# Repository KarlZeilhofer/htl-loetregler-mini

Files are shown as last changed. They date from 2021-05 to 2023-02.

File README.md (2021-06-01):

HTL Lötregler Mini
==================

Einfacher Regler für JBC Lötspitzen der Serie T210, T245 und T470, Weller RT-Spitzen und TS100-Spitzen sollten auch funktionieren.

Vorrangig SMD-Bauteile, Größe 3216. 
Bauteilauswahl für Handbestückung ohne SMD-Schablone optimiert

Design ist möglichst kostengünstig, speziell für Schüler-Budget. 

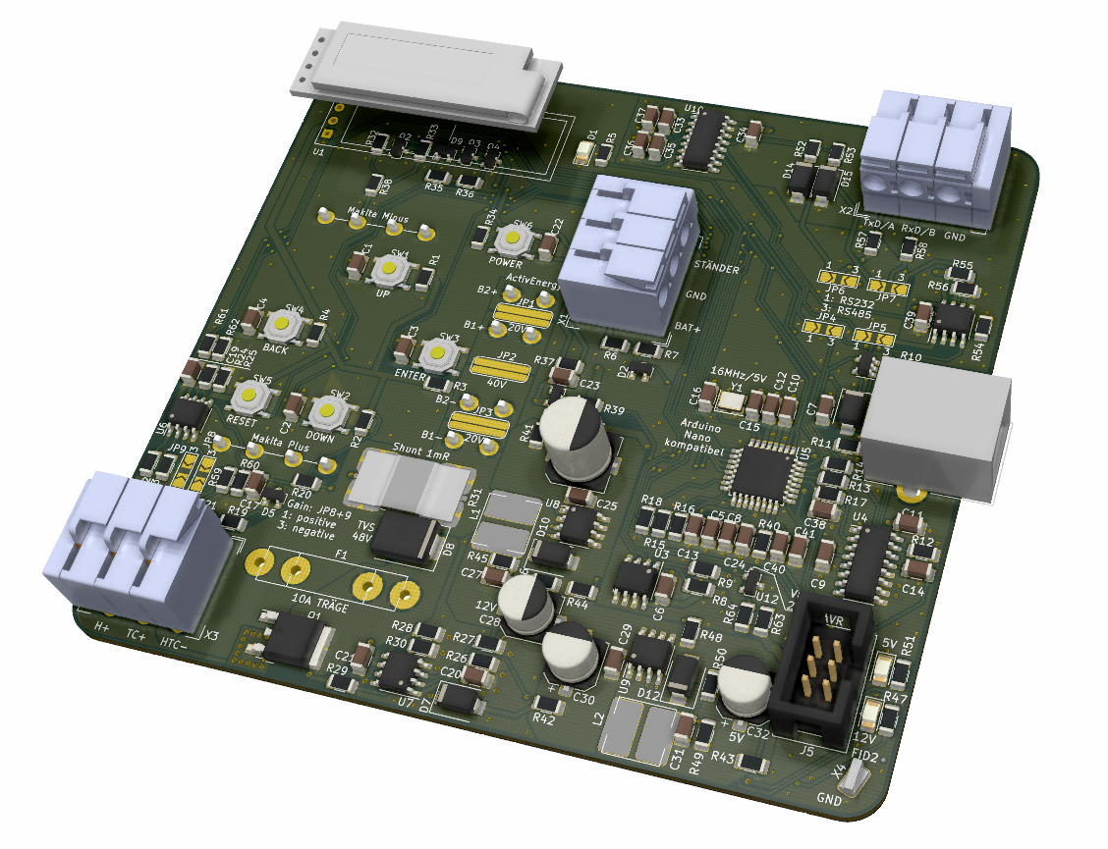
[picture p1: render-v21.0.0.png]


# Merkmale:
## Controller
* ATmega328, Kompatibel zu Arduino Nano
* 5V, 16MHz
* externe 2.5V Spannungsreferenz für ADC

## Stromversorgung
* Spannungsversorgung: 15 bis 48V, Akku oder Netzteil
* Tiefentladeschutz
* 10A Schmelzsicherung
* 48V TVS-Schutzdiode
* Ein-/Aus-Taster
* Schaltregler von Vin auf 12V und 5V
* 6.3 mm Flachsteckverbinder für die direkte Kontaktierung von 18V Makita Akkus, oder Hofer ActivEnergy Akkus mit 20 oder 40V. 

## Leistungsteil
* Highside N-Kanal MOS-FET: 80V, 10mR (geringe Verlustleistung, hohe Spannungsfestigkeit)
* zugehöriger Gatetreiber: notwendig für N-Kanal MOS-FET

## Sensorik
* Messverstärker zur Temperaturmessung der Lötspitze (24 µV/K)
* Spannungsmessung der Versorgung
* Messung der Leiterplattentemperatur
* Strommessung des Heizelements über 1mR-Shunt

## Benutzerschnittstelle
* OLED Display mit 128x32 Pixel, 23mm Diagonale
* 4 Bedientaster (Rauf, Runter, Enter, Zurück)

## Kommunikation
* Arduino USB
* AVR ISP
* Wahlweise
  * RS232
  * oder RS485 zur Kommunikation mit einem Steuerbaren Netzgerät (12, 24, 48V).

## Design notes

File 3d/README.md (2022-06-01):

3D-Druck Lötregler Mini
============

# Schichthöhe
Die Teile sind optimiert für 0.4mm Düsendurchmesser. 

# Werkstoff
Alle Teile sind in PETG gefertigt. 

Das Griffstück wäre in PC (Polycarbonat) interessant, da es nochmals um ca. 20°C temperaturbestänidger ist. 

# Gehäuse
Das Gehäuse besteht aus dem Deckel, der Wand und dem Boden. 
Beim Boden gibt es 2 Varianten: Für Activ Energy Akkus vom Hofer und für Makita Akkus. 
Entsprechend gibt es 2 Batterieaufnahmen, die mit dem Boden verklebt werden müssen. 
Für Makita empfiehlt es sich, nur die rechten Flachstecker in der Platine zu bestücken, da sich ansonsten die linken Flachstecker bei manchen Makita-Akkus beim Abziehen des Akkus in den Federkontakten im Akku verhaken. 

Die Gehäuseteile sind für 0.2mm Schichthöhe optimiert und müssen auch in dieser gedruckt werden. 

# Griffstück
Das Griffstück besteht insgesamt aus 13 Teilen, wovon 3 aus Metall sind. 
## 0.1mm Schichthöhe
  * 2 Stk griffstück_halbschale-hex_v2.stl
  * 2 Stk griffstück_halbschale-rund_v2.stl

## 0.25mm Schichthöhe
  * 2 Stk griffstück_isolator_htc-_h+_v2.2.stl
  * 1 Stk griffstück_isolator_tc+.stl
  * 1 Stk fingerkuppenring_v2.2.stl
  * 1 Stk endring_v2.1.stl
  * 1 Stk mittenring_v2.1.stl

## Edelstahl
  * 3 Stk Federkontakte

Es empfhielt sich, das Griffstück z.B. mit Polycarbonat zu drucken.

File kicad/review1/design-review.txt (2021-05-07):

Designreview:

Footprint größe
Pin-Raster
Bohrlöcherdurchmesser
Bohrlöcherposition/-abstand

Verlustleistung Widerstand
Kondensatoren: Spannungsfestigkeit
Bauform Kondensator

LED-Strom

ICs: 
Pinnamen
Pinnummern
Gehäuseform zur exakten Bestellnummer/Herstellerteilenummer

TVS-Spannungen mit Absolute Maximum Ratings vergleichen

Busverbindungen
Signalrichtungen kontrollieren
100nF Stützkondensatoren bei jedem Chip

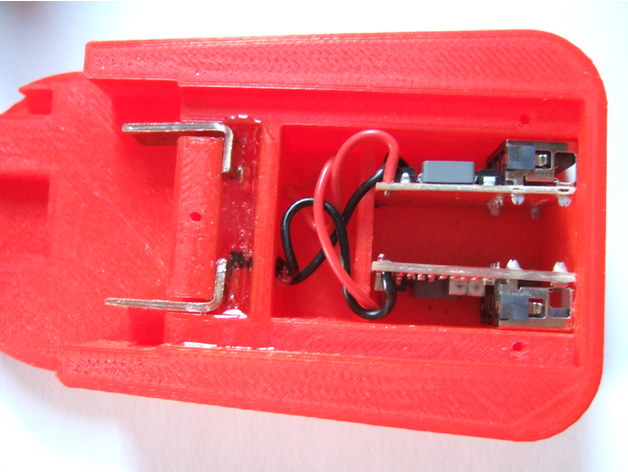
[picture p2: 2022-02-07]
3d/batterie-adapter/bosch-hobby-18v/images/8edf7b6a57a885e6059f40bedc9dee4b_preview_featured.JPG

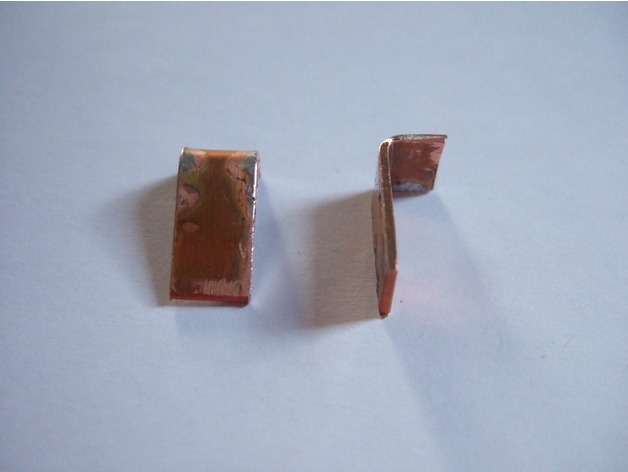
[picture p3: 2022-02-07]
3d/batterie-adapter/bosch-hobby-18v/images/e7cfda0443ac3e1c00166151be815f59_preview_featured.JPG

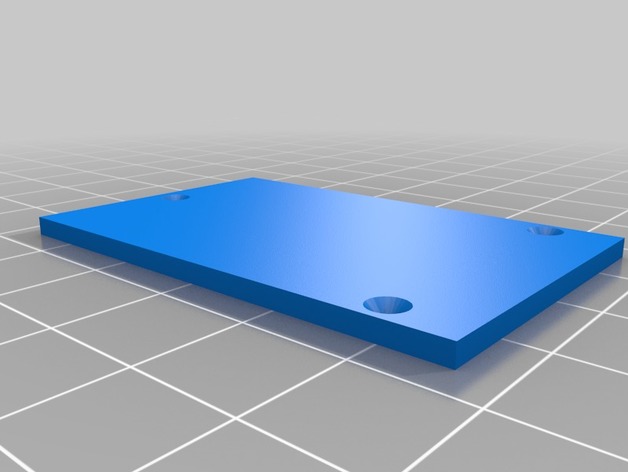
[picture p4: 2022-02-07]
3d/batterie-adapter/bosch-hobby-18v/images/c6485c41a04f16e561d70e03e1cd979a_preview_featured.jpg

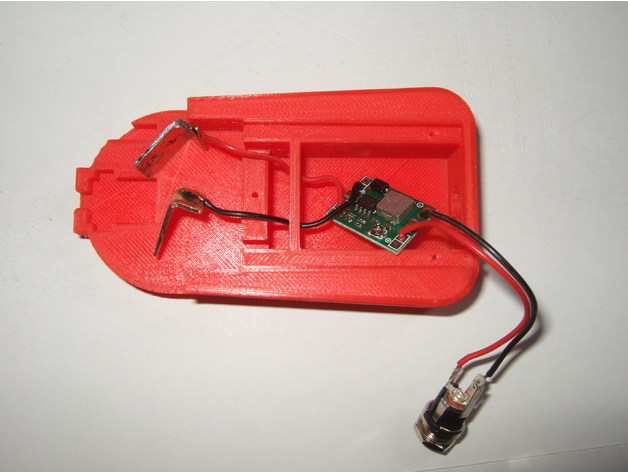
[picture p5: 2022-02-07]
3d/batterie-adapter/bosch-hobby-18v/images/e281460a45876c7f72f765fe44a80ca8_preview_featured.JPG

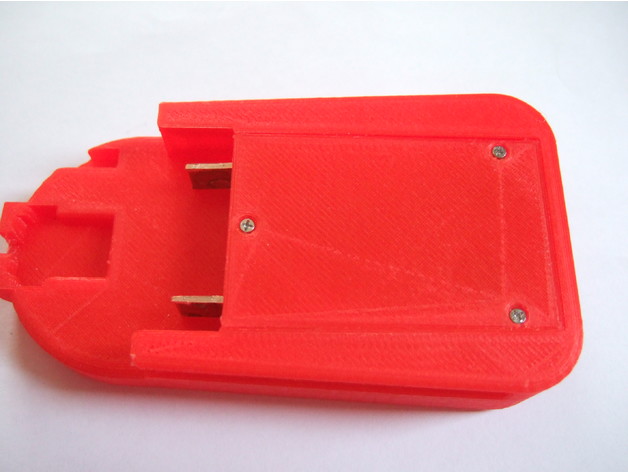
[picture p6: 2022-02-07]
3d/batterie-adapter/bosch-hobby-18v/images/b4b1a557884dc751f94c1e680981e6fe_preview_featured.JPG

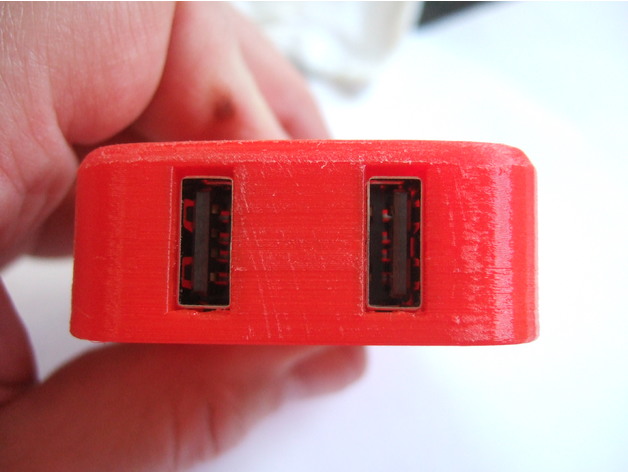
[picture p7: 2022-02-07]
3d/batterie-adapter/bosch-hobby-18v/images/e0b086893cdca43c442f52685e246c57_preview_featured.JPG

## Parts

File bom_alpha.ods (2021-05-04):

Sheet: Sheet1
Column1 | Column2 | Column3 | Column4 | Column5 | Column6 | Column7 | Column8 | Column9 | Column10 | Column11 | Column12 | Column13 | Column14 | Column15 | Quantity | Preis | Column18 | Column19 | Column20 | Column21 | Column22 | Column23 | Column24
Item2 | PCB, 1 Layer, 35um Cu, 1.6mm, ca. 100x110 | htl_virtual:Virtual-Item | ~ | Custom2 | Multi-CB | BAV99 | Multi-CB | 70V 200mA 1.25V @ 150mA 6ns SOT-23 Switching Diode |  |  | 3.71 | 100 | https://lcsc.com/product-detail/Switching-Diode_BAV99-chip0-23_C181111.html |  | 1 | 3.71 | 5.12
U1 | OLED-128x32-Module | htl_modules:OLED-128x32 | ~ | OLED_128x64_white | AliExpress, SAMIORE Store |  |  | OLED, 128x32, 23mm, I2C, 3.3/5V, weiß, SSD1306 |  |  | 1.38 | 100 | https://www.aliexpress.com/item/32672229793.html?spm=a2g0s.9042311.0.0.202b4c4d7Uzd2y |  | 1 | 1.38 | 1.90
U5 | ATmega328P-AU | Package_QFP:TQFP-32_7x7mm_P0.8mm | http://ww1.microchip.com/downloads/en/DeviceDoc/ATmega328_P%20AVR%20MCU%20with%20picoPower%20Technology%20Data%20Sheet%2040001984A.pdf | ATmega328 | MKZ | ATmega328P-AU | Microchip (ATMEL) | AVR Mikrocontroller, 16MHz, 32kByte Flash, 2kByte RAM, 1kByte EEPROM |  |  | 1 | 1 |  |  | 1 | 1 | 1.38
> C28, C30, C32 | 100u/25V | Capacitor_SMD:CP_Elec_6.3x5.9 | ~ | C320569 | LCSC | SVZ1EM101E06E00RAXXX | AISHI | 100uF ±20% 25V 6.3mm 6mm 2000hrs @ 105℃ -55℃~+105℃ SMD,6.3x6mm Solid Polymer Electrolytic Capacitor |  |  | 0.1485 | 30 | https://lcsc.com/product-detail/DC-DC-Converters_XLSEMI-XL7005A_C50848.html |  | 3 | 0.4455 | 0.61
> U8, U9 | XL7005A | htl_smd:SOIC-8-1EP_3.9x4.9mm_P1.27mm_EP2.514x3.2mm_ThermalVias | ~ | C50848 | LCSC | XL7005A | XLSEMI | 80V 400mA SOP-8_EP_150mil DC-DC Converters |  |  | 0.204 | 100 | https://lcsc.com/product-detail/DC-DC-Converters_XLSEMI-XL7005A_C50848.html |  | 2 | 0.408 | 0.56
> J1-J3 | ... | Connector_Phoenix_MSTB:PhoenixContact_MSTBA_2,5_3-G-5,08_1x03_P5.08mm_Horizontal | ~ | C475145 | LCSC | SLH0704S470MTT | Sunltech Tech | 3 poles, 5.08mm, 15A 250V AWG14~22 1.5mm² P=5.08mm Spring Clamp System Terminal Block |  |  | 0.1347 | 100 | https://lcsc.com/product-detail/Power-Inductors_Sunltech-Tech-SLH0704S470MTT_C216198.html |  | 3 | 0.4041 | 0.56
> J6-J13 | ... | htl_connectors:Faston_Tab_6.3mm_vertical | ~ | VT FS-P 6,35 | Reichelt | 03866.A68 | Vogt | Faston Flachstecker vertikal 6.3mm für Leiterplattenmontage |  |  | 0.042 | 1 |  |  | 8 | 0.336 | 0.46
U6 | GS8332-SR | Package_SO:SO-8_3.9x4.9mm_P1.27mm | http://www.ti.com/lit/ds/symlink/lm2904-n.pdf | C157713 | LCSC | GS8332-SR | Gainsil | Zero-Drift 2 2.1V ~ 5.5V 20uA 350kHz 0.2 V/us SOP-8_150mil Precision OpAmps |  |  | 0.3016 | 100 | https://lcsc.com/product-detail/Precision-OpAmps_Gainsil-GS8332-SR_C157713.html |  | 1 | 0.3016 | 0.42
R31 | 1mR/7W/1% | htl_smd:Shunt-15.2x7.6mm | ~ | C481499 | LCSC | FN31X103K500PXG | PSA(Prosperity Dielectrics) | 10nF ±10% 50V X7R Multilayer Ceramic Capacitors MLCC |  |  | 0.2596 | 100 |  |  | 1 | 0.2596 | 0.36
U4 | CH340C | Package_SO:SOIC-16_3.9x9.9mm_P1.27mm | http://www.datasheet5.com/pdf-local-2195953 | C84681 | LCSC | CH340C | WCH(Jiangsu Qin Heng) | USB-UART with internal clock |  |  | 0.239 | 100 | https://lcsc.com/product-detail/USB-ICs_WCH-Jiangsu-Qin-Heng-CH340C_C84681.html | dnf | 1 | 0.239 | 0.33
Q1 | KND3508A | Package_TO_SOT_SMD:TO-252-2 | ~ | C116513 | LCSC | KND3508A | KIA Semicon Tech | 100uF ±20% 25V 6.3mm 6mm 2000hrs @ 105℃ -55℃~+105℃ SMD,6.3x6mm Solid Polymer Electrolytic Capacitor |  |  | 0.226 | 100 | https://lcsc.com/product-detail/MOSFET_KIA-Semicon-Tech-KND3508A_C116513.html |  | 1 | 0.226 | 0.31
Q5 | ZXMP10A13FTA | Package_TO_SOT_SMD:SOT-23 | http://assets.nexperia.com/documents/data-sheet/BSS84.pdf | C50185 | LCSC | ZXMP10A13FTA | Diodes | P-Channel -100V 600mA 4V @ 250uA 1Ω @ 600mA,10V 625mW SOT-23(SOT-23-3) MOSFET |  |  | 0.2191 | 100 | https://lcsc.com/product-detail/Cartridge-Fuses_Littelfuse-0618010-MXP_C142673.html |  | 1 | 0.2191 | 0.30
U7 | PN7006A | Package_SO:SOIC-8_3.9x4.9mm_P1.27mm |  | C414194 | LCSC |  |  | SOP-8 half bridge Driver, 300V, 450mA |  |  | 0.2188 | 100 | https://lcsc.com/product-detail/Full-bridge-half-bridge-Driver_Wuxi-Chipown-Micro-electronics-PN7006ASEC-R1_C414194.html |  | 1 | 0.2188 | 0.30
U10 | MAX3232 | Package_SO:SOIC-16_3.9x9.9mm_P1.27mm | https://datasheets.maximintegrated.com/en/ds/MAX3222-MAX3241.pdf | C434486 | LCSC | MAX3232EIM/TR | HGSEMI | RS232 - UART Umsetzer, 3V3 oder 5V |  |  | 0.188404 | 100 | https://lcsc.com/product-detail/Uncategorized_HGSEMI-MAX3232EIM-TR_C434486.html |  | 1 | 0.188404 | 0.26
> L1, L2 | 47u/1A | Inductor_SMD:L_7.3x7.3_H4.5 | ~ | C216198 | LCSC | SLH0704S470MTT | Sunltech Tech | 47uH ±20% 1A 266mΩ SMD,7.3x7.3x4.5mm |  |  | 0.085 | 100 | https://lcsc.com/product-detail/Power-Inductors_Sunltech-Tech-SLH0704S470MTT_C216198.html |  | 2 | 0.17 | 0.23
Item1 | Stencil, 120um, 25mm Rand, Edelstahl | htl_virtual:Virtual-Item | ~ | Custom1 | Multi-CB | 2N7002 | Multi-CB | N-Channel 60V 115mA 2.5V @ 250uA 5Ω @ 500mA,10V 225mW SOT-23(SOT-23-3) MOSFET |  |  | 0.1656 | 100 | https://lcsc.com/product-detail/MOSFET_Guangdong-Hottech-2N7002_C181082.html |  | 1 | 0.1656 | 0.23
> C1-C6, C8, C9, C11, C14, C17, C19, C33-C37 | 100n | Capacitor_SMD:C_1206_3216Metric | ... | C464972 | LCSC | FN31X104K500PXG | PSA(Prosperity Dielectrics) | 100nF ±10% 50V X7R Multilayer Ceramic Capacitors MLCC |  |  | 0.0093 | 500 | ... |  | 17 | 0.1581 | 0.22
> R1-R4, R6, R7, R21, R30, R32-R34, R39, R49 | 10k | Resistor_SMD:R_1206_3216Metric | ~ | C118075 | LCSC | GS8332-SR | Gainsil | SOP-8 half bridge Driver, 300V, 450mA |  |  | 0.01 | 100 | https://lcsc.com/product-detail/Full-bridge-half-bridge-Driver_Wuxi-Chipown-Micro-electronics-PN7006ASEC-R1_C414194.html |  | 13 | 0.13 | 0.18
D8 | SMCJ48A | Diode_SMD:D_SMC | ~ | C310056 | LCSC | KND3508A | KIA Semicon Tech | TVS-Diode, 1500W, 77.4V, 19.4A |  |  | 0.12 | 100 | https://lcsc.com/product-detail/TVS_Brightking-Elec-TAIWAN-SMCJ48A_C310056.html |  | 1 | 0.12 | 0.17
> C7, C10, C12, C13, C21 | 1u | Capacitor_SMD:C_1206_3216Metric | ~ | C1848 | LCSC | CL31B105KBHNNNE | Samsung | 1uF ±10% 50V X7R Multilayer Ceramic Capacitors MLCC |  |  | 0.0225 | 100 | ... |  | 5 | 0.1125 | 0.16
U3 | NST175 | Package_SO:SO-8_3.9x4.9mm_P1.27mm | ~ | C967852 | LCSC | SS210A-W | ZHIDE | digital temperature sensor, +/-0.5°C, I2C |  |  | 0.096 | 10 | https://lcsc.com/product-detail/Temperature-Sensors_NOVOSENSE-NST175-QSPR_C967852.html |  | 1 | 0.096 | 0.13
Y1 | 16MHz | Crystal:Crystal_SMD_3225-4Pin_3.2x2.5mm | ~ | C357882 | LCSC | JYXT32S4-016.00000-93C4C0 | Guangzhou Jingyou Electronic Tech | 16MHz ±10ppm 12pF 40Ω SMD-3225 SMD Crystal Resonators |  |  | 0.0884 | 50 |  |  | 1 | 0.0884 | 0.12
> R8-R10, R35, R46, R47, R50, R51 | 3k3 | Resistor_SMD:R_1206_3216Metric | ~ | C229599 | LCSC | FN31X104K500PXG | PSA(Prosperity Dielectrics) | 100nF ±10% 50V X7R Multilayer Ceramic Capacitors MLCC |  |  | 0.01 | 500 | ... |  | 8 | 0.08 | 0.11
J4 | USB_B | Connector_USB:USB_B_Lumberg_2411_02_Horizontal | ~ | C46392 | LCSC | 921-111A1010D10200 | Jing Extension of the Electronic Co. | USB - Type B Female USB 2.0 4 Through Hole USB Connectors |  |  | 0.0777 | 5 |  |  | 1 | 0.0777 | 0.11
J5 | AVR ISP | Connector_IDC:IDC-Header_2x03_P2.54mm_Vertical | ~ | C132438 | LCSC |  |  | Wannenstecker 2x3 Pins, 2.54mm Raster, vertikal |  |  | 0.0698 | 50 |  |  | 1 | 0.0698 | 0.10
C26 | 100u/63V | Capacitor_SMD:CP_Elec_8x10 | ~ | C487384 | LCSC | VKMD1001J101MV | Ymin | 100uF ±20% 63V 8mm 10mm 902mA @ 100kHz 10000hrs @ 105℃ -55℃~+105℃ SMD,8x10mm Aluminum Electrolytic Capacitors |  |  | 0.0698 | 150 | ... |  | 1 | 0.0698 | 0.10
> D4, D7, D10, D12 | SS210 | Diode_SMD:D_SMA | ~ | C2683692 | LCSC | SS210A-W | ZHIDE | 100V 2A 850mV @ 2A SMA(DO-214AC) Schottky Barrier Diodes |  |  | 0.0155 | 200 | ... |  | 4 | 0.062 | 0.09
> SW1-SW6 | ... | htl_smd:SW_Push_5.1mm_H1.5mm | ~ | C318884 | LCSC | TS-1187A-B-A-B | XKB Connectivity | SPST 50mA @ 12VDC Vertical Round Button 160gf SMD Tactile Switches |  |  | 0.01 | 500 | https://lcsc.com/product-detail/Tactile-Switches_XKB-Connectivity-TS-1187A-B-A-B_C318884.html |  | 6 | 0.06 | 0.08
Item4 | Sicherung, 5x20, 10A, träge | htl_virtual:Virtual-Item | ~ | C142673 | LCSC | 0618010.MXP | Littelfuse | Glass Tube Fuse Delayed blow/Slow Blow 10A 250V Tube,5.2x20mm Cartridge Fuses |  |  | 0.0544 | 100 | https://lcsc.com/product-detail/Cartridge-Fuses_Littelfuse-0618010-MXP_C142673.html | ... | 1 | 0.0544 | 0.08
> D14, D15 | SMAJ8.0CA | Diode_SMD:D_SMA | ~ | C908814 | LCSC | SMAJ8.0CA | GOODWORK | Bidirectional 8V 8.89V 13.6V 29.4A SMA(DO-214AC) TVS |  |  | 0.0243 | 100 | https://lcsc.com/product-detail/Pre-ordered-transistors_GOODWORK-SMAJ8-0CA_C908814.html |  | 2 | 0.0486 | 0.07
> C15, C16 | 12p | Capacitor_SMD:C_1206_3216Metric | ~ | C113882 | LCSC | CC1206JRNPO9BN120 | YAGEO | 12pF NP0 Keramikkonensator |  |  | 0.024 | 20 |  |  | 2 | 0.048 | 0.07
> C20, C24 | 10u/16V | Capacitor_SMD:C_1206_3216Metric | ~ | C47971 | LCSC | CL31B106KOHNNNE | Samsung | 10uF ±10% 16V X7R Multilayer Ceramic Capacitors MLCC |  |  | 0.0233 | 100 |  |  | 2 | 0.0466 | 0.06
> R5, R11, R13, R17, R20, R26-R28, R36, R38, R40 | 1k | Resistor_SMD:R_1206_3216Metric | ... | C104601 | LCSC | RTT03101JTP | RALEC | 1kΩ ±5% 0.25W ±100ppm/℃ 1206 Chip Resistor |  |  | 0.0042 | 50 | ... |  | 11 | 0.0462 | 0.06
> R12, R14-R16, R18, R23, R25, R29, R44, R48, R52, R53 | 100R | Resistor_SMD:R_1206_3216Metric | ... | C113307 | LCSC | RC1206JR-07100RL | YAGEO | 100Ω ±5% 0.25W ±100ppm/℃ 1206 Chip Resistor |  |  | 0.0037 | 500 | ... |  | 12 | 0.0444 | 0.06
U2 | 74LVC1G125 | Package_TO_SOT_SMD:SOT-23-5 | http://www.ti.com/lit/sg/scyt129e/scyt129e.pdf | C23654 | LCSC |  |  | digital temperature sensor, +/-0.5°C, I2C |  |  | 0.044 | 100 | https://lcsc.com/product-detail/Temperature-Sensors_NOVOSENSE-NST175-QSPR_C967852.html |  | 1 | 0.044 | 0.06
> R22, R24, R45 | 30k | Resistor_SMD:R_1206_3216Metric | ~ | C137314 | LCSC | VKMD1001J101MV | Ymin | 100uF ±20% 63V 8mm 10mm 902mA @ 100kHz 10000hrs @ 105℃ -55℃~+105℃ SMD,8x10mm Aluminum Electrolytic Capacitors |  |  | 0.01 | 150 |  |  | 3 | 0.03 | 0.04
> R41-R43 | 1R | Resistor_SMD:R_1206_3216Metric | ~ | C17928 | LCSC | SMAJ8.0CA | GOODWORK | Bidirectional 8V 8.89V 13.6V 29.4A SMA(DO-214AC) TVS |  |  | 0.01 | 100 | https://lcsc.com/product-detail/Pre-ordered-transistors_GOODWORK-SMAJ8-0CA_C908814.html |  | 3 | 0.03 | 0.04
> C27, C31 | 33n | Capacitor_SMD:C_1206_3216Metric | ~ | C309052 | LCSC | TCC1206X7R333K500DT | CCTC | P-Channel -100V 600mA 4V @ 250uA 1Ω @ 600mA,10V 625mW SOT-23(SOT-23-3) MOSFET |  |  | 0.0144 | 50 |  |  | 2 | 0.0288 | 0.04
> C25, C29 | 100n/100V | Capacitor_SMD:C_1206_3216Metric | ~ | C1945 | LCSC | CL31B104KCFNNNE | Samsung Electro-Mechanics | 100nF ±10% 100V X7R Multilayer Ceramic Capacitors MLCC |  |  | 0.014 | 200 |  |  | 2 | 0.028 | 0.04
> F1, Item3 | Clip 20x5 | ... | ~ | C182320 | LCSC | LS-502 | Shenzhen lanson Elec | Sicherungshalter, 2 Stück pro Sicherung |  |  | 0.0132 | 200 | https://lcsc.com/product-detail/Fuse-Holders_Shenzhen-lanson-Elec-LS-502_C182320.html |  | 2 | 0.0264 | 0.04
> D2, D5, D6 | BAV99 | Package_TO_SOT_SMD:SOT-23 | https://assets.nexperia.com/documents/data-sheet/BAV99_SER.pdf | C181111 | LCSC | BAV99 | Guangdong Hottech | 70V 200mA 1.25V @ 150mA 6ns SOT-23 Switching Diode |  |  | 0.0073 | 500 | https://lcsc.com/product-detail/Switching-Diode_BAV99-chip0-23_C181111.html |  | 3 | 0.0219 | 0.03
> C18, C23 | 10n | Capacitor_SMD:C_1206_3216Metric | ~ | C525316 | LCSC | FN31X103K500PXG | PSA(Prosperity Dielectrics) | 10nF ±10% 50V X7R Multilayer Ceramic Capacitors MLCC |  |  | 0.0106 | 500 | ... |  | 2 | 0.0212 | 0.03
> D3, D11, D13 | grün | LED_SMD:LED_1206_3216Metric | ~ | C965825 | LCSC | RC1206JR-07100RL | YAGEO | 100Ω ±5% 0.25W ±100ppm/℃ 1206 Chip Resistor |  |  | 0.0067 | 50 | https://lcsc.com/product-detail/Pre-ordered-Products_XINGLIGHT-XL-3216UGC_C965825.html |  | 3 | 0.0201 | 0.03
> R19, R37 | 100k | Resistor_SMD:R_1206_3216Metric | ~ | C269765 | LCSC |  |  | TVS-Diode, 1500W, 77.4V, 19.4A |  |  | 0.01 | 100 | https://lcsc.com/product-detail/TVS_Brightking-Elec-TAIWAN-SMCJ48A_C310056.html |  | 2 | 0.02 | 0.03
> Q3, Q4 | MMBT3904 | Package_TO_SOT_SMD:SOT-23 | https://www.fairchildsemi.com/datasheets/2N/2N3904.pdf | C382281 | LCSC |  |  | Wannenstecker 2x3 Pins, 2.54mm Raster, vertikal |  |  | 0.0097 | 50 | https://lcsc.com/product-detail/Transistors-NPN-PNP_KEXIN-MMBT3904_C382281.html |  | 2 | 0.0194 | 0.03
D9 | 4V7 | Diode_SMD:D_SOT-23_ANK | https://diotec.com/tl_files/diotec/files/pdf/datasheets/bzx84c2v4.pdf | C12727 | LCSC | CC1206JRNPO9BN120 | YAGEO | 4.7V 225mW 3uA @ 2V SOT-23(SOT-23-3) Zener Diodes |  |  | 0.014 | 50 |  |  | 1 | 0.014 | 0.02
C22 | 1n/100V | Capacitor_SMD:C_1206_3216Metric | ~ | C398254 | LCSC | C1206X102K101T | IHHEC(HOLY STONE ENTERPRISE CO., LTD) | 1nF ±10% 100V X7R Multilayer Ceramic Capacitors MLCC |  |  | 0.0123 | 50 | https://lcsc.com/product-detail/Tactile-Switches_XKB-Connectivity-TS-1187A-B-A-B_C318884.html |  | 1 | 0.0123 | 0.02
Q2 | 2N7002 | Package_TO_SOT_SMD:SOT-23 | https://www.fairchildsemi.com/datasheets/2N/2N7002.pdf | C181082 | LCSC | 2N7002 | Guangdong Hottech | N-Channel 60V 115mA 2.5V @ 250uA 5Ω @ 500mA,10V 225mW SOT-23(SOT-23-3) MOSFET |  |  | 0.0122 | 50 | https://lcsc.com/product-detail/MOSFET_Guangdong-Hottech-2N7002_C181082.html |  | 1 | 0.0122 | 0.02
D1 | rot | LED_SMD:LED_1206_3216Metric | ~ | C965823 | LCSC | CH340C | WCH(Jiangsu Qin Heng) | LED, green, SMD3216 |  |  | 0.0079 | 50 | https://lcsc.com/product-detail/USB-ICs_WCH-Jiangsu-Qin-Heng-CH340C_C84681.html |  | 1 | 0.0079 | 0.01
> FID1, FID2 | Fiducial | htl_mechanical:paste-fiducial | ~ | NAP1 | NAP | 0618010.MXP | Not a Part | Glass Tube Fuse Delayed blow/Slow Blow 10A 250V Tube,5.2x20mm Cartridge Fuses |  |  | 0 | 100 | https://lcsc.com/product-detail/Cartridge-Fuses_Littelfuse-0618010-MXP_C142673.html |  | 2 | 0 | 0.00
> H1-H4 | MountingHole | htl_mechanical:mountinghole_d4mm_R5mm | ~ | NAP2 | NAP | NAP | NAP | Not a Part |  |  | 0 | 100 | https://lcsc.com/product-detail/Precision-OpAmps_Gainsil-GS8332-SR_C157713.html |  | 4 | 0 | 0.00
> JP1-JP3 | ... | Jumper:SolderJumper-2_P1.3mm_Open_RoundedPad1.0x1.5mm | ~ | NAP3 | NAP | 921-111A1010D10200 | Jing Extension of the Electronic Co. | TVS-Diode, 1500W, 77.4V, 19.4A |  |  | 0 | 100 | https://lcsc.com/product-detail/TVS_Brightking-Elec-TAIWAN-SMCJ48A_C310056.html |  | 3 | 0 | 0.00

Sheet: Sheet2
LCSC | Stück | Stück für 10 PCBs
C104601 | 11 | 110
C113307 | 12 | 120
C113882 | 2 | 20
C116513 | 1 | 10
C118075 | 13 | 130
C12727 | 1 | 10
C132438 | 1 | 10
C137314 | 3 | 30
C142673 | 1 | 10
C157713 | 1 | 10
C17928 | 3 | 30
C181082 | 1 | 10
C181111 | 3 | 30
C182320 | 2 | 20
C1848 | 5 | 50
C1945 | 2 | 20
C216198 | 2 | 20
C229599 | 8 | 80
C23654 | 1 | 10
C2683692 | 4 | 40
C269765 | 2 | 20
C309052 | 2 | 20
C310056 | 1 | 10
C318884 | 6 | 60
C320569 | 3 | 30
C357882 | 1 | 10
C382281 | 2 | 20
C398254 | 1 | 10
C414194 | 1 | 10
C434486 | 1 | 10
C46392 | 1 | 10
C464972 | 17 | 170
C475145 | 3 | 30
C47971 | 2 | 20
C481499 | 1 | 10
C487384 | 1 | 10
C50185 | 1 | 10
C50848 | 2 | 20
C525316 | 2 | 20
C84681 | 1 | 10
C908814 | 2 | 20
C965823 | 1 | 10
C965825 | 3 | 30
C967852 | 1 | 10

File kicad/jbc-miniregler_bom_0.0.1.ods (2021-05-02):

Component | Description | Part | References | Value | Footprint | Quantity Per PCB | Datasheet | DistOrderNr | Distributor | Notes | PriceEUR | PriceForQty | ManPartNr | Manufacturer | fit_field | Weblink | PreisGesBrutto
21 | Virtual Item for accessories which should be listed in the BOM | Item | Item2 | PCB, 1 Layer, 35um Cu, 1.6mm, ca. 100x110 | Virtual-Item | 1 | ~ | Custom | Multi-CB |  | 3.71 | 100 |  | Multi-CB |  |  | 512
1 | Arduino Nano v3.x | Arduino_Nano_v3.x | A1 | Arduino_Nano_v3.x | Arduino_Nano | 1 | http://www.mouser.com/pdfdocs/Gravitech_Arduino_Nano3_0.pdf | 232861246013 | eBay | Arduino Nano v3.x | 2.6 | 50 |  |  |  |  | 359
48 |  | OLED-128x32-Module | U1 | OLED-128x32-Module | OLED-128x32 | 1 |  | OLED_128x64_white | AliExpress, SAMIORE Store | OLED, 128x32, 23mm, I2C, 3.3/5V, weiß, SSD1306 | 1.38 | 100 |  |  |  | https://www.aliexpress.com/item/32672229793.html?spm=a2g0s.9042311.0.0.202b4c4d7Uzd2y | 190
7 | Polarized capacitor | CP | C17 C21 | 100u/25V | TODO | 2 | ~ | C454667 | LCSC | 100uF ±20% 25V 7.7mm 8mm 2A @ 100kHz 30mΩ @ 100kHz 10000hrs @ 105℃ -55℃~+105℃ SMD,7.7x8mm Solid Polymer Electrolytic Capacitor | 0.4258 | 100 | EEHZA1E101XV | Panasonic |  |  | 118
50 | Tiefsetzsteller, 80V, 400mA, 85% Wirkungsgrad | XL7005A | U6 U7 | XL7005A | SOIC-8-1EP_3.9x4.9mm_P1.27mm_EP2.514x3.2mm_ThermalVias | 2 |  | C50848 | LCSC | 80V 400mA SOP-8_EP_150mil DC-DC Converters | 0.204 | 100 | XL7005A | XLSEMI |  | https://lcsc.com/product-detail/DC-DC-Converters_XLSEMI-XL7005A_C50848.html | 56
45 | Low-Power, Dual Operational Amplifiers, DIP-8/SOIC-8/TO-99-8 | LM358 | U4 | GS8332-SR | SO-8_3.9x4.9mm_P1.27mm | 1 | http://www.ti.com/lit/ds/symlink/lm2904-n.pdf | C157713 | LCSC | Zero-Drift 2 2.1V ~ 5.5V 20uA 350kHz 0.2 V/us SOP-8_150mil Precision OpAmps | 0.3016 | 100 | GS8332-SR | Gainsil |  | https://lcsc.com/product-detail/Precision-OpAmps_Gainsil-GS8332-SR_C157713.html | 42
24 | Generic screw terminal, single row, 01x03, script generated (kicad-library-utils/schlib/autogen/connector/) | Screw_Terminal_01x03 | J2 J3 | COM | PhoenixContact_MSTBA_2,5_3-G-5,08_1x03_P5.08mm_Horizontal | 2 | ~ | C475145 | LCSC | 3 poles, 5.08mm, 15A 250V AWG14~22 1.5mm² P=5.08mm Spring Clamp System Terminal Block | 0.1347 | 100 |  |  |  |  | 37
38 | Shunt resistor | R_Shunt | R19 | 1mR/7W/1% | Shunt-15.2x7.6mm | 1 | ~ | C481499 | LCSC |  | 0.2596 | 100 |  |  |  |  | 36
28 | N-MOSFET transistor, gate/drain/source | Q_NMOS_GDS | Q1 | KND3508A | TO-252-2 | 1 | ~ | C116513 | LCSC |  | 0.226 | 100 | KND3508A | KIA Semicon Tech |  | https://lcsc.com/product-detail/MOSFET_KIA-Semicon-Tech-KND3508A_C116513.html | 31
30 | -0.13A Id, -50V Vds, P-Channel MOSFET, SOT-23 | BSS84 | Q5 | ZXMP10A13FTA | SOT-23 | 1 | http://assets.nexperia.com/documents/data-sheet/BSS84.pdf | C50185 | LCSC | P-Channel -100V 600mA 4V @ 250uA 1Ω @ 600mA,10V 625mW SOT-23(SOT-23-3) MOSFET | 0.2191 | 100 | ZXMP10A13FTA | Diodes |  |  | 30
49 | Half Bridge Driver, 2 Inputs, 300V, 3.3V Inputs | PN7006A | U5 | PN7006A | SOIC-8_3.9x4.9mm_P1.27mm | 1 |  | C414194 | LCSC | SOP-8 half bridge Driver, 300V, 450mA | 0.2188 | 100 |  |  |  | https://lcsc.com/product-detail/Full-bridge-half-bridge-Driver_Wuxi-Chipown-Micro-electronics-PN7006ASEC-R1_C414194.html | 30
46 | 3.0V to 5.5V, Low-Power, up to 1Mbps, True RS-232 Transceivers Using Four 0.1μF External Capacitors | MAX3232 | U8 | MAX3232 | SOIC-16_3.9x9.9mm_P1.27mm | 1 | https://datasheets.maximintegrated.com/en/ds/MAX3222-MAX3241.pdf | C434486 | LCSC | RS232 - UART Umsetzer, 3V3 oder 5V | 0.188404 | 100 | MAX3232EIM/TR | HGSEMI |  | https://lcsc.com/product-detail/Uncategorized_HGSEMI-MAX3232EIM-TR_C434486.html | 26
26 | Inductor symbol for simulation only | INDUCTOR | L1 L2 | 47u/1A | L_7.3x7.3_H4.5_TODO | 2 | ~ | C216198 | LCSC | 47uH ±20% 1A 266mΩ SMD,7.3x7.3x4.5mm | 0.085 | 100 | SLH0704S470MTT | Sunltech Tech |  | https://lcsc.com/product-detail/Power-Inductors_Sunltech-Tech-SLH0704S470MTT_C216198.html | 23
23 | Virtual Item for accessories which should be listed in the BOM | Item | Item1 | Stencil, 120um, 25mm Rand, Edelstahl | Virtual-Item | 1 | ~ | Custom | Multi-CB |  | 0.1656 | 100 |  | Multi-CB |  |  | 23
14 | Diode zener | DiodeTVS | D4 | SMCJ48A | D_SMC | 1 |  | C310056 | LCSC | TVS-Diode, 1500W, 77.4V, 19.4A | 0.12 | 100 |  |  |  | https://lcsc.com/product-detail/TVS_Brightking-Elec-TAIWAN-SMCJ48A_C310056.html | 17
35 | Resistor | R | R1 R2 R3 R4 R6 R9 R18 R20 R21 R22 R27 R37 | 10k | R_1206_3216Metric | 12 | ~ |  |  |  | 0.01 |  |  |  |  |  | 17
25 | Generic screw terminal, single row, 01x02, script generated (kicad-library-utils/schlib/autogen/connector/) | Screw_Terminal_01x02 | J1 | Power IN | PhoenixContact_MSTBA_2,5_2-G-5,08_1x02_P5.08mm_Horizontal | 1 | ~ | C475144 | LCSC | 2 poles, 5.08mm, 15A 250V AWG14~22 1.5mm² P=5.08mm Spring Clamp System Terminal Block | 0.1172 | 100 |  |  |  |  | 16
4 | Unpolarized capacitor | C | C1 C2 C3 C4 C5 C8 C22 C23 C24 C25 C26 | 100n | C_1206_3216Metric | 11 | ~ | C464972 | LCSC | 100nF ±10% 50V X7R Multilayer Ceramic Capacitors MLCC | 0.0093 | 500 | FN31X104K500PXG | PSA(Prosperity Dielectrics) |  |  | 14
47 |  | NST175 | U3 | NST175 | SO-8_3.9x4.9mm_P1.27mm | 1 |  | C967852 | LCSC | digital temperature sensor, +/-0.5°C, I2C | 0.096 | 10 |  |  |  | https://lcsc.com/product-detail/Temperature-Sensors_NOVOSENSE-NST175-QSPR_C967852.html | 13
34 | Resistor | R | R7 R8 R10 R23 R34 R35 R38 R39 | 3k3 | R_1206_3216Metric | 8 | ~ |  |  |  | 0.01 |  |  |  |  |  | 11
32 | Resistor | R | R12 R17 R32 R36 R40 R41 R?R1 | 100R | R_1206_3216Metric | 7 | ~ |  |  |  | 0.01 |  |  |  |  |  | 10
33 | Resistor | R | R5 R14 R15 R16 R24 R26 R28 | 1k | R_1206_3216Metric | 7 | ~ |  |  |  | 0.01 |  |  |  |  |  | 10
8 | Polarized capacitor | CP | C15 | 100u/63V | CP_Elec_8x10 | 1 | ~ | C487384 | LCSC | 100uF ±20% 63V 8mm 10mm 902mA @ 100kHz 10000hrs @ 105℃ -55℃~+105℃ SMD,8x10mm Aluminum Electrolytic Capacitors | 0.0698 | 150 | VKMD1001J101MV | Ymin |  |  | 10
22 | Fuse | Fuse | Item4 | Sicherung, 5x20, 10A, träge | Virtual-Item | 1 | ~ | C142673 | LCSC | Glass Tube Fuse Delayed blow/Slow Blow 10A 250V Tube,5.2x20mm Cartridge Fuses | 0.0544 | 100 | 0618010.MXP | Littelfuse |  | https://lcsc.com/product-detail/Cartridge-Fuses_Littelfuse-0618010-MXP_C142673.html | 8
13 | Diode zener | DiodeTVS_Bidirek | D10 D11 | SMAJ8.0CA | D_SMA | 2 |  | C908814 | LCSC | Bidirectional 8V 8.89V 13.6V 29.4A SMA(DO-214AC) TVS | 0.0243 | 100 | SMAJ8.0CA | GOODWORK |  | https://lcsc.com/product-detail/Pre-ordered-transistors_GOODWORK-SMAJ8-0CA_C908814.html | 7
9 | Unpolarized capacitor | C | C9 C13 | 10u/16V | C_1206_3216Metric | 2 | ~ | C47971 | LCSC | 10uF ±10% 16V X7R Multilayer Ceramic Capacitors MLCC | 0.0233 | 100 | CL31B106KOHNNNE | Samsung |  |  | 6
44 | Single Buffer Gate Tri-State, Low-Voltage CMOS | 74LVC1G125 | U2 | 74LVC1G125 | SOT-23-5 | 1 | http://www.ti.com/lit/sg/scyt129e/scyt129e.pdf | C23654 | LCSC |  | 0.044 | 100 |  |  |  |  | 6
2 | Unpolarized capacitor | C | C6 C7 C12 | 10n | C_1206_3216Metric | 3 | ~ | C525316 | LCSC | 10nF ±10% 50V X7R Multilayer Ceramic Capacitors MLCC | 0.0106 | 500 | FN31X103K500PXG | PSA(Prosperity Dielectrics) |  |  | 4
16 | Schottky diode | D_Schottky | D6 D8 | SS210 | D_SMA | 2 | ~ | C2683692 | LCSC | 100V 2A 850mV @ 2A SMA(DO-214AC) Schottky Barrier Diodes | 0.0155 | 200 | SS210A-W | ZHIDE |  | https://lcsc.com/product-detail/Schottky-Barrier-Diodes-SBD_ZHIDE-SS210A-W_C2683692.html | 4
31 | Resistor | R | R29 R30 R31 | 1R | R_1206_3216Metric | 3 | ~ |  |  |  | 0.01 |  |  |  |  |  | 4
36 | Resistor | R | R11 R13 R33 | 30k | R_1206_3216Metric | 3 | ~ |  |  |  | 0.01 |  |  |  |  |  | 4
3 | Unpolarized capacitor | C | C16 C20 | 33n | C_1206_3216Metric | 2 | ~ | C309052 | LCSC |  | 0.0144 | 50 | TCC1206X7R333K500DT | CCTC |  |  | 4
6 | Unpolarized capacitor | C | C14 C18 | 100n/100V | C_1206_3216Metric | 2 | ~ | C1945 | LCSC | 100nF ±10% 100V X7R Multilayer Ceramic Capacitors MLCC | 0.014 | 200 | CL31B104KCFNNNE | Samsung Electro-Mechanics |  |  | 4
5 | Unpolarized capacitor | C | C10 | 1u | C_1206_3216Metric | 1 | ~ | C1848 | LCSC | 1uF ±10% 50V X7R Multilayer Ceramic Capacitors MLCC | 0.0225 | 100 | CL31B105KBHNNNE | Samsung |  |  | 3
29 | 0.2A Ic, 40V Vce, Small Signal NPN Transistor, SOT-23 | MMBT3904 | Q3 Q4 | MMBT3904 | SOT-23 | 2 | https://www.fairchildsemi.com/datasheets/2N/2N3904.pdf | C382281 | LCSC |  | 0.0097 | 50 |  |  |  | https://lcsc.com/product-detail/Transistors-NPN-PNP_KEXIN-MMBT3904_C382281.html | 3
15 | Schottky diode | D_Schottky | D3 | SS210 | D_SMA | 1 | ~ | C2683692 | LCSC | 100V 2A 850mV @ 2A SMA(DO-214AC) Schottky Barrier Diodes | 0.0155 | 200 | SS210A-W | ZHIDE |  | https://lcsc.com/product-detail/Schottky-Barrier-Diodes-SBD_ZHIDE-SS210A-W_C2683692.html | 2
11 | 300mW Zener Diode, SOT-23 | BZX84Cxx | D5 | 4V7 | D_SOT-23_ANK | 1 | https://diotec.com/tl_files/diotec/files/pdf/datasheets/bzx84c2v4.pdf | C12727 | LCSC | 4.7V 225mW 3uA @ 2V SOT-23(SOT-23-3) Zener Diodes | 0.014 | 50 |  |  |  |  | 2
17 | Light emitting diode | LED | D7 D9 | grün | LED_1206_3216Metric | 2 | ~ | C965825 | LCSC |  | 0.0067 | 50 |  |  |  | https://lcsc.com/product-detail/Pre-ordered-Products_XINGLIGHT-XL-3216UGC_C965825.html | 2
19 | Fuse | Fuse | F1 | Clip 20x5 | fuse-clip_20x5mm | 1 | ~ | C182320 | LCSC | Sicherungshalter, 2 Stück pro Sicherung | 0.0132 | 200 | LS-502 | Shenzhen lanson Elec |  | https://lcsc.com/product-detail/Fuse-Holders_Shenzhen-lanson-Elec-LS-502_C182320.html | 2
20 | Fuse | Fuse | Item3 | Clip 20x5 | Virtual-Item | 1 | ~ | C182320 | LCSC | Sicherungshalter, 2 Stück pro Sicherung | 0.0132 | 200 | LS-502 | Shenzhen lanson Elec |  | https://lcsc.com/product-detail/Fuse-Holders_Shenzhen-lanson-Elec-LS-502_C182320.html | 2
10 | Unpolarized capacitor | C | C11 | 1n/100V | C_1206_3216Metric | 1 | ~ | C398254 | LCSC | 1nF ±10% 100V X7R Multilayer Ceramic Capacitors MLCC | 0.0123 | 50 | C1206X102K101T | IHHEC(HOLY STONE ENTERPRISE CO., LTD) |  |  | 2
27 | 0.115A Id, 60V Vds, N-Channel MOSFET, SOT-23 | 2N7002 | Q2 | 2N7002 | SOT-23 | 1 | https://www.fairchildsemi.com/datasheets/2N/2N7002.pdf | C181082 | LCSC | N-Channel 60V 115mA 2.5V @ 250uA 5Ω @ 500mA,10V 225mW SOT-23(SOT-23-3) MOSFET | 0.0122 | 50 | 2N7002 | Guangdong Hottech |  | https://lcsc.com/product-detail/MOSFET_Guangdong-Hottech-2N7002_C181082.html | 2
37 | Resistor | R | R25 | 100k | R_1206_3216Metric | 1 | ~ |  |  |  | 0.01 |  |  |  |  |  | 1
39 | Push button switch, generic, two pins | SW_Push | SW4 | BACK | SW_Push_5.1mm_H1.5mm | 1 | ~ | C318884 | LCSC | SPST 50mA @ 12VDC Vertical Round Button 160gf SMD Tactile Switches | 0.01 | 500 | TS-1187A-B-A-B | XKB Connectivity |  | https://lcsc.com/product-detail/Tactile-Switches_XKB-Connectivity-TS-1187A-B-A-B_C318884.html | 1
40 | Push button switch, generic, two pins | SW_Push | SW2 | DOWN | SW_Push_5.1mm_H1.5mm | 1 | ~ | C318884 | LCSC | SPST 50mA @ 12VDC Vertical Round Button 160gf SMD Tactile Switches | 0.01 | 500 | TS-1187A-B-A-B | XKB Connectivity |  | https://lcsc.com/product-detail/Tactile-Switches_XKB-Connectivity-TS-1187A-B-A-B_C318884.html | 1
41 | Push button switch, generic, two pins | SW_Push | SW3 | ENTER | SW_Push_5.1mm_H1.5mm | 1 | ~ | C318884 | LCSC | SPST 50mA @ 12VDC Vertical Round Button 160gf SMD Tactile Switches | 0.01 | 500 | TS-1187A-B-A-B | XKB Connectivity |  | https://lcsc.com/product-detail/Tactile-Switches_XKB-Connectivity-TS-1187A-B-A-B_C318884.html | 1
42 | Push button switch, generic, two pins | SW_Push | SW5 | Ein/Aus | SW_Push_5.1mm_H1.5mm | 1 | ~ | C318884 | LCSC | SPST 50mA @ 12VDC Vertical Round Button 160gf SMD Tactile Switches | 0.01 | 500 | TS-1187A-B-A-B | XKB Connectivity |  | https://lcsc.com/product-detail/Tactile-Switches_XKB-Connectivity-TS-1187A-B-A-B_C318884.html | 1
43 | Push button switch, generic, two pins | SW_Push | SW1 | UP | SW_Push_5.1mm_H1.5mm | 1 | ~ | C318884 | LCSC | SPST 50mA @ 12VDC Vertical Round Button 160gf SMD Tactile Switches | 0.01 | 500 | TS-1187A-B-A-B | XKB Connectivity |  | https://lcsc.com/product-detail/Tactile-Switches_XKB-Connectivity-TS-1187A-B-A-B_C318884.html | 1
18 | Light emitting diode | LED | D1 | rot | LED_1206_3216Metric | 1 | ~ | C965823 | LCSC | LED, green, SMD3216 | 0.0079 | 50 |  |  |  |  | 1
12 | BAV99 High-speed switching diodes | BAV99 | D2 | BAV99 | SOT-23 | 1 | https://assets.nexperia.com/documents/data-sheet/BAV99_SER.pdf | C181111 | LCSC | 70V 200mA 1.25V @ 150mA 6ns SOT-23 Switching Diode | 0.0073 | 500 | BAV99 | Guangdong Hottech |  | https://lcsc.com/product-detail/Switching-Diode_BAV99-chip0-23_C181111.html | 1
Component Groups: | 51
Component Count: | 108
Fitted Components: | 107
Number of PCBs: | 1
Total components: | 107
Schematic Version: | 0.0.1
Schematic Date: | 2021-05-02
PCB Variant: | default
BoM Date: | Sun 02 May 2021 08:45:23 PM CEST
Schematic Source: | jbc-miniregler.sch
KiCad Version: | Eeschema 5.1.10-88a1d61d58~88~ubuntu20.04.1

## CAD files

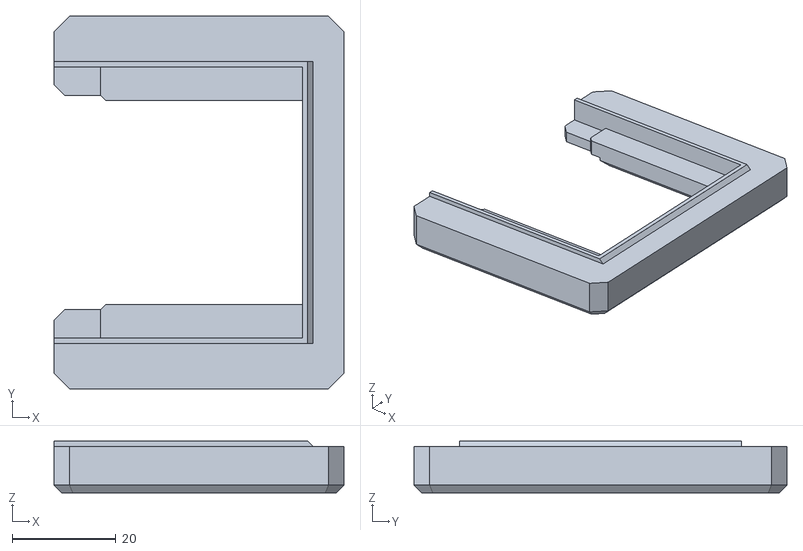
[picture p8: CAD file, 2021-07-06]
3d/batterie-adapter/ActiveEnergy_Schuh_v2.stl
56.0 x 72.0 x 10.0

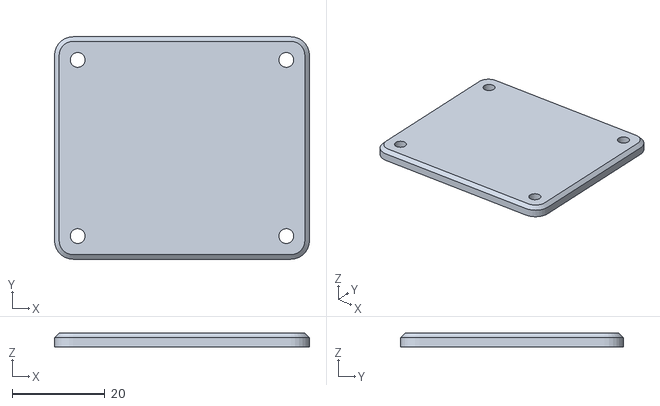
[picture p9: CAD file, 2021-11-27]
3d/batterie-adapter/berner-18v/berner-18v_deckel.stl
55.0 x 48.0 x 3.00

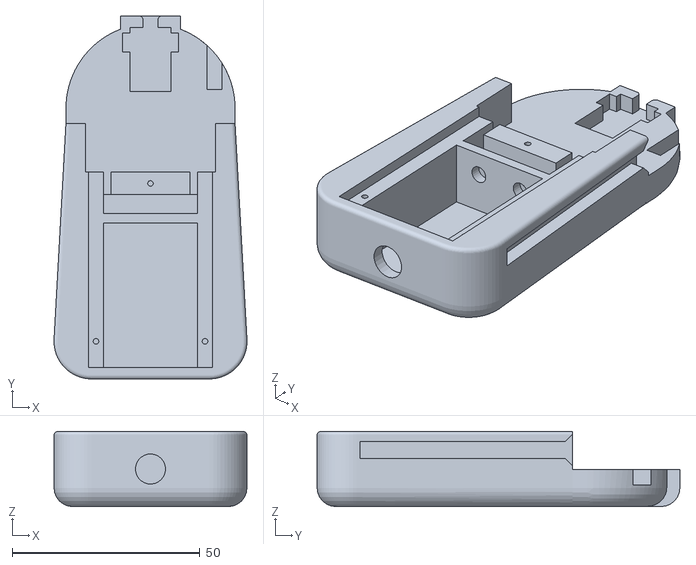
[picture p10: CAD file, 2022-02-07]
3d/batterie-adapter/bosch-hobby-18v/files/body-8mm.stl
51.3 x 96.5 x 20.0

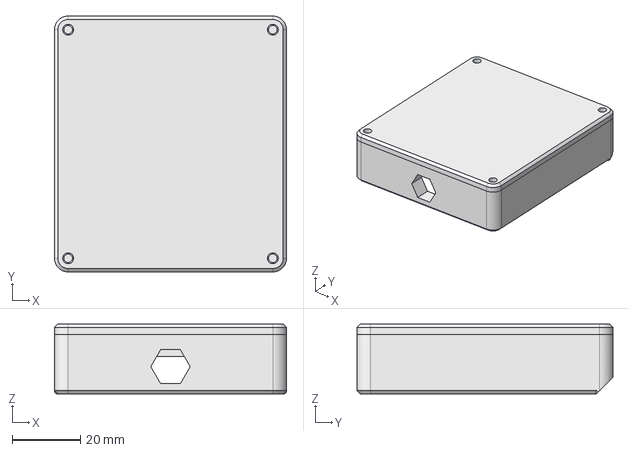
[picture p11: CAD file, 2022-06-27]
3d/batterie-adapter/bosch-professional-18v/bosch-professional-batterieschuh_v2.FCStd
68.0 x 75.0 x 20.5 mm
Bosch
Deckel

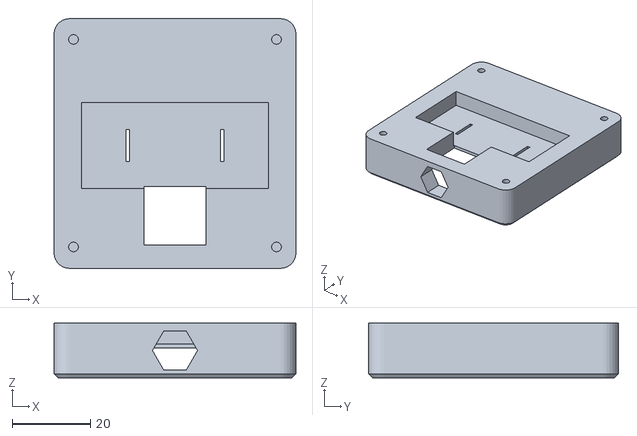
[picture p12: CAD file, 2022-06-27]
3d/batterie-adapter/einhell/einhell-batterieschuh_v2.stl
62.0 x 64.0 x 14.0

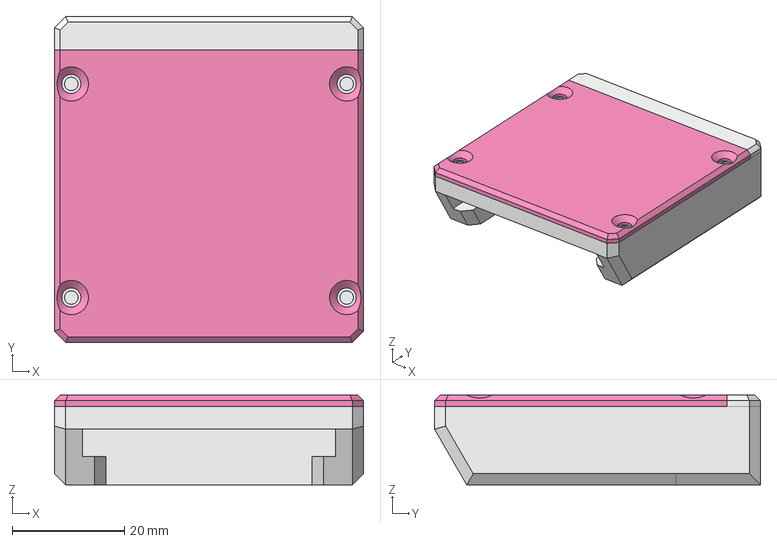
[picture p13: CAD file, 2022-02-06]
3d/batterie-adapter/lux-tools-1.5ah/LUX Tools 20V-1.5Ah.FCStd
55.0 x 58.0 x 16.0 mm
Schuh
Deckel

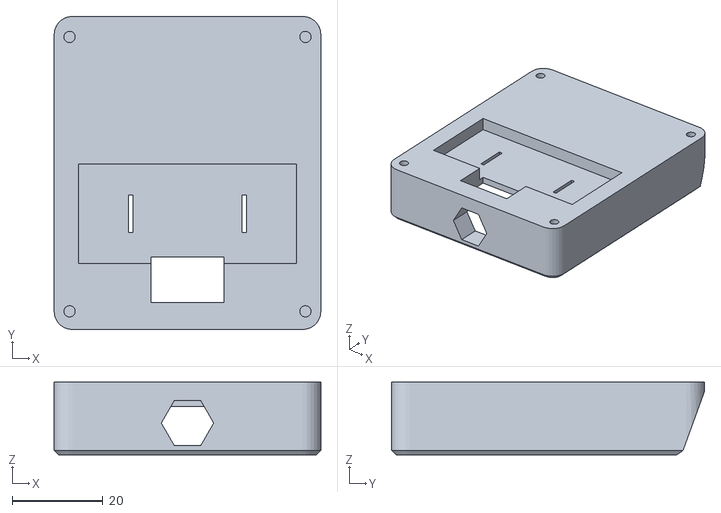
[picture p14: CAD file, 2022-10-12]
3d/batterie-adapter/lux-tools-2ah/lux-tools-2Ah_batterieschuh_v3.stl
58.8 x 69.0 x 16.0

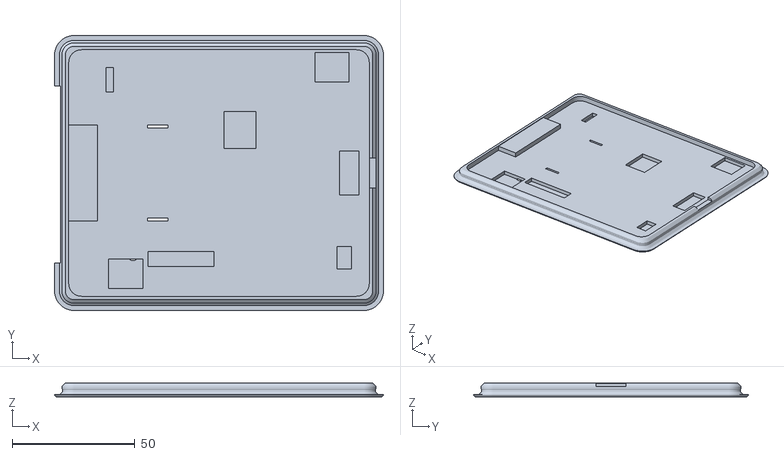
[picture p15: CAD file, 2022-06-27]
3d/batterie-adapter/makita/lötregler-gehäuse-boden_v4_makita.stl
134.0 x 112.0 x 5.80

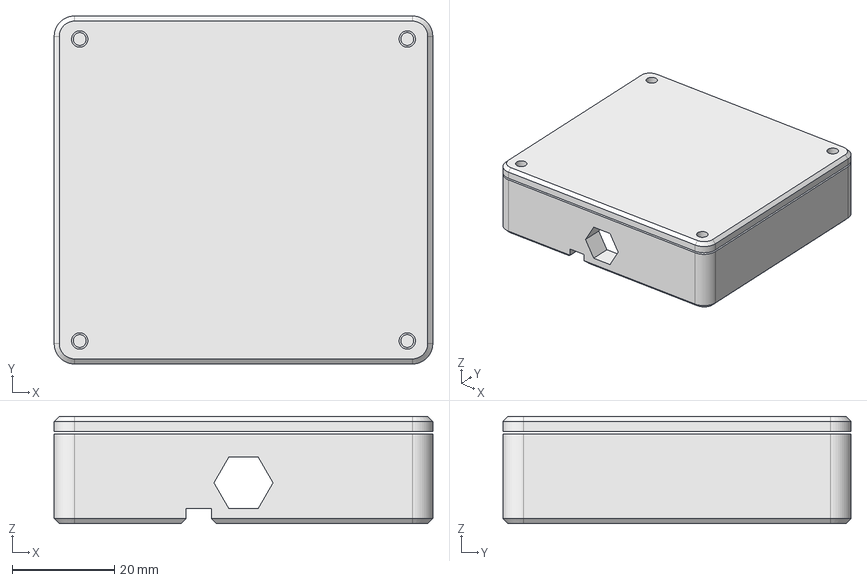
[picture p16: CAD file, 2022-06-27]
3d/batterie-adapter/milwaukee/milwaukee-batterieschuh.FCStd
74.0 x 68.0 x 21.0 mm
Milwaukee M18
Deckel

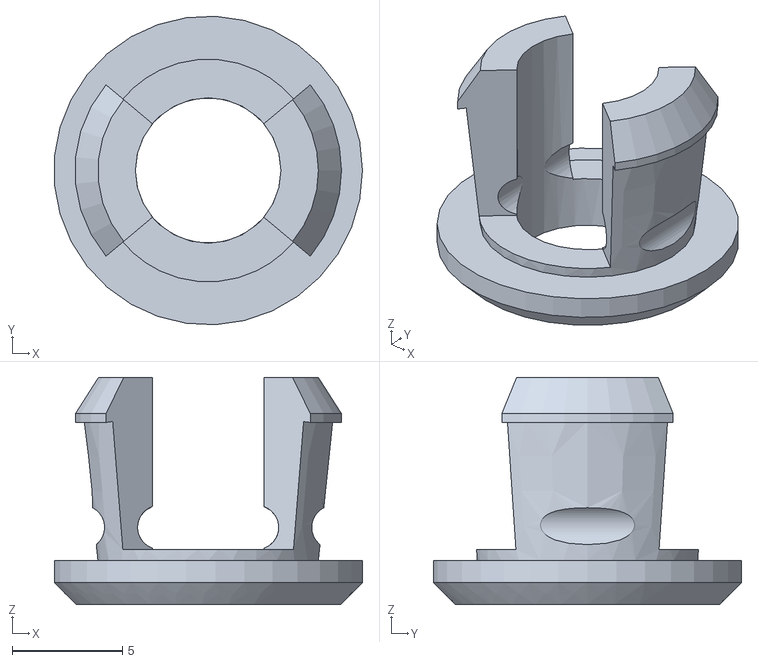
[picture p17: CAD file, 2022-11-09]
3d/gehäuse/zugentlastung_v1.4.stl
14.0 x 14.0 x 10.3

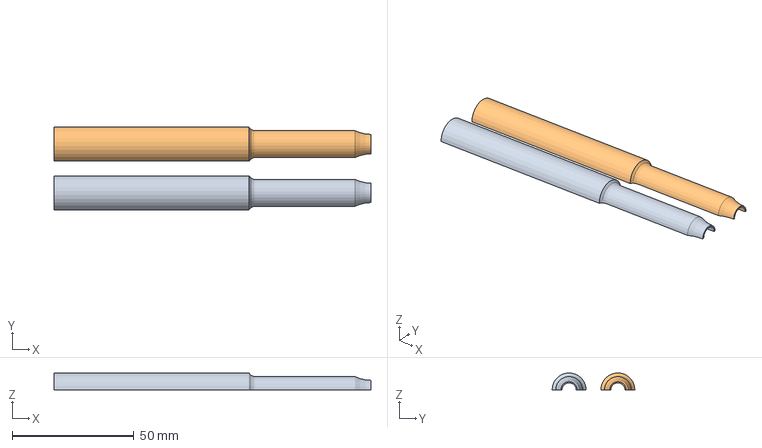
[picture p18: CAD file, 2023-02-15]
3d/griffstük/griffstück_halbschale-rund_v2_Polycarbonat.3mf
130.0 x 34.0 x 6.95 mm

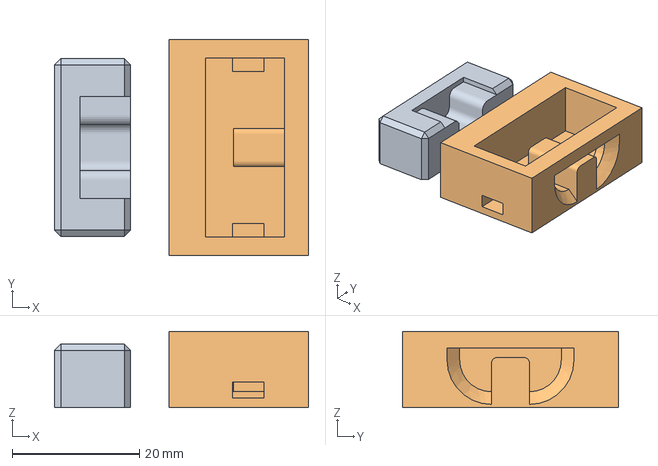
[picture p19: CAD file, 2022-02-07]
3d/tiefziehform/tiefziehform_A_stempel_v3.3mf
40.0 x 34.0 x 12.0 mm
tiefziehform_A_matrizze_v3.stl
tiefziehform_A_stempel_v3.stl

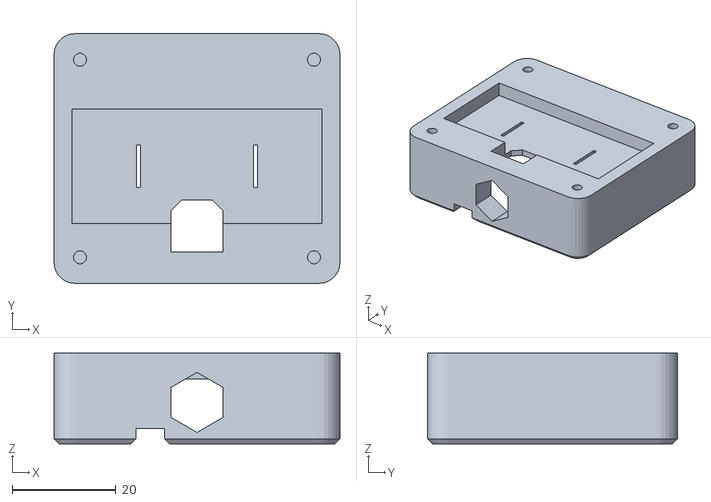
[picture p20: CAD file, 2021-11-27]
3d/batterie-adapter/berner-18v/berner-18v_hauptteil.stl
55.0 x 48.0 x 17.5

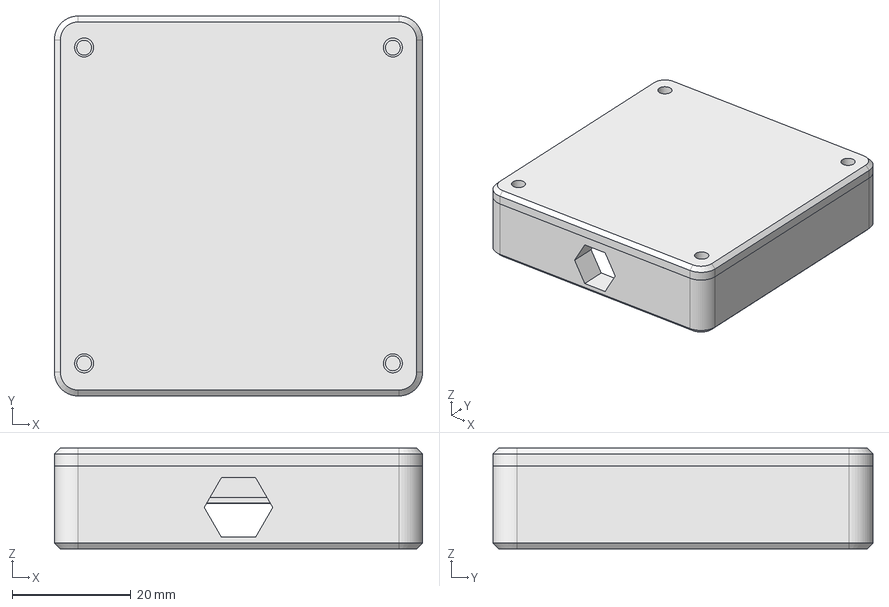
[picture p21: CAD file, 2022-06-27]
3d/batterie-adapter/einhell/einhell-batterieschuh.FCStd
62.0 x 64.0 x 17.0 mm
Einhell
Deckel

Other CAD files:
3d/batterie-adapter/bosch-hobby-18v/files/body-2usb.stl
3d/batterie-adapter/lux-tools-1.5ah/LUX Tools 20V-1.5Ah, Deckel v1.stl
3d/batterie-adapter/lux-tools-2ah/lux-tools-2Ah_batterieschuh.FCStd
3d/batterie-adapter/milwaukee/milwaukee-batterieschuh_v2.stl
3d/batterie-adapter/berner-18v/berner-18v.3mf
3d/batterie-adapter/berner-18v/berner-batterieschuh.FCStd
3d/batterie-adapter/bosch-hobby-18v/files/deckel.stl
3d/batterie-adapter/bosch-professional-18v/bosch-professional-batterieschuh.FCStd
3d/batterie-adapter/bosch-professional-18v/bosch-professional-batterieschuh_deckel_v1.stl
3d/batterie-adapter/bosch-professional-18v/bosch-professional-batterieschuh_v1.stl
3d/batterie-adapter/bosch-professional-18v/bosch-professional-batterieschuh_v2.stl
3d/batterie-adapter/einhell/einhell-batterieschuh.3mf
3d/batterie-adapter/einhell/einhell-batterieschuh_deckel_v1.stl
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

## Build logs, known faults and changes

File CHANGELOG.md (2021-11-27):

HTL Lötregler Mini - Changelog
==============================

# Hardware
## V21.0.1
* Überdeckende Footprints noch auseinander gerückt
* Messwiderstand der 12V-Versorgung richtig geschaltet, zuvor war Gatetreiber fix versorgt
* Freilaufdiode parallel zum Heizelement
* VUSB-Feedback auf Pin D10, um zu erkennen, ob man per USB versorgt ist. 
* Pulldown für Leistungs-FET am Gate
* BOM: 1% Widerstände bei Signalverstärker

## V21.0.0, Kleinserie
* 15 PCBs bestellt, 10 Bauteile-Sets

### Inbetriebnahme
* 56k Gate-Pulldown eingefügt
* Widerstände angepasst: 
  * R22 und R24 von 30k auf 22k verkleinert 
    (Signalverstärkung für Temperatur und Strom reduziert) --> deltaT_max = 470K, I_max = 11.3A. 
  * R39 von 10k auf 22k vergrößert (Spannungsteiler Batteriemessung, U_max = 57.5V)

## Entwicklung, V0.0.1
* Gatewiderstand von 100k auf 10k korrigiert. 
* Reset-Kondensator eingefügt (10nF, notwendig?)
* Footprint + 3D-Modell für Federklemmen fertig
* 3D-Modell für USB-B Steckverbinder
* Optional anstatt von RS232 RS485 möglich
* Footprint der Induktivität korrigiert
* Footprint der breiten SMA Schottky Diode
* Spannungsreferenz 2.5V, TL431 (ACHTUNG: diese gibts mit verschiedenen Pinbelegungen zu bestellen)
* Optional ein Invertierender Verstärker
* SMD-Öse für GND hinzugefügt
* Projekt umbenannt von "JBC Miniregler" auf "HTL Lötregler Mini"

# Firmware
## Entwicklung v0.0.1
* Main Screen mit Batteriezustand, Batteriespannung, Ist-Temperatur und Soll-Temperatur
* Zeitabschaltung nach 10 Minuten
* Abkühlphase wird am Display angezeigt bis 60°C unterschritten wurden. 
* Grafik Design in Inkscape

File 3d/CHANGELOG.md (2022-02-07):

CHANGELOG 3D-Gehäuse, Lötregler-Mini
==========

# Gehäuseboden:
V1: erste Version
V2: korrigierte THT-Aussparungen
V3: um 1.5mm Versetzte Activ-Energy-Kontakte, ab PCB V21.0.1

## Makita V3: 
* Ausrichtungsbohrungen für Makita-Schuh V3: d4.4, h1.4
* Abdeckung für Batteriearretierung um 0.5mm verküzt, damit die Leiterplatte leichter rein passt. 

# Batterie-Adapter
## Makita Schuh
* angepasst auf vorliegenden Makita Akku
* zusätzlich: Ausrichtungsstutzen, können für alten Gehäuseboden weggefeilt werden: d4, h1

# Griffstück
## Redesign V2
* Modularer Aufbau, optimiert für den 3D-Druck (keine Brücken notwendig). 
* 2 Halbschalen für 6-eckige Einlage --> druckt sauber, perfekte aussparungen für die Federkontakte
* saubere Leitungsführung
* Umschließende zusätzliche zylindrische Hülle --> Doppelte Isolierung, kein längsschlitz mehr vorhanden, wo Kontakte mit Drahtresten berührt werden könnten
* Saubere zenrische Führung der Kartusche durch isolierstücke bei jedem Federkontakt
* Sauberer Endanschlag der Kartusche
* Federkontakte identisch zu V1
* Mittlerer Kontatk axial um 180° gedreht zur besseren Leitungsführung
* saubere Zugentlastung durch Riffelung unter dem Endring
* gesamt etwas dicker geworden: 14mm Griffdurchmesser. 

Nach dem ersten Testdruck:
* Isolierkörper: Bohrung vergrößert um 0.2mm von 4.8 auf 5.0. --> v
* Fingerkuppenring innen um 0.2mm vergrößert von 14 auf 14.2 --> v2.2
* Endring innen von 11 auf 11.2mm vergrößert --> v2.1
* Mittenring ebenfalls gleichermaßen um je 0.2mm vergrößert --> v2.1

* Loch um 0.1mm versetzt, damit der Isolator sauber gedruckt werden kann: griffstück_isolator_htc-_h+_v2.1.stl

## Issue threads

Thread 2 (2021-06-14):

BOM: 1uF/100V statt 50V

KarlZeilhofer, 2021-06-14:
Bestellt wurde C710469 (100V).
In der BOM steht aber noch C1848 (50V).

KarlZeilhofer, 2021-09-22:
C710469 ist mittlerweile nicht mehr verfügbar!

KarlZeilhofer, 2021-09-22:
Yageo CC1206KKX7R0BB105 wäre eine lieferbare Alternative

Closed 2021-09-22.

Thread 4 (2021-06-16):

Pulldown für Gate am Leistungs-FET notwendig

KarlZeilhofer, 2021-06-16:
Bei der ersten Inbetriebnahme ging der Gatetreiber und/oder der 12V-Schaltregler drauf.

Mit einem Gatewiderstand am Q1 von 56k zwischen Gate und Source zum definierten Ausschalten des Transistors bei inaktivem Gatetreiber läuft die Schaltung nun.

Betrifft Version V21.0.0

KarlZeilhofer, 2021-09-22:
erledigt in v21.0.1

Closed 2021-09-22.

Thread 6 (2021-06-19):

Faston Tabs: für ActivEnergy leicht versetzen

KarlZeilhofer, 2021-06-19:
Betrifft V21.0.0

Die Kraft, die notwendig ist, um die Platine auf den Akku zu schieben ist relativ groß, da alle 4 Kontakte (beim 40V-Akku) gleichzeitig greifen.

Die B2 Kontakte sollten um 1.5mm nach rechts verschoben werden.

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

KarlZeilhofer, 2021-09-22:
in PCB v21.0.1 erledigt.
TODO: im Gehäuse nachziehen

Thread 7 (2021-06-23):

Keine USB-Verbindung fürs Debugging

KarlZeilhofer, 2021-06-23:
Betrifft HW V21.0.0

* Board auf Akku stecken
* USB-Kabel anstecken
* Verbindung mit CuteCom aufbauen
* --> keine Serielle Kommunikation über USB vorhanden
* Drücken auf den Power-Taster: 12V-Versorgung kommt hinzu, jedoch keine Selbsthaltung
  Controller scheint im Reset zu bleiben.

KarlZeilhofer, 2021-09-29:
Das Problem kommt aus der Software, nämlich der Unterspannugnsabschaltung.
Wird die USB-Verbindung aktiviert, wird ein Reset ausgelöst, dieser setzt alle Pins auf hochohmig, und deaktiviert somit die Selbsthaltung. Dann startet der Arduino, und sieht keine Batteriespannung und dreht sich somit sofort wieder ab.
Workaround:
* Power Taste halten
* Kurz Reset drücken
* Power Taste wieder auslassen

In V21.0.1 wird folgender HW-Fix gemacht: VUSB wird auf Pin D10 zurückgeführt, damit man per Software sehen kann, ob USB angesteckt ist, oder nicht. Entsprechend kann man dann richig reagieren.

Closed 2021-09-29.

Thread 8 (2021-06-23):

Freilaufdiode parallel zum Heizelement

KarlZeilhofer, 2021-06-23:
Der Gatetreiber wird nur für einen Highside MOSFET verwendet.

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

Der Gatetreiber ist vorgestern beim mehrmaligen Ein-/Austecken der Lötspitze defekt geworden. Ohne Spitze konnte das Board starten, mit Spitze jedoch erreichte die 12V-Versorgung nur ca. 2V.

Es wurde nun zwischen H+ und HTC- eine 2A-Schottky-Diode gelötet. Bisher gab es keinen Ausfall mehr.

KarlZeilhofer, 2021-09-22:
erledigt in v21.0.1

Closed 2021-09-22.

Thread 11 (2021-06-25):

Footprints etwas auseinanderrücken

KarlZeilhofer, 2021-06-25:
Besonders große Kondensatoren schwimmern gerne zusammen, und bilden einen Kurzschluss. Sollte bestmöglich

KarlZeilhofer, 2021-09-22:
südlich vom uC gemacht.

KarlZeilhofer, 2021-09-22:
nödlich von der MCU erledigt

Closed 2021-09-22.

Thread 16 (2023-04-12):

Resettaster wieder auf alte Position bringen!

KarlZeilhofer, 2023-04-12:
Durch Johannes H. wurde versehentlich der Resettaster versetzt.
Um mechanisch zur AVR-Version kompatibel zu sein, sollte der wieder links unten sitzen.

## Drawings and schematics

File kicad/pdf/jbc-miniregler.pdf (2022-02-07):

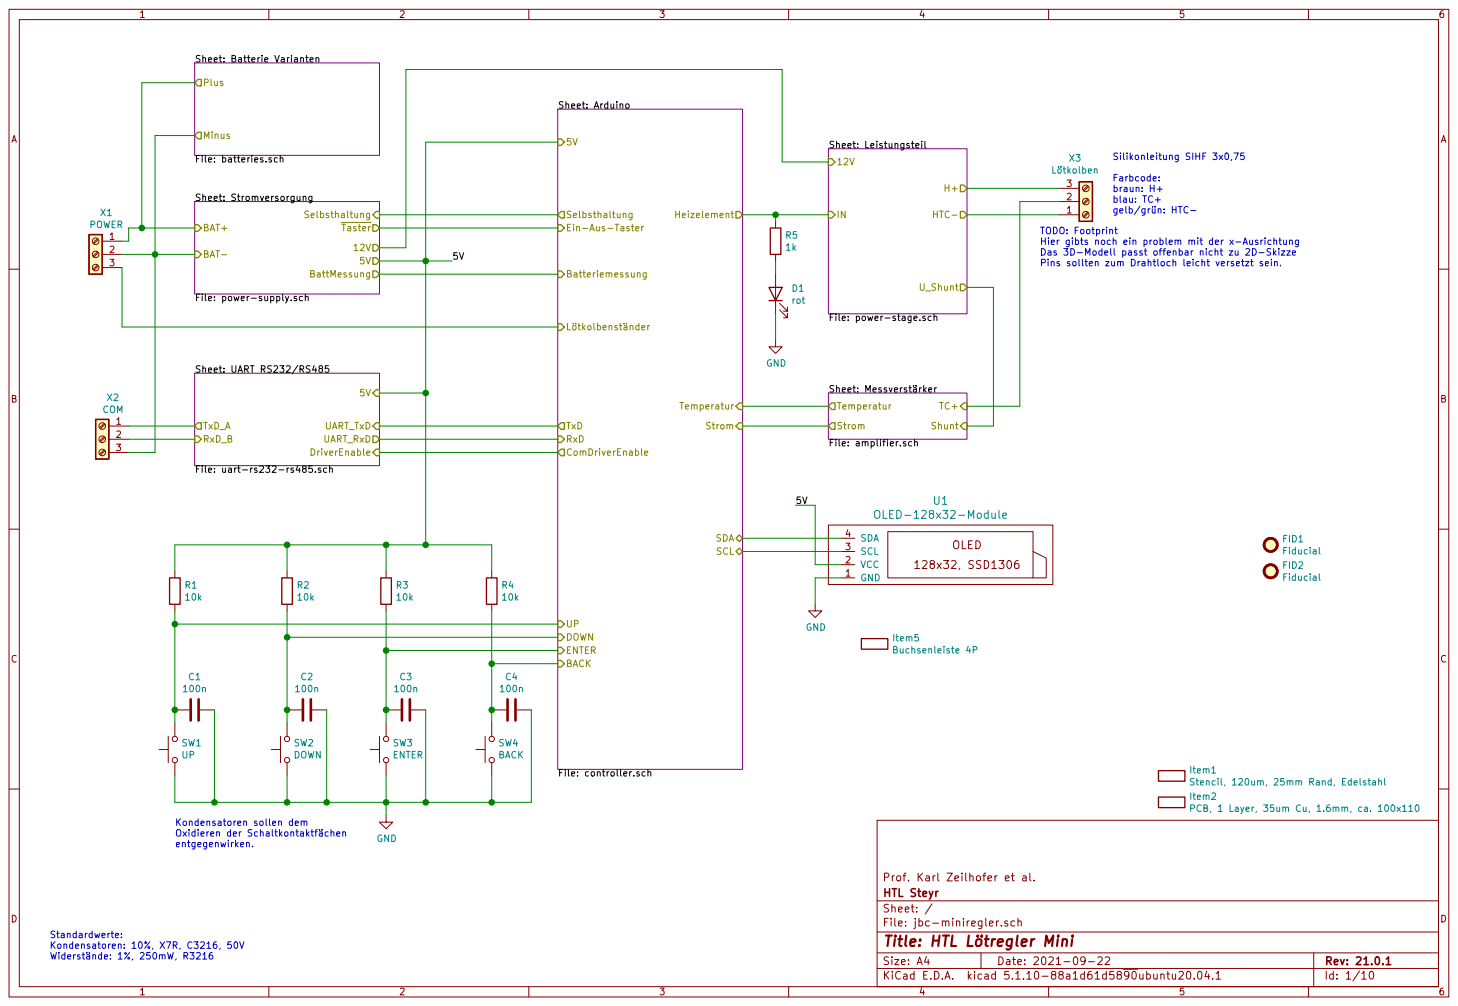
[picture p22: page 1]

Das 3D-Modell passt offenbar nicht zu 2D-Skizze Pins sollten zum Drahtloch leicht versetzt sein. Silikonleitung SIHF 3x0,75 Farbcode: braun: H+
Lötkolben

TODO: Footprint
Hier gibts noch ein problem mit der x-Ausrichtung

gelb/grün: HTC- Kondensatoren sollen dem

BattMessung Sheet: UART RS232/RS485 File: uart-rs232-rs485.sch

File: power-supply.sch

File: power-stage.sch

Sheet: Messverstärker File: amplifier.sch

FID1 Fiducial FID2 Fiducial Item1Stencil, 120um, 25mm Rand, Edelstahl Item2PCB, 1 Layer, 35um Cu, 1.6mm, ca. 100x110 SW3 ENTER

entgegenwirken. Standardwerte: Kondensatoren: 10%, X7R, C3216, 50V Widerstände: 1%, 250mW, R3216

File: jbc-miniregler.sch Sheet: / HTL Steyr Prof. Karl Zeilhofer et al.

Id: 1/10 Title: HTL Lötregler Mini

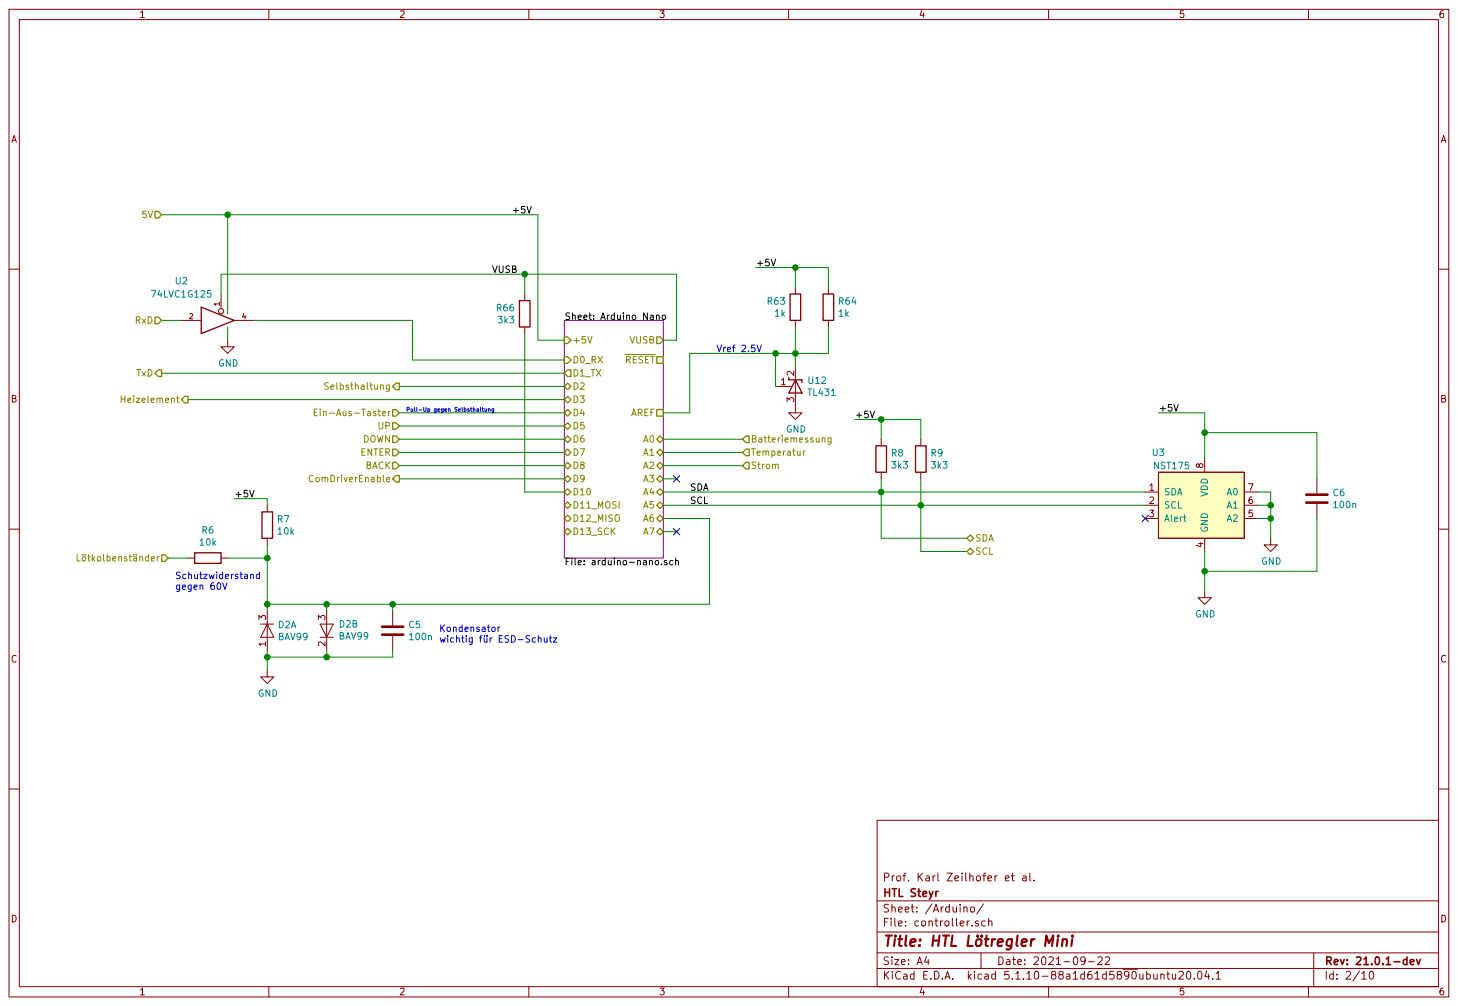
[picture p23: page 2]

Sheet: Arduino Nano File: arduino-nano.sch D0_RX D1_TX D2 D3 D4 D5 D6 D7 D8 D9 D10 D11_MOSI D12_MISO

2 3 U12 TL431 SDA 1 SCL 2 Alert 3 GND

ComDriverEnable Ein-Aus-Taster DOWN

Kondensator wichtig für ESD-Schutz

Id: 2/10 Title: HTL Lötregler Mini File: controller.sch Sheet: /Arduino/ HTL Steyr Prof. Karl Zeilhofer et al.

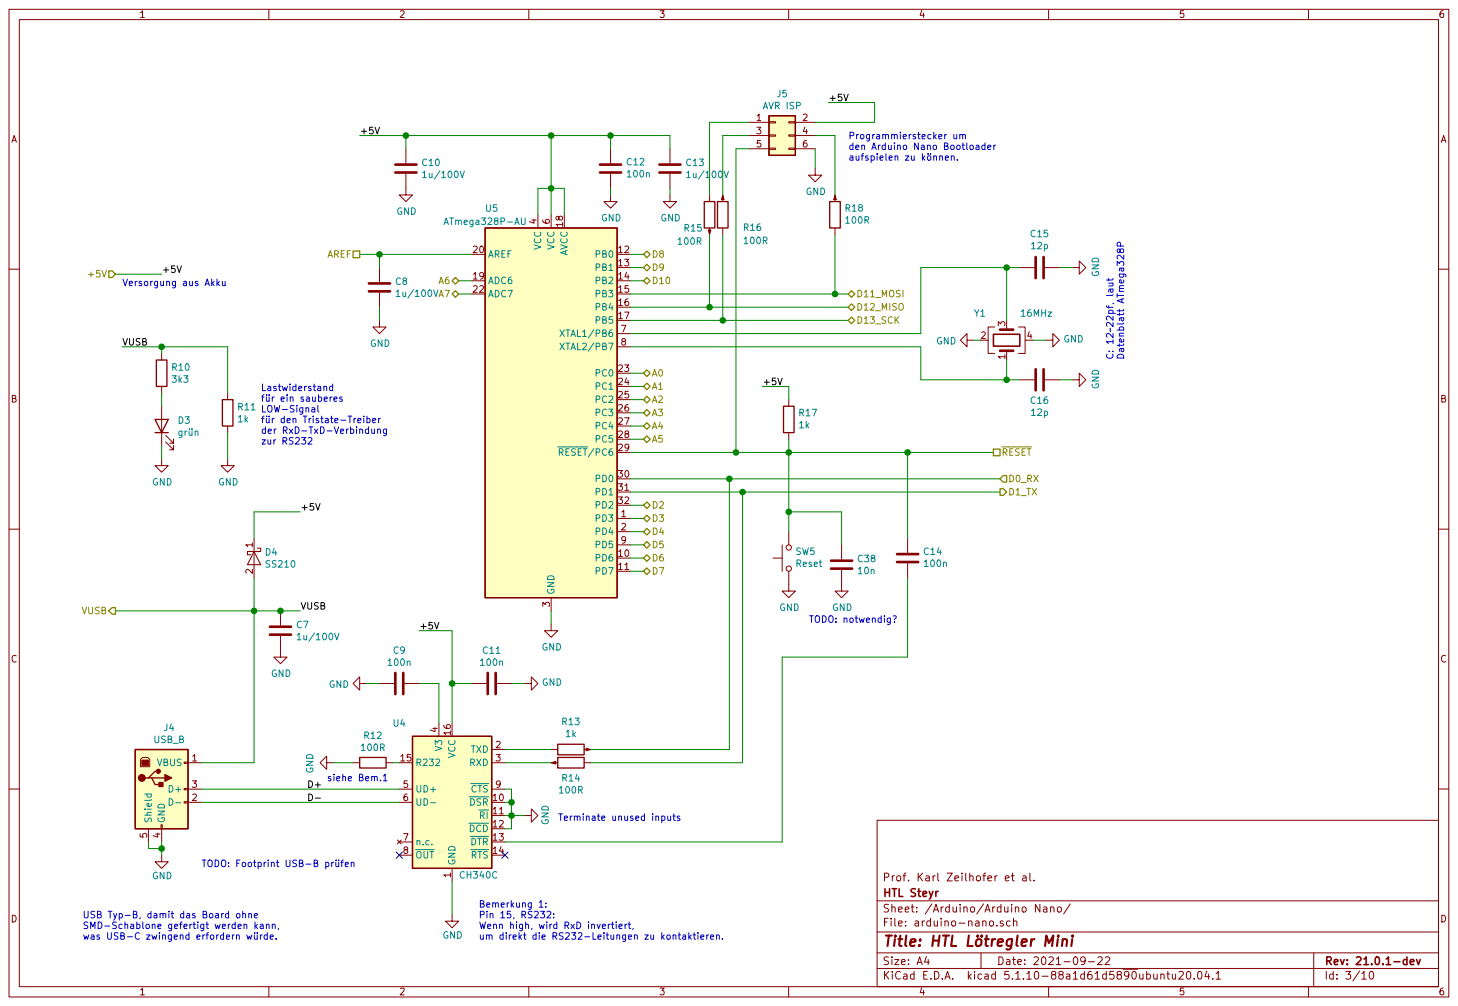
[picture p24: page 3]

den Arduino Nano Bootloader aufspielen zu können.

Lastwiderstand
für ein sauberes LOW-Signal für den Tristate-Treiber der RxD-TxD-Verbindung

1 DSR 10 RI 11 DCD 12 DTR 13 RTS 14 R232 15 VCC 16 TXD 2 RXD 3 V3

um direkt die RS232-Leitungen zu kontaktieren. siehe Bem.1

TODO: Footprint USB-B prüfen

Bemerkung 1: Pin 15, RS232: Wenn high, wird RxD invertiert,

USB Typ-B, damit das Board ohne
SMD-Schablone gefertigt werden kann,
was USB-C zwingend erfordern würde.

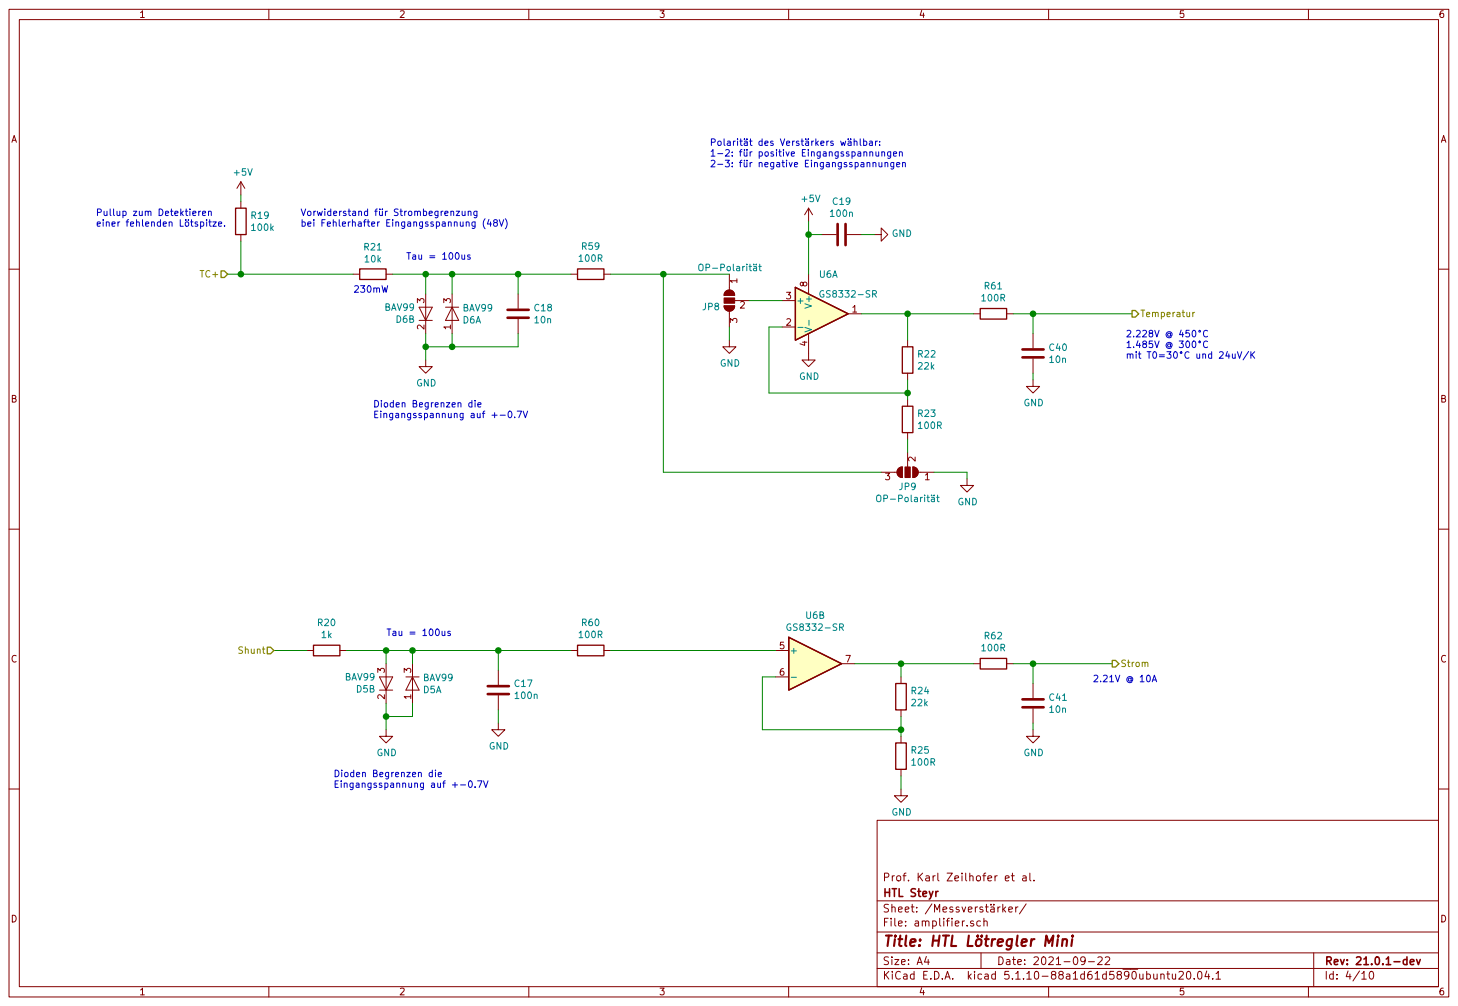
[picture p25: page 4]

Polarität des Verstärkers wählbar: 1-2: für positive Eingangsspannungen

2-3: für negative Eingangsspannungen Tau = 100us Vorwiderstand für Strombegrenzung
Tau = 100us 230mW
10n GND

File: amplifier.sch Sheet: /Messverstärker/ HTL Steyr Prof. Karl Zeilhofer et al.

Id: 4/10 Title: HTL Lötregler Mini

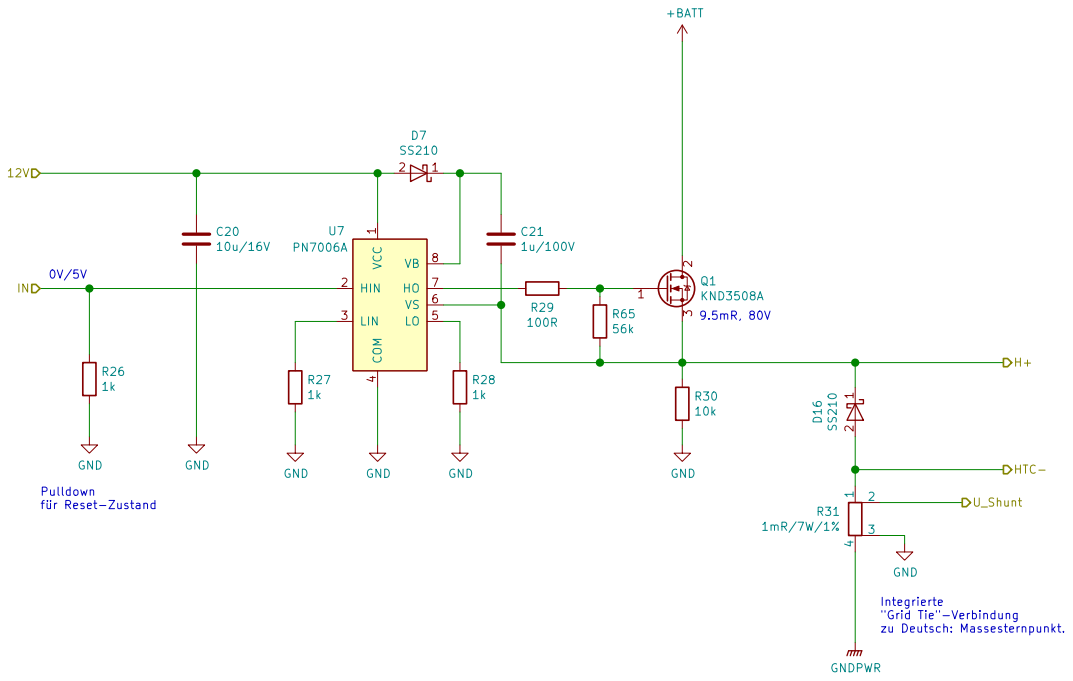
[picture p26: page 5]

1 HIN 2
HTL Steyr Prof. Karl Zeilhofer et al. VCC

Sheet: /Leistungsteil/
File: power-stage.sch
Id: 5/10 Title: HTL Lötregler Mini

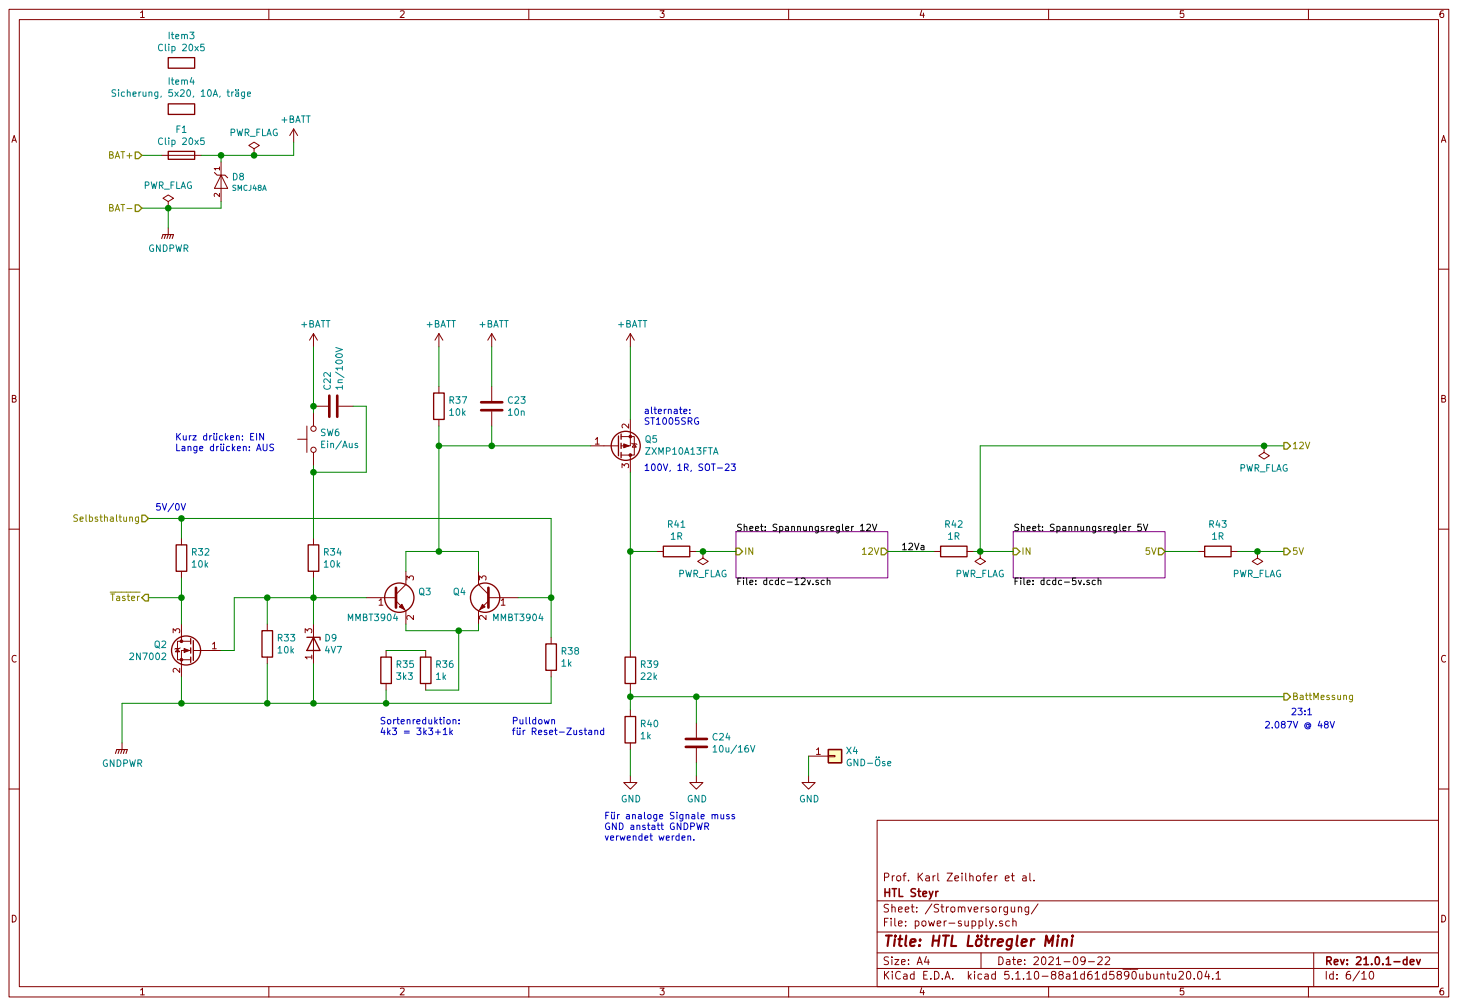
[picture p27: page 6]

23:1 Für analoge Signale muss GND anstatt GNDPWR verwendet werden. 5V/0V

HTL Steyr Prof. Karl Zeilhofer et al. Sheet: Spannungsregler 5V

Sheet: /Stromversorgung/
File: power-supply.sch
Id: 6/10 Title: HTL Lötregler Mini

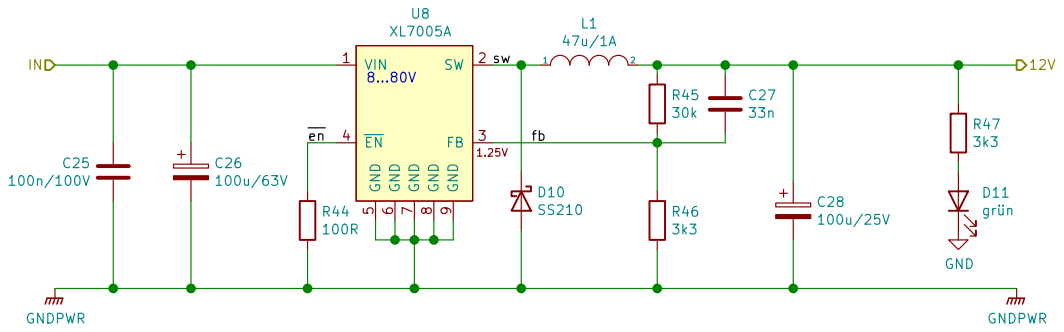
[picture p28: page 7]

HTL Steyr Prof. Karl Zeilhofer et al.

Id: 7/10 Title: HTL Lötregler Mini File: dcdc-12v.sch Sheet: /Stromversorgung/Spannungsregler 12V/

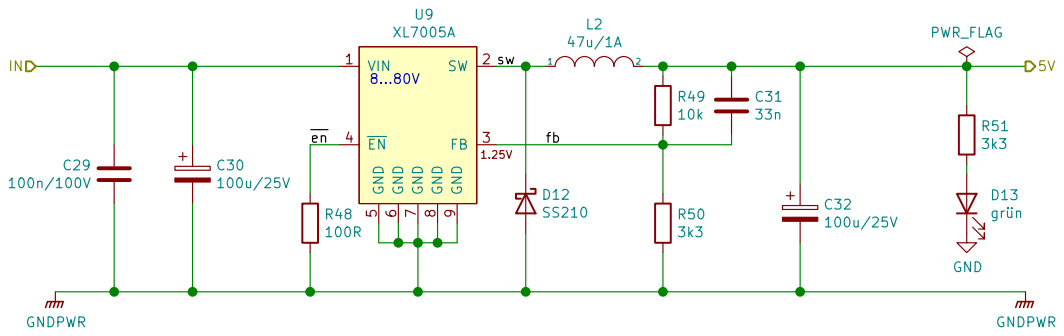
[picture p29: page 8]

HTL Steyr Prof. Karl Zeilhofer et al.

Id: 8/10 Title: HTL Lötregler Mini File: dcdc-5v.sch Sheet: /Stromversorgung/Spannungsregler 5V/

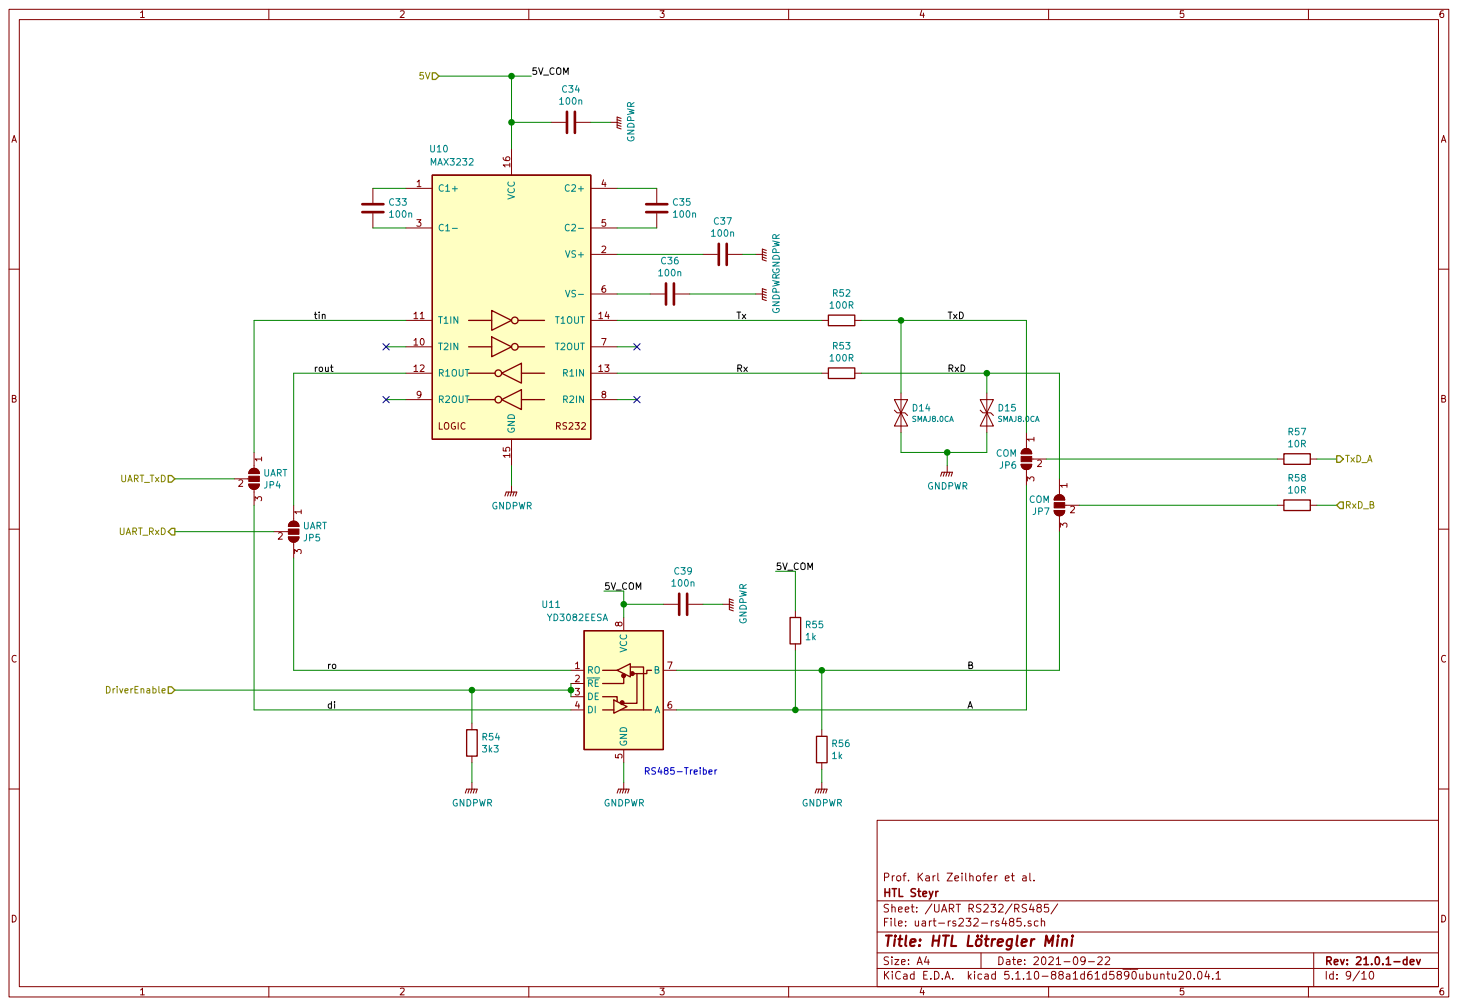
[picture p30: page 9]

3 JP5 UART GNDPWR GNDPWR GNDPWR

Id: 9/10 Title: HTL Lötregler Mini File: uart-rs232-rs485.sch Sheet: /UART RS232/RS485/ HTL Steyr Prof. Karl Zeilhofer et al.

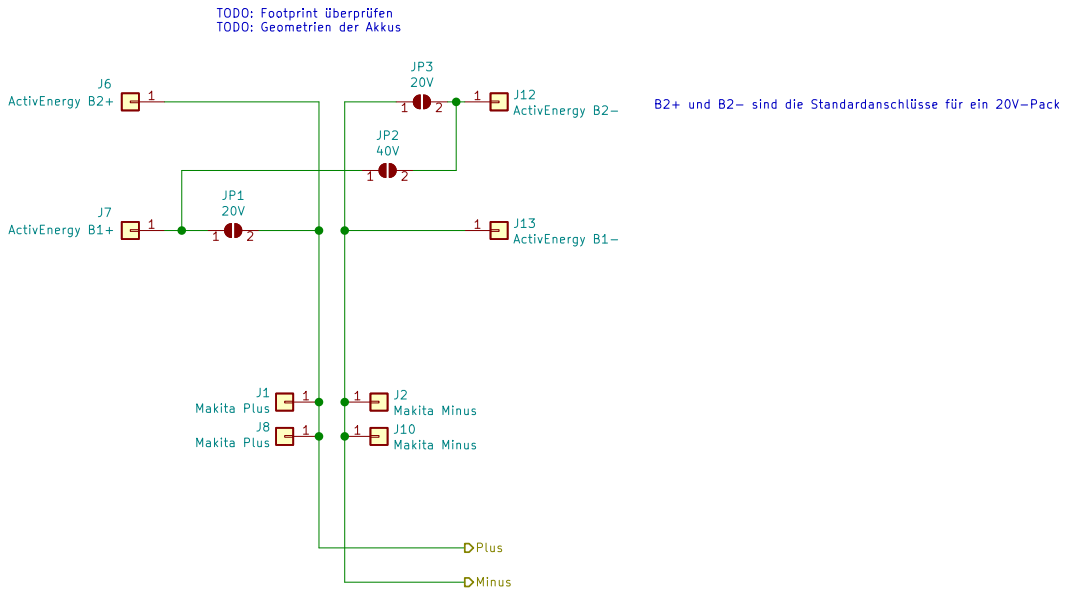
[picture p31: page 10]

Id: 10/10 Title: HTL Lötregler Mini File: batteries.sch Sheet: /Batterie Varianten/ HTL Steyr Prof. Karl Zeilhofer et al.

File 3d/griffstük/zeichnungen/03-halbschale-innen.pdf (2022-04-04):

A

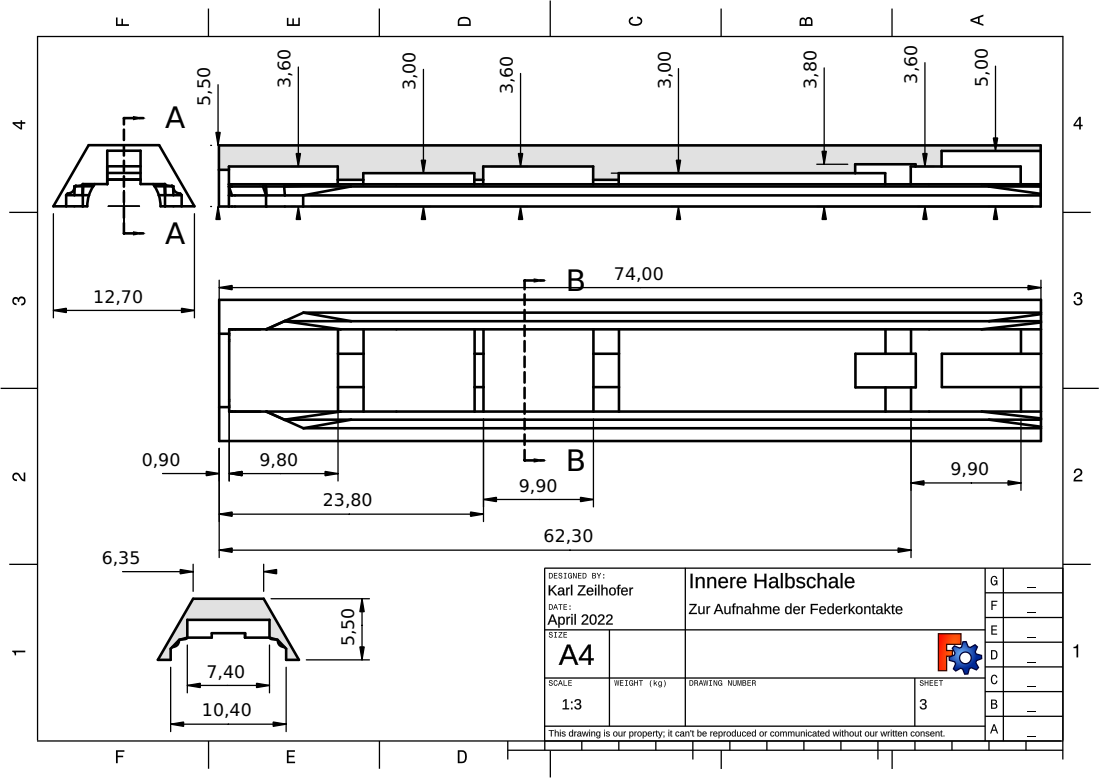
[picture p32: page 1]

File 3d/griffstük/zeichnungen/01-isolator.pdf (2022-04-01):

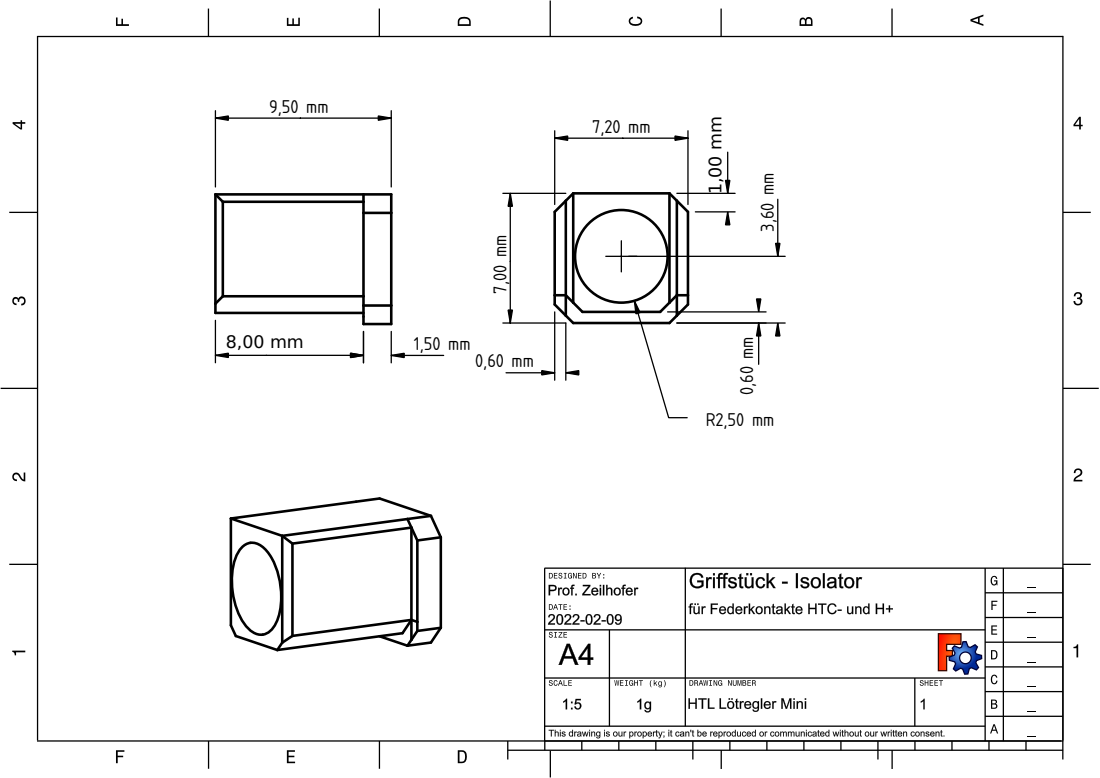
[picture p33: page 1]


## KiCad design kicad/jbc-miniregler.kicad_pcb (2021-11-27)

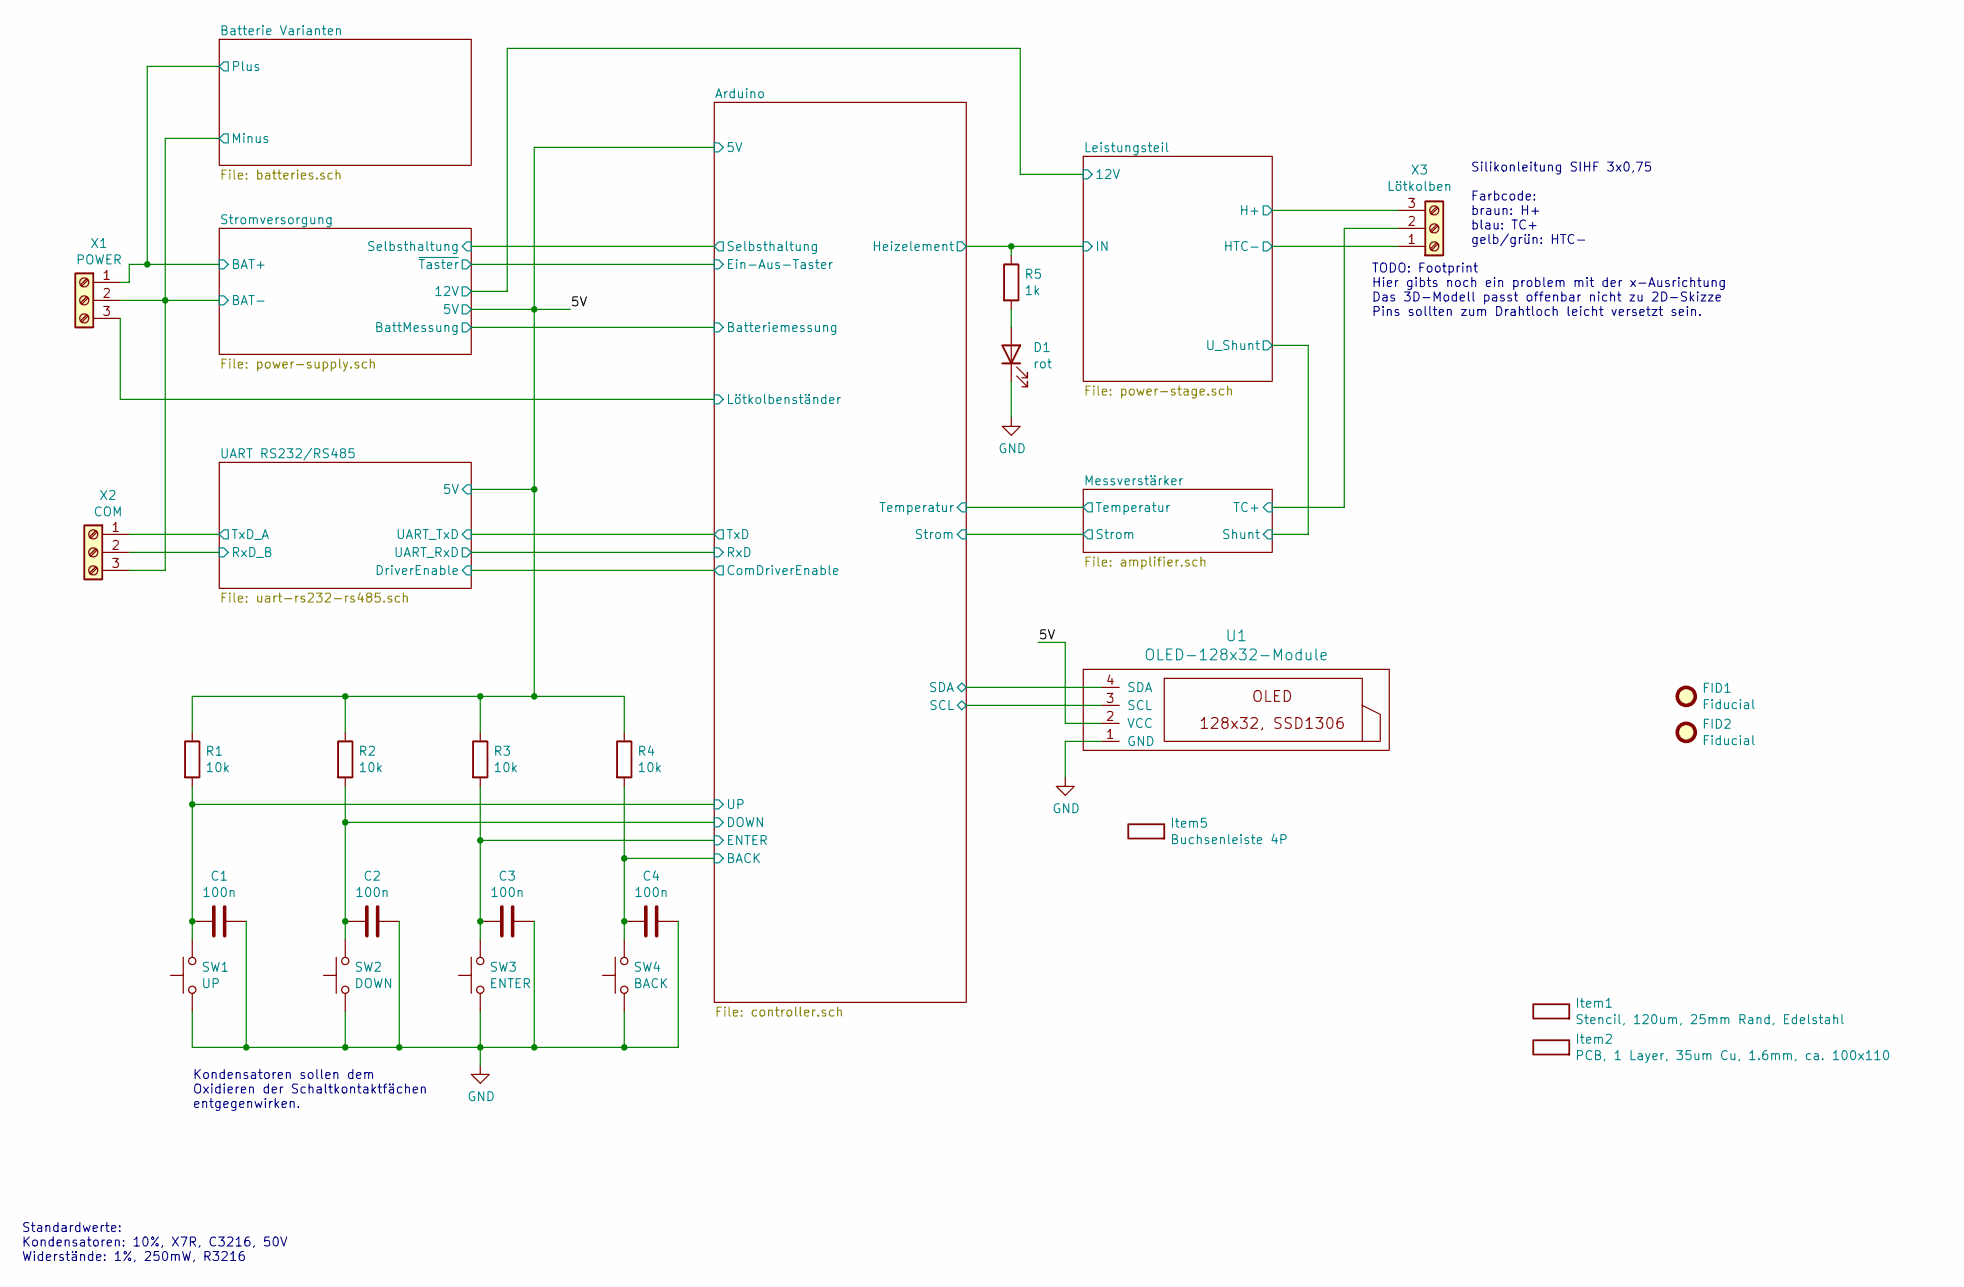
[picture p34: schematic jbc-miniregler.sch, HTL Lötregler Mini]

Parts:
C1, C2, C3, C4: 100n; C_1206_3216Metric; ManPartNr FN31X104K500PXG
D1: rot; LED_1206_3216Metric
FID1, FID2: Fiducial; paste-fiducial
Item1: Stencil, 120um, 25mm Rand, Edelstahl; Virtual-Item
Item2: PCB, 1 Layer, 35um Cu, 1.6mm, ca. 100x110; Virtual-Item
Item5: Buchsenleiste 4P; Virtual-Item; ManPartNr A2541HWV-4P
R1, R2, R3, R4: 10k; R_1206_3216Metric
R5: 1k; R_1206_3216Metric; ManPartNr RTT03101JTP
SW1: UP; SW_Push_5.1mm_H1.5mm; ManPartNr TS-1187A-B-A-B
SW2: DOWN; SW_Push_5.1mm_H1.5mm; ManPartNr TS-1187A-B-A-B
SW3: ENTER; SW_Push_5.1mm_H1.5mm; ManPartNr TS-1187A-B-A-B
SW4: BACK; SW_Push_5.1mm_H1.5mm; ManPartNr TS-1187A-B-A-B
U1: OLED-128x32-Module; OLED-128x32
X1: POWER; Federklemme_KF142_3P_P5.08mm_C475145
X2: COM; Federklemme_KF142_3P_P5.08mm_C475145
X3: Lötkolben; Federklemme_KF142_3P_P5.08mm_C475145

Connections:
+5V: R1.1, R2.1, R3.1, R4.1, U1.2 (VCC); also elsewhere on the board
/Arduino/BACK: C4.2, R4.2, SW4.2; also elsewhere on the board
/Arduino/DOWN: C2.2, R2.2, SW2.2; also elsewhere on the board
/Arduino/ENTER: C3.2, R3.2, SW3.2; also elsewhere on the board
/Arduino/Heizelement: R5.1; also elsewhere on the board
/Arduino/Lötkolbenständer: X1.3; also elsewhere on the board
/Arduino/SCL: U1.3 (SCL); also elsewhere on the board
/Arduino/SDA: U1.4 (SDA); also elsewhere on the board
/Arduino/UP: C1.2, R1.2, SW1.2; also elsewhere on the board
/Leistungsteil/H+: X3.3; also elsewhere on the board
/Leistungsteil/HTC-: X3.1; also elsewhere on the board
/Messverstärker/TC+: X3.2; also elsewhere on the board
/Stromversorgung/BAT+: X1.1; also elsewhere on the board
/UART RS232/RS485/RxD_B: X2.2; also elsewhere on the board
/UART RS232/RS485/TxD_A: X2.1; also elsewhere on the board
GND: C1.1, C2.1, C3.1, C4.1, D1.1 (K), SW1.1, SW2.1, SW3.1, SW4.1, U1.1 (GND); also elsewhere on the board
GNDPWR: X1.2, X2.3; also elsewhere on the board
unnamed: D1.2 (A), R5.2

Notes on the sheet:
Kondensatoren sollen dem Oxidieren der Schaltkontaktfächen entgegenwirken.
Standardwerte: Kondensatoren: 10%, X7R, C3216, 50V Widerstände: 1%, 250mW, R3216
TODO: Footprint Hier gibts noch ein problem mit der x-Ausrichtung Das 3D-Modell passt offenbar nicht zu 2D-Skizze Pins sollten zum Drahtloch leicht versetzt sein.
Silikonleitung SIHF 3x0,75 Farbcode: braun: H+ blau: TC+ gelb/grün: HTC-

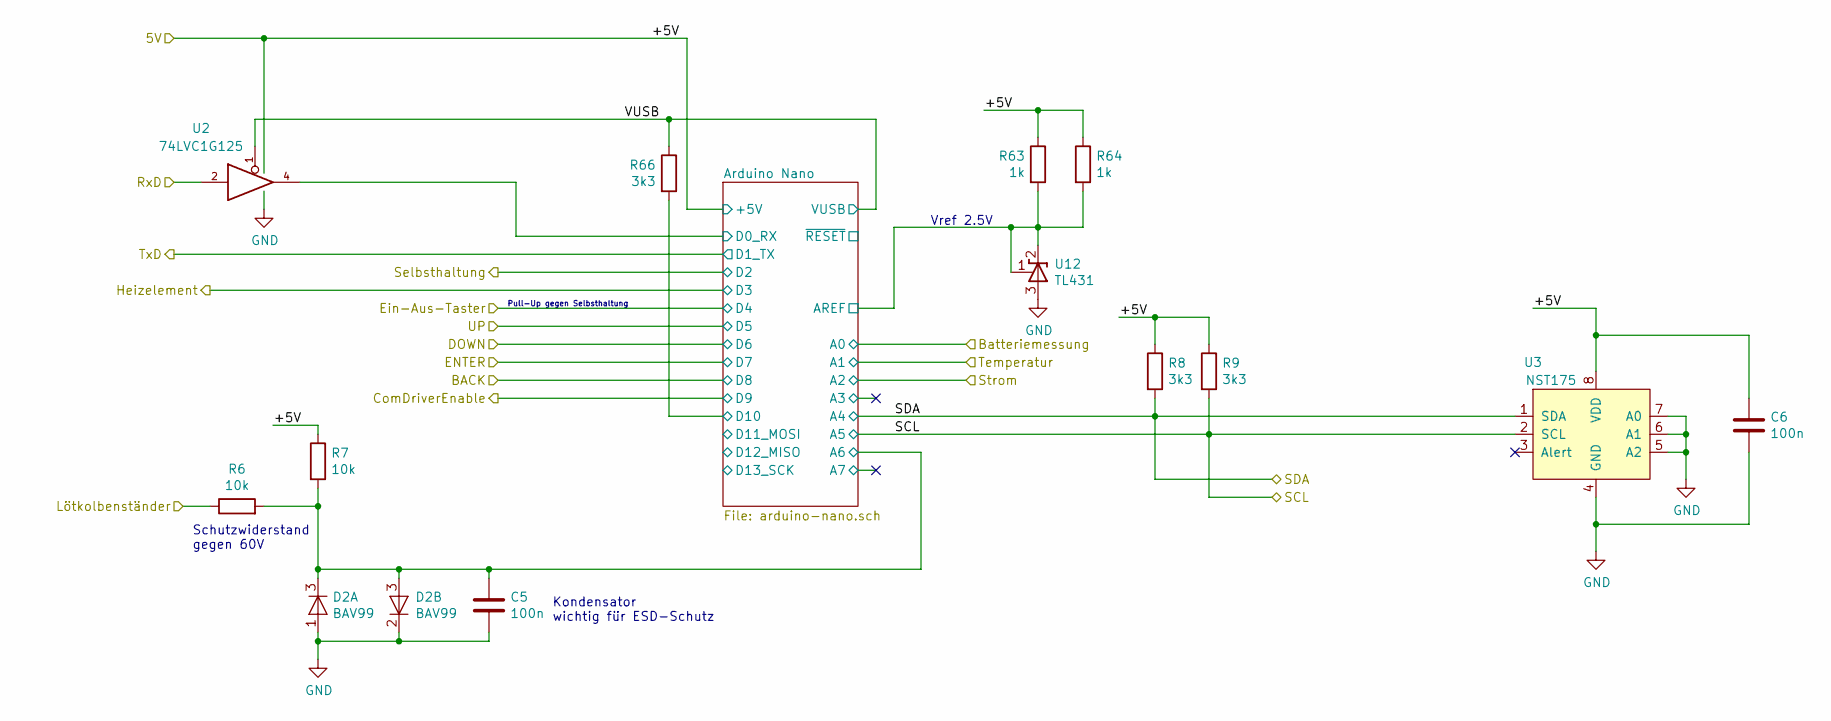
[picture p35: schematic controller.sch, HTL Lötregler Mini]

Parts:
C5, C6: 100n; C_1206_3216Metric; ManPartNr FN31X104K500PXG
D2: BAV99; SOT-23; ManPartNr BAV99
R6, R7: 10k; R_1206_3216Metric
R8, R9, R66: 3k3; R_1206_3216Metric
R63, R64: 1k; R_1206_3216Metric; ManPartNr RTT03101JTP
U2: 74LVC1G125; SOT-23-5
U3: NST175; SOIC-8_3.9x4.9mm_P1.27mm
U12: TL431; SOT-23

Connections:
+5V: C6.1, R7.1, R8.1, R9.1, R63.1, R64.1, U2.5 (VCC), U3.8 (VDD); also elsewhere on the board
/Arduino/Arduino Nano/A6: C5.1, D2.3 (K), R6.2, R7.2; also elsewhere on the board
/Arduino/Arduino Nano/AREF: R63.2, R64.2, U12.1 (REF), U12.2 (K); also elsewhere on the board
/Arduino/Arduino Nano/D0_RX: U2.4; also elsewhere on the board
/Arduino/Arduino Nano/D10: R66.2; also elsewhere on the board
/Arduino/Lötkolbenständer: R6.1; also elsewhere on the board
/Arduino/RxD: U2.2; also elsewhere on the board
/Arduino/SCL: R9.2, U3.2 (SCL); also elsewhere on the board
/Arduino/SDA: R8.2, U3.1 (SDA); also elsewhere on the board
/Arduino/VUSB: R66.1, U2.1; also elsewhere on the board
GND: C5.2, C6.2, D2.1 (A), D2.2 (K), U2.3 (GND), U3.4 (GND), U3.5 (A2), U3.6 (A1), U3.7 (A0), U12.3 (A); also elsewhere on the board

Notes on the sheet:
Pull-Up gegen Selbsthaltung
Schutzwiderstand gegen 60V
Kondensator wichtig für ESD-Schutz
Vref 2.5V

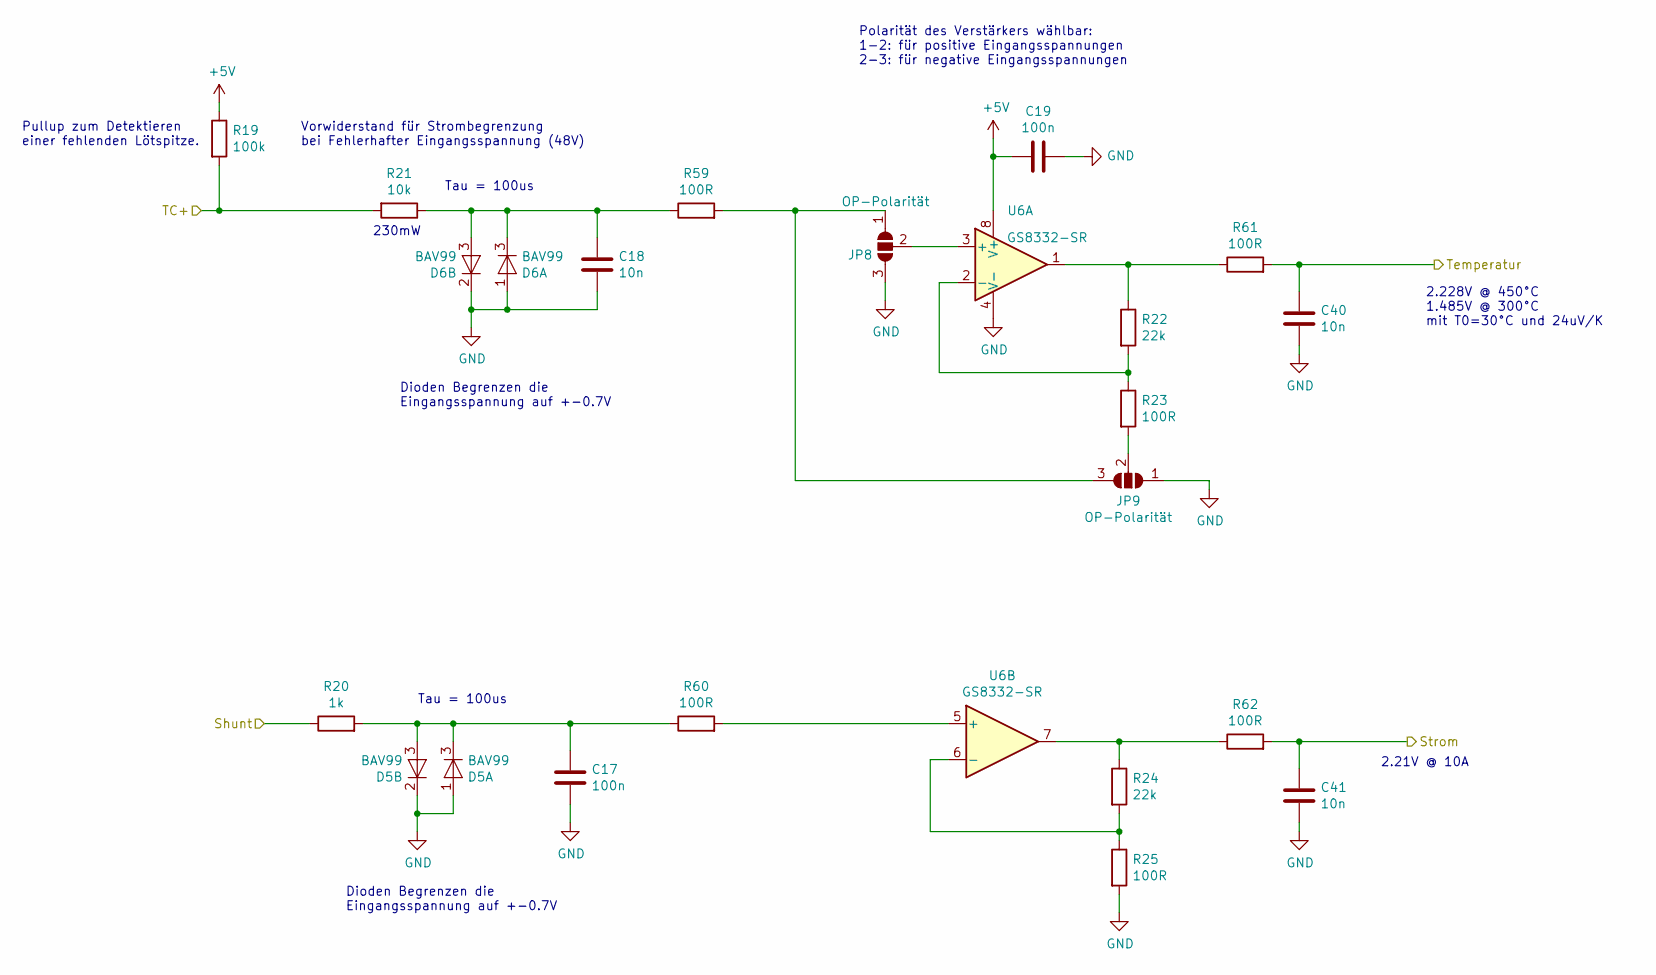
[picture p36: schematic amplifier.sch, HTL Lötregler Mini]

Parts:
C17, C19: 100n; C_1206_3216Metric; ManPartNr FN31X104K500PXG
C18, C40, C41: 10n; C_1206_3216Metric; ManPartNr FN31X103K500PXG
D5, D6: BAV99; SOT-23; ManPartNr BAV99
JP8, JP9: OP-Polarität; SolderJumper-3_P2.0mm_Open_TrianglePad1.0x1.5mm_NumberLabels
R19: 100k; R_1206_3216Metric
R20: 1k; R_1206_3216Metric; ManPartNr RTT03101JTP
R21: 10k; R_1206_3216Metric
R22, R24: 22k; R_1206_3216Metric
R23, R25, R59, R60, R61, R62: 100R; R_1206_3216Metric; ManPartNr CR1206F100RP05Z
U6: GS8332-SR; SOIC-8_3.9x4.9mm_P1.27mm; ManPartNr GS8332-SR

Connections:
+5V: C19.2, R19.1, U6.8 (V+); also elsewhere on the board
/Arduino/Strom: C41.1, R62.2; also elsewhere on the board
/Arduino/Temperatur: C40.1, R61.2; also elsewhere on the board
/Messverstärker/Shunt: R20.1; also elsewhere on the board
/Messverstärker/TC+: R19.2, R21.2; also elsewhere on the board
GND: C17.1, C18.2, C19.1, C40.2, C41.2, D5.1 (A), D5.2 (K), D6.1 (A), D6.2 (K), JP8.3 (B), JP9.1 (A), R25.2, U6.4 (V-); also elsewhere on the board
unnamed: C17.2, D5.3 (K), R20.2, R60.1
unnamed: C18.1, D6.3 (K), R21.1, R59.1
unnamed: JP8.1 (A), JP9.3 (B), R59.2
unnamed: JP8.2 (C), U6.3 (+)
unnamed: JP9.2 (C), R23.2
unnamed: R22.1, R61.1, U6.1
unnamed: R22.2, R23.1, U6.2 (-)
unnamed: R24.1, R62.1, U6.7
unnamed: R24.2, R25.1, U6.6 (-)
unnamed: R60.2, U6.5 (+)

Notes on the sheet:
Tau = 100us
Vorwiderstand für Strombegrenzung bei Fehlerhafter Eingangsspannung (48V)
Dioden Begrenzen die Eingangsspannung auf +-0.7V
Pullup zum Detektieren einer fehlenden Lötspitze.
230mW
Polarität des Verstärkers wählbar: 1-2: für positive Eingangsspannungen 2-3: für negative Eingangsspannungen
2.228V @ 450°C 1.485V @ 300°C mit T0=30°C und 24uV/K
2.21V @ 10A

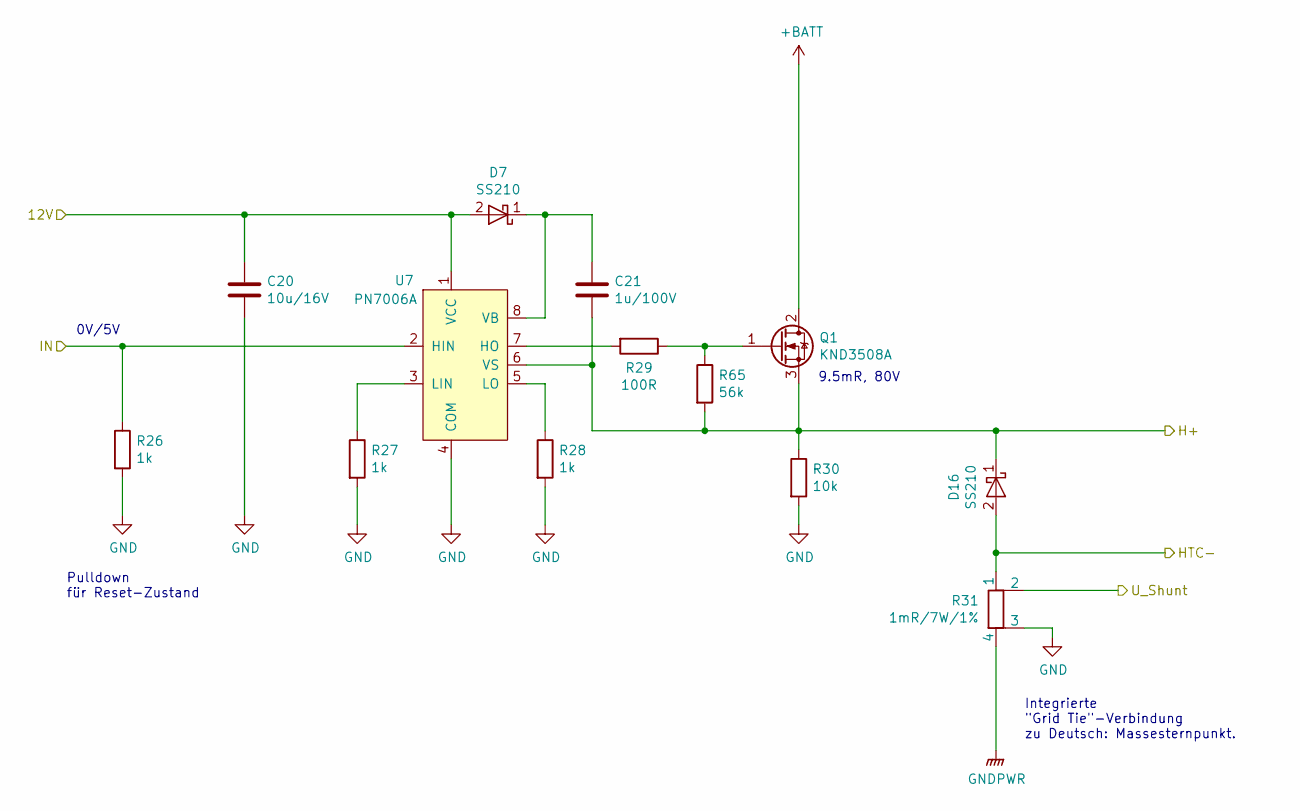
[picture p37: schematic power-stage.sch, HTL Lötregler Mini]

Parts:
C20: 10u/16V; C_1206_3216Metric; ManPartNr CL31B106KOHNNNE
C21: 1u/100V; C_1206_3216Metric; ManPartNr CC1206KKX7R0BB105
D7, D16: SS210; D_SMA_wide; ManPartNr SS210A-W
Q1: KND3508A; TO-252-2; ManPartNr KND3508A
R26, R27, R28: 1k; R_1206_3216Metric; ManPartNr RTT03101JTP
R29: 100R; R_1206_3216Metric; ManPartNr CR1206F100RP05Z
R30: 10k; R_1206_3216Metric
R31: 1mR/7W/1%; Shunt-15.2x7.6mm
R65: 56k; R_1206_3216Metric
U7: PN7006A; SOIC-8_3.9x4.9mm_P1.27mm

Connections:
+BATT: Q1.2 (D); also elsewhere on the board
/Arduino/Heizelement: R26.1, U7.2 (HIN); also elsewhere on the board
/Leistungsteil/12V: C20.1, D7.2 (A), U7.1 (VCC); also elsewhere on the board
/Leistungsteil/H+: C21.2, D16.1 (K), Q1.3 (S), R30.1, R65.2, U7.6 (VS); also elsewhere on the board
/Leistungsteil/HTC-: D16.2 (A), R31.1; also elsewhere on the board
/Messverstärker/Shunt: R31.2; also elsewhere on the board
GND: C20.2, R26.2, R27.2, R28.2, R30.2, R31.3, U7.4 (COM); also elsewhere on the board
GNDPWR: R31.4; also elsewhere on the board
unnamed: C21.1, D7.1 (K), U7.8 (VB)
unnamed: Q1.1 (G), R29.1, R65.1
unnamed: R27.1, U7.3 (LIN)
unnamed: R28.1, U7.5 (LO)
unnamed: R29.2, U7.7 (HO)

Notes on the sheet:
9.5mR, 80V
0V/5V
Integrierte "Grid Tie"-Verbindung zu Deutsch: Massesternpunkt.
Pulldown für Reset-Zustand

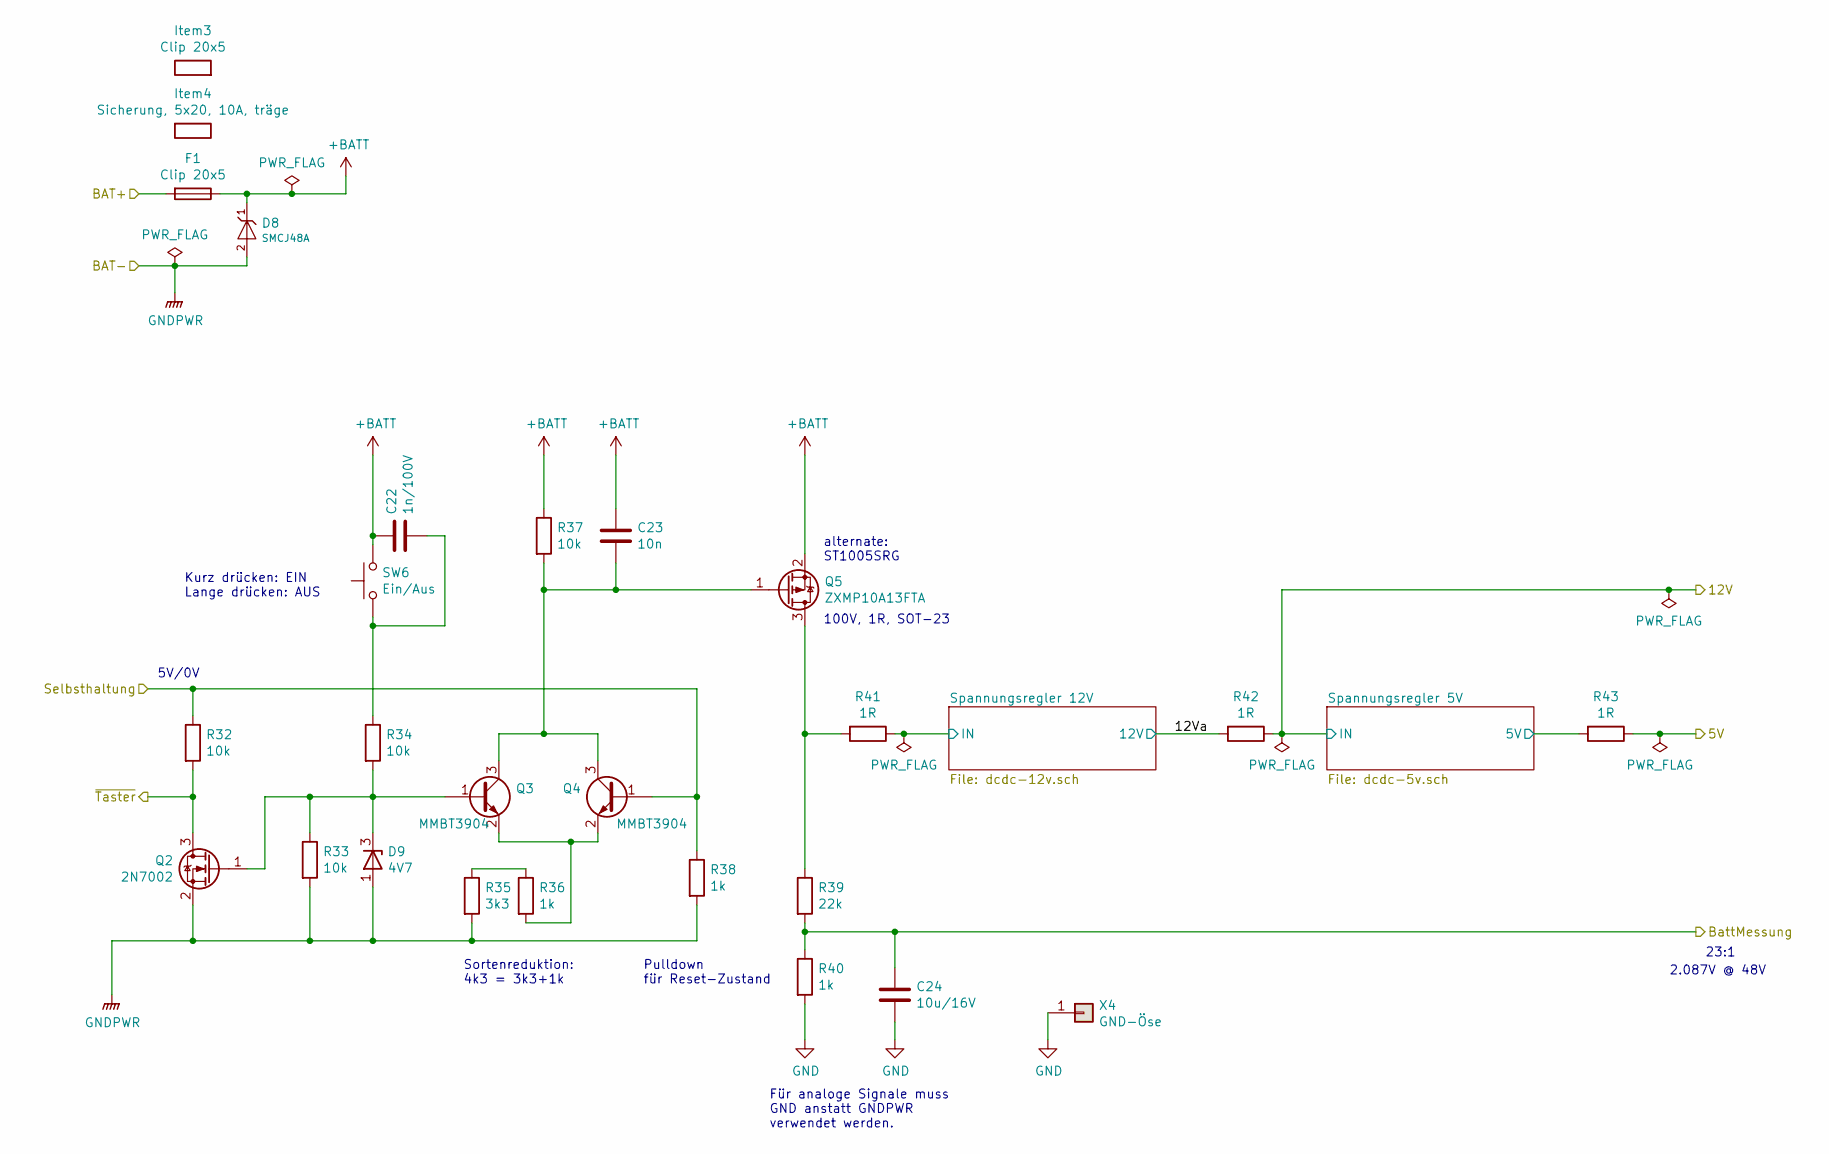
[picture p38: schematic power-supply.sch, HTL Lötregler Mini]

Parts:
C22: 1n/100V; C_1206_3216Metric; ManPartNr C1206X102K101T
C23: 10n; C_1206_3216Metric; ManPartNr FN31X103K500PXG
C24: 10u/16V; C_1206_3216Metric; ManPartNr CL31B106KOHNNNE
D8: SMCJ48A; D_SMC
D9: 4V7; SOT-23
F1: Clip 20x5; fuse-clip_20x5mm; ManPartNr LS-502
Item3: Clip 20x5; Virtual-Item; ManPartNr LS-502
Item4: Sicherung, 5x20, 10A, träge; Virtual-Item; ManPartNr 0618010.MXP
Q2: 2N7002; SOT-23; ManPartNr 2N7002
Q3, Q4: MMBT3904; SOT-23
Q5: ZXMP10A13FTA; SOT-23; ManPartNr ZXMP10A13FTA
R32, R33, R34, R37: 10k; R_1206_3216Metric
R35: 3k3; R_1206_3216Metric
R36, R38, R40: 1k; R_1206_3216Metric; ManPartNr RTT03101JTP
R39: 22k; R_1206_3216Metric
R41, R42, R43: 1R; R_1206_3216Metric
SW6: Ein/Aus; SW_Push_5.1mm_H1.5mm; ManPartNr TS-1187A-B-A-B
X4: GND-Öse; Keystone_5016

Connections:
+5V: R43.1; also elsewhere on the board
+BATT: C22.1, C23.1, D8.1 (K), F1.1, Q5.2 (S), R37.1, SW6.2; also elsewhere on the board
/Arduino/Ein-Aus-Taster: Q2.3 (D), R32.2; also elsewhere on the board
/Arduino/Selbsthaltung: Q4.1 (B), R32.1, R38.1; also elsewhere on the board
/Leistungsteil/12V: R42.1; also elsewhere on the board
/Stromversorgung/12Va: R42.2; also elsewhere on the board
/Stromversorgung/BAT+: F1.2; also elsewhere on the board
/Stromversorgung/BattMessung: C24.1, R39.2, R40.1; also elsewhere on the board
/Stromversorgung/Spannungsregler 5V/5V: R43.2; also elsewhere on the board
/Stromversorgung/Spannungsregler 12V/IN: R41.1; also elsewhere on the board
GND: C24.2, R40.2, X4.1; also elsewhere on the board
GNDPWR: D8.2 (A), D9.1 (A), Q2.2 (S), R33.2, R35.2, R38.2; also elsewhere on the board
unnamed: C22.2, R34.1, SW6.1
unnamed: C23.2, Q3.3 (C), Q4.3 (C), Q5.1 (G), R37.2
unnamed: D9.3 (K), Q2.1 (G), Q3.1 (B), R33.1, R34.2
unnamed: Q3.2 (E), Q4.2 (E), R36.2
unnamed: Q5.3 (D), R39.1, R41.2
unnamed: R35.1, R36.1

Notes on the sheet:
5V/0V
100V, 1R, SOT-23
23:1
Für analoge Signale muss GND anstatt GNDPWR verwendet werden.
Kurz drücken: EIN Lange drücken: AUS
Sortenreduktion: 4k3 = 3k3+1k
2.087V @ 48V
Pulldown für Reset-Zustand
alternate: ST1005SRG

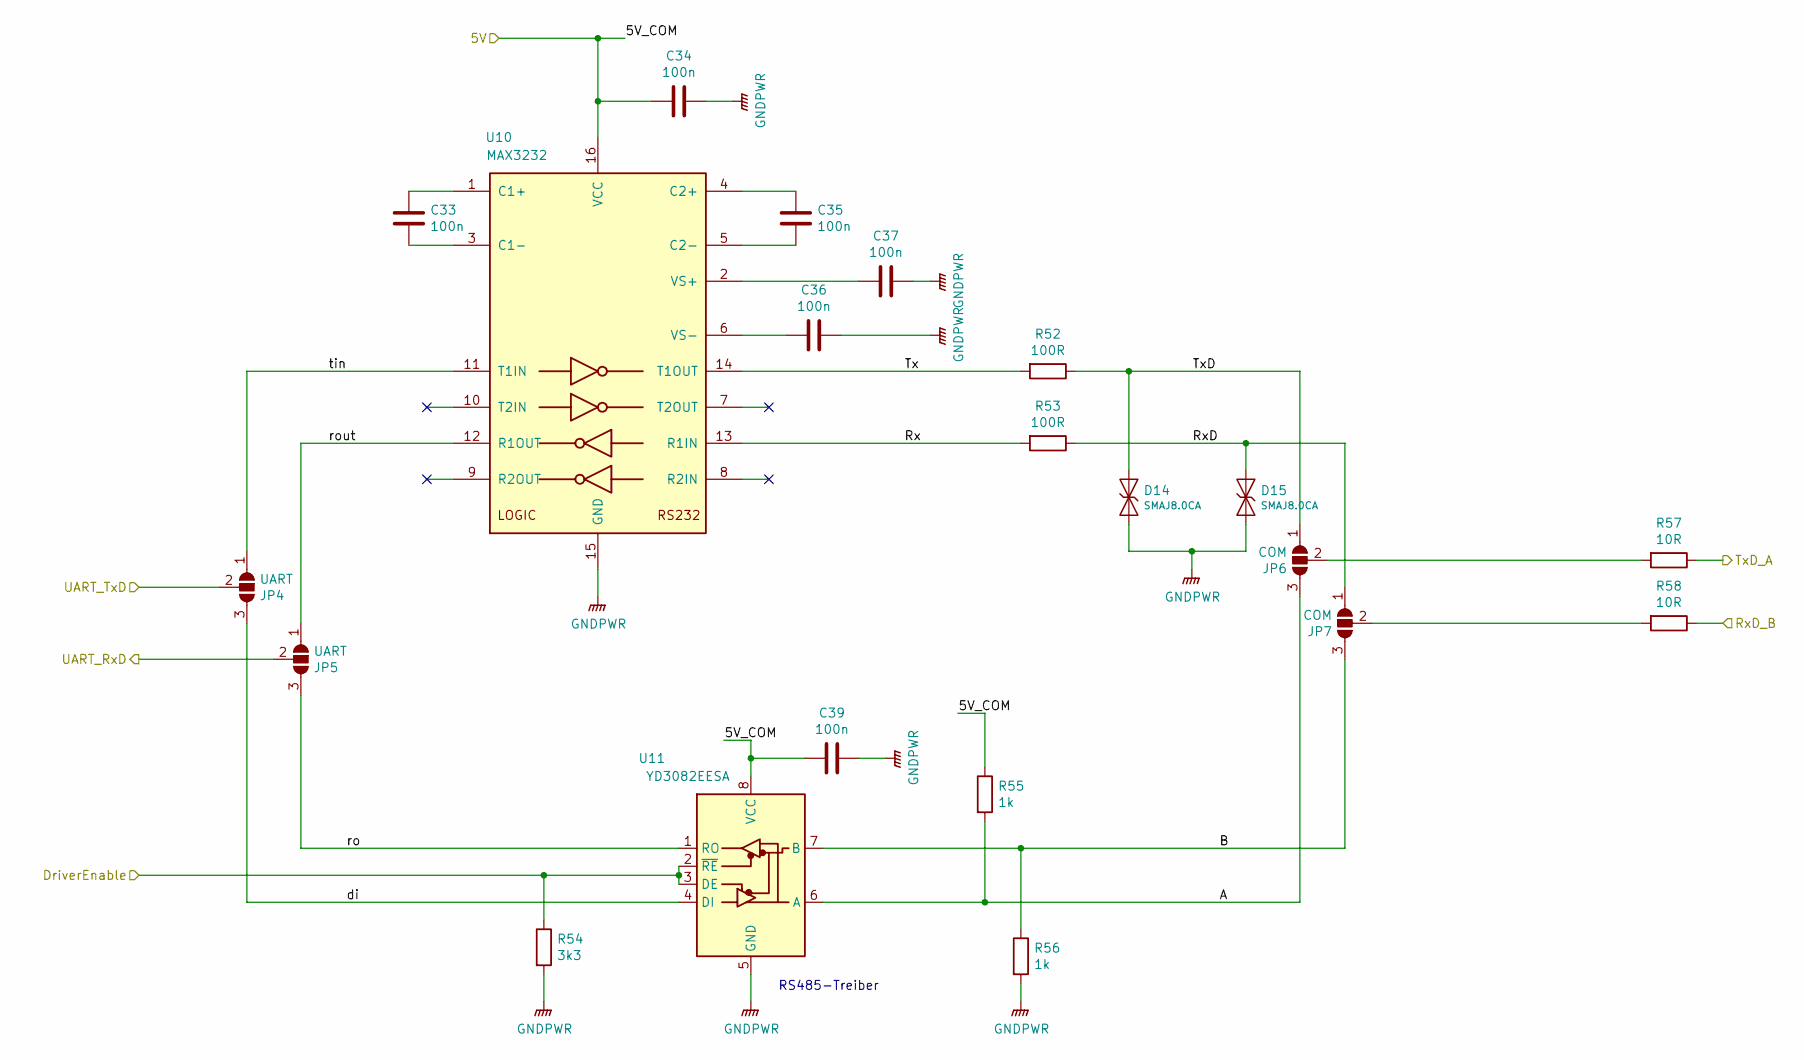
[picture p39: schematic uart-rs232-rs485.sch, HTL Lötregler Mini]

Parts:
C33, C34, C35, C36, C37, C39: 100n; C_1206_3216Metric; ManPartNr FN31X104K500PXG
D14, D15: SMAJ8.0CA; D_SMA; ManPartNr SMAJ8.0CA
JP4, JP5: UART; SolderJumper-3_P2.0mm_Open_TrianglePad1.0x1.5mm_NumberLabels
JP6, JP7: COM; SolderJumper-3_P2.0mm_Open_TrianglePad1.0x1.5mm_NumberLabels
R52, R53: 100R; R_1206_3216Metric; ManPartNr CR1206F100RP05Z
R54: 3k3; R_1206_3216Metric
R55, R56: 1k; R_1206_3216Metric; ManPartNr RTT03101JTP
R57, R58: 10R; R_1206_3216Metric
U10: MAX3232; SOIC-16_3.9x9.9mm_P1.27mm; ManPartNr MAX3232EIM/TR
U11: YD3082EESA; SOIC-8_3.9x4.9mm_P1.27mm; ManPartNr YD3082EESA

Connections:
+5V: C34.2, C39.2, R55.1, U10.16 (VCC), U11.8 (VCC); also elsewhere on the board
/Arduino/ComDriverEnable: R54.1, U11.2 (~RE), U11.3 (DE); also elsewhere on the board
/Arduino/RxD: JP5.2 (C); also elsewhere on the board
/Arduino/TxD: JP4.2 (C); also elsewhere on the board
/UART RS232/RS485/A: JP6.3 (B), R55.2, U11.6 (A)
/UART RS232/RS485/B: JP7.3 (B), R56.1, U11.7 (B)
/UART RS232/RS485/Rx: R53.2, U10.13 (R1IN)
/UART RS232/RS485/RxD: D15.1 (A), JP7.1 (A), R53.1
/UART RS232/RS485/RxD_B: R58.1; also elsewhere on the board
/UART RS232/RS485/Tx: R52.2, U10.14 (T1OUT)
/UART RS232/RS485/TxD: D14.1 (A), JP6.1 (A), R52.1
/UART RS232/RS485/TxD_A: R57.1; also elsewhere on the board
/UART RS232/RS485/di: JP4.3 (B), U11.4 (DI)
/UART RS232/RS485/ro: JP5.3 (B), U11.1 (RO)
/UART RS232/RS485/rout: JP5.1 (A), U10.12 (R1OUT)
/UART RS232/RS485/tin: JP4.1 (A), U10.11 (T1IN)
GNDPWR: C34.1, C36.1, C37.1, C39.1, D14.2 (K), D15.2 (K), R54.2, R56.2, U10.15 (GND), U11.5 (GND); also elsewhere on the board
unnamed: C33.1, U10.1 (C1+)
unnamed: C33.2, U10.3 (C1-)
unnamed: C35.1, U10.4 (C2+)
unnamed: C35.2, U10.5 (C2-)
unnamed: C36.2, U10.6 (VS-)
unnamed: C37.2, U10.2 (VS+)
unnamed: JP6.2 (C), R57.2
unnamed: JP7.2 (C), R58.2

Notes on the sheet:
RS485-Treiber

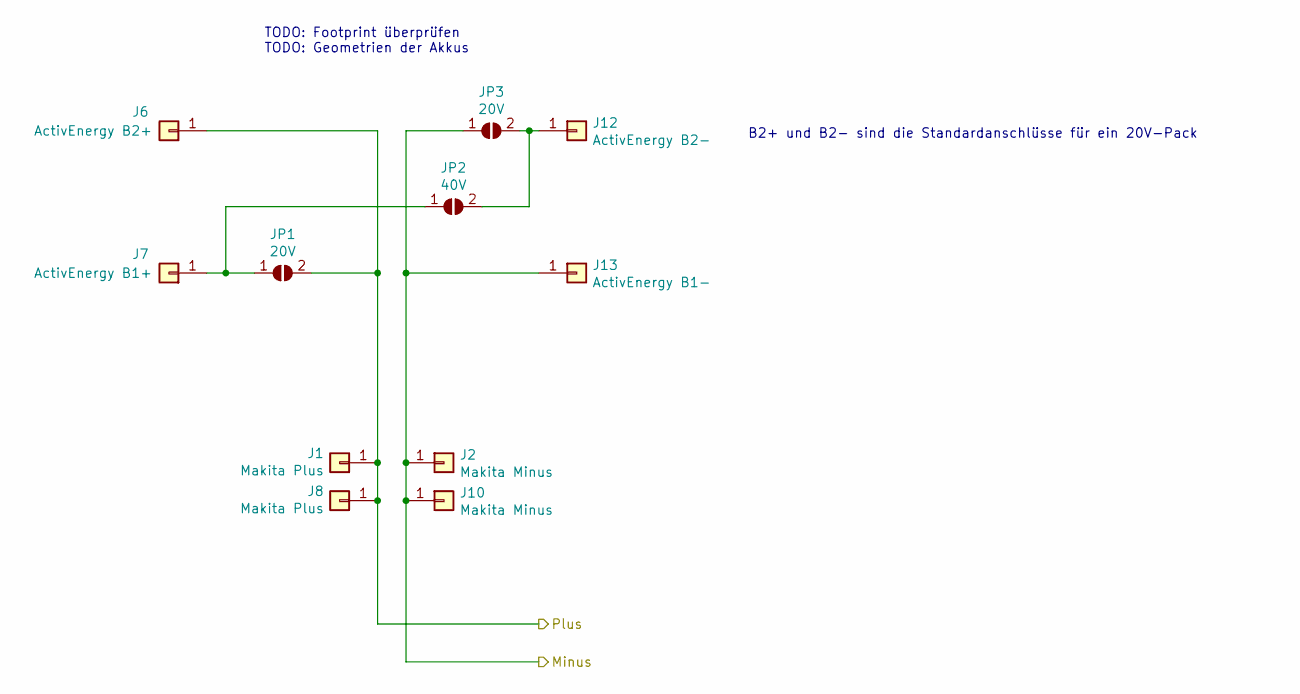
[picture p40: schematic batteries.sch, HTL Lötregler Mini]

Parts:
J1, J8: Makita Plus; Faston_Tab_6.3mm_vertical; ManPartNr 03866.A68
J2, J10: Makita Minus; Faston_Tab_6.3mm_vertical; ManPartNr 03866.A68
J6: ActivEnergy B2+; Faston_Tab_6.3mm_vertical; ManPartNr 03866.A68
J7: ActivEnergy B1+; Faston_Tab_6.3mm_vertical; ManPartNr 03866.A68
J12: ActivEnergy B2-; Faston_Tab_6.3mm_vertical; ManPartNr 03866.A68
J13: ActivEnergy B1-; Faston_Tab_6.3mm_vertical; ManPartNr 03866.A68
JP1, JP3: 20V; SolderJumper-2_2.2x8mm_Open
JP2: 40V; SolderJumper-2_2.2x8mm_Open

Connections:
/Stromversorgung/BAT+: J1.1, J6.1, J8.1, JP1.2 (B); also elsewhere on the board
GNDPWR: J2.1, J10.1, J13.1, JP3.1 (A); also elsewhere on the board
unnamed: J7.1, JP1.1 (A), JP2.1 (A)
unnamed: J12.1, JP2.2 (B), JP3.2 (B)

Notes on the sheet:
TODO: Footprint überprüfen TODO: Geometrien der Akkus
B2+ und B2- sind die Standardanschlüsse für ein 20V-Pack

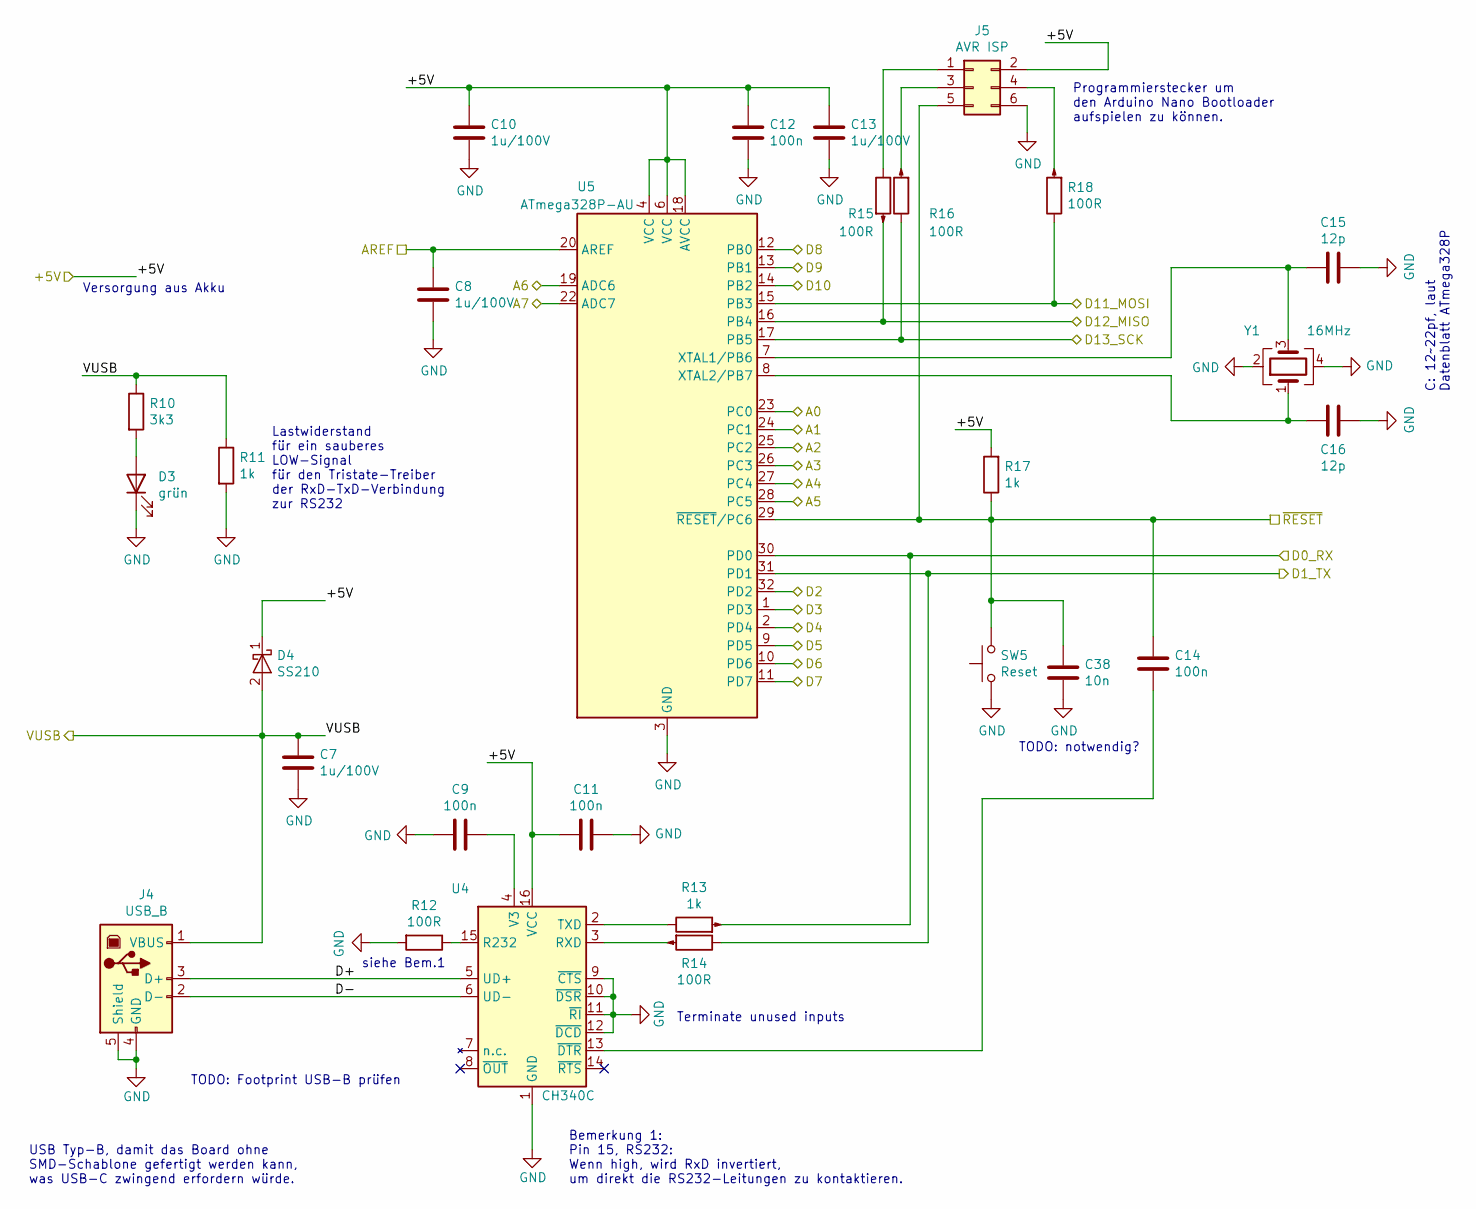
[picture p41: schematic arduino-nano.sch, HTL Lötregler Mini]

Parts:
C7, C8, C10, C13: 1u/100V; C_1206_3216Metric; ManPartNr CC1206KKX7R0BB105
C9, C11, C12, C14: 100n; C_1206_3216Metric; ManPartNr FN31X104K500PXG
C15, C16: 12p; C_1206_3216Metric; ManPartNr CC1206JRNPO9BN120
C38: 10n; C_1206_3216Metric; ManPartNr FN31X103K500PXG
D3: grün; LED_1206_3216Metric
D4: SS210; D_SMA_wide; ManPartNr SS210A-W
J4: USB_B; USB_B_Lumberg_2411_02_Horizontal; ManPartNr 921-111A1010D10200
J5: AVR ISP; IDC-Header_2x03_P2.54mm_Vertical
R10: 3k3; R_1206_3216Metric
R11, R13, R17: 1k; R_1206_3216Metric; ManPartNr RTT03101JTP
R12, R14, R15, R16, R18: 100R; R_1206_3216Metric; ManPartNr CR1206F100RP05Z
SW5: Reset; SW_Push_5.1mm_H1.5mm; ManPartNr TS-1187A-B-A-B
U4: CH340C; SOIC-16_3.9x9.9mm_P1.27mm; ManPartNr CH340C
U5: ATmega328P-AU; TQFP-32_7x7mm_P0.8mm; ManPartNr ATmega328P-AU
Y1: 16MHz; Crystal_SMD_3225-4Pin_3.2x2.5mm; ManPartNr JYXT32S4-016.00000-93C4C0

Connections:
+5V: C10.1, C11.2, C12.2, C13.1, D4.1 (K), J5.2, R17.2, U4.16 (VCC), U5.4 (VCC), U5.6 (VCC), U5.18 (AVCC); also elsewhere on the board
/Arduino/Arduino Nano/A6: U5.19 (ADC6); also elsewhere on the board
/Arduino/Arduino Nano/AREF: C8.1, U5.20 (AREF); also elsewhere on the board
/Arduino/Arduino Nano/D0_RX: R13.2, U5.30 (PD0); also elsewhere on the board
/Arduino/Arduino Nano/D10: U5.14 (PB2); also elsewhere on the board
/Arduino/Arduino Nano/D11_MOSI: R18.1, U5.15 (PB3)
/Arduino/Arduino Nano/D12_MISO: R15.2, U5.16 (PB4)
/Arduino/Arduino Nano/D13_SCK: R16.1, U5.17 (PB5)
/Arduino/Arduino Nano/D+: J4.3 (D+), U4.5 (UD+)
/Arduino/Arduino Nano/D-: J4.2 (D-), U4.6 (UD-)
/Arduino/Arduino Nano/~RESET: C14.2, C38.1, J5.5, R17.1, SW5.2, U5.29 (~RESET~/PC6)
/Arduino/BACK: U5.12 (PB0); also elsewhere on the board
/Arduino/ComDriverEnable: U5.13 (PB1); also elsewhere on the board
/Arduino/DOWN: U5.10 (PD6); also elsewhere on the board
/Arduino/ENTER: U5.11 (PD7); also elsewhere on the board
/Arduino/Ein-Aus-Taster: U5.2 (PD4); also elsewhere on the board
/Arduino/Heizelement: U5.1 (PD3); also elsewhere on the board
/Arduino/SCL: U5.28 (PC5); also elsewhere on the board
/Arduino/SDA: U5.27 (PC4); also elsewhere on the board
/Arduino/Selbsthaltung: U5.32 (PD2); also elsewhere on the board
/Arduino/Strom: U5.25 (PC2); also elsewhere on the board
/Arduino/Temperatur: U5.24 (PC1); also elsewhere on the board
/Arduino/TxD: R14.1, U5.31 (PD1); also elsewhere on the board
/Arduino/UP: U5.9 (PD5); also elsewhere on the board
/Arduino/VUSB: C7.1, D4.2 (A), J4.1 (VBUS), R10.1, R11.1; also elsewhere on the board
/Stromversorgung/BattMessung: U5.23 (PC0); also elsewhere on the board
GND: C7.2, C8.2, C9.2, C10.2, C11.1, C12.1, C13.2, C15.2, C16.2, C38.2, D3.1 (K), J4.4 (GND), J4.5 (Shield), J5.6, R11.2, R12.2, SW5.1, U4.1 (GND), U4.9 (~CTS), U4.10 (~DSR), U4.11 (~RI), U4.12 (~DCD), U5.3 (GND), U5.5 (GND), U5.21 (GND), Y1.2, Y1.4; also elsewhere on the board
unnamed: C9.1, U4.4 (V3)
unnamed: C14.1, U4.13 (~DTR)
unnamed: C15.1, U5.7 (XTAL1/PB6), Y1.3
unnamed: C16.1, U5.8 (XTAL2/PB7), Y1.1
unnamed: D3.2 (A), R10.2
unnamed: J5.1, R15.1
unnamed: J5.3, R16.2
unnamed: J5.4, R18.2
unnamed: R12.1, U4.15 (R232)
unnamed: R13.1, U4.2 (TXD)
unnamed: R14.2, U4.3 (RXD)

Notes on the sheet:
Bemerkung 1: Pin 15, RS232: Wenn high, wird RxD invertiert, um direkt die RS232-Leitungen zu kontaktieren.
siehe Bem.1
Terminate unused inputs
C: 12~~22pf, laut Datenblatt ATmega328P
Lastwiderstand für ein sauberes LOW-Signal für den Tristate-Treiber der RxD-TxD-Verbindung zur RS232
Versorgung aus Akku
USB Typ-B, damit das Board ohne SMD-Schablone gefertigt werden kann, was USB-C zwingend erfordern würde.
TODO: Footprint USB-B prüfen
Programmierstecker um den Arduino Nano Bootloader aufspielen zu können.
TODO: notwendig?

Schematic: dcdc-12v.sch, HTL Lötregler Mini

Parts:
C25: 100n/100V; C_1206_3216Metric; ManPartNr CL31B104KCFNNNE
C26: 100u/63V; CP_Elec_8x10; ManPartNr VKMD1001J101MV
C27: 33n; C_1206_3216Metric; ManPartNr TCC1206X7R333K500DT
C28: 100u/25V; CP_Elec_6.3x5.9; ManPartNr SVZ1EM101E06E00RAXXX
D10: SS210; D_SMA_wide; ManPartNr SS210A-W
D11: grün; LED_1206_3216Metric
L1: 47u/1A; L_7.3x7.3_H4.5_C216198; ManPartNr SLH0704S470MTT
R44: 100R; R_1206_3216Metric; ManPartNr CR1206F100RP05Z
R45: 30k; R_1206_3216Metric
R46, R47: 3k3; R_1206_3216Metric
U8: XL7005A; SOIC-8-1EP_3.9x4.9mm_P1.27mm_EP2.514x3.2mm_ThermalVias; ManPartNr XL7005A

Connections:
/Stromversorgung/12Va: C27.1, C28.1, L1.2, R45.1, R47.1; also elsewhere on the board
/Stromversorgung/Spannungsregler 12V/IN: C25.1, C26.1, U8.1 (VIN); also elsewhere on the board
/Stromversorgung/Spannungsregler 12V/fb: C27.2, R45.2, R46.1, U8.3 (FB)
/Stromversorgung/Spannungsregler 12V/sw: D10.1 (K), L1.1, U8.2 (SW)
/Stromversorgung/Spannungsregler 12V/~en: R44.1, U8.4 (~EN)
GND: D11.1 (K); also elsewhere on the board
GNDPWR: C25.2, C26.2, C28.2, D10.2 (A), R44.2, R46.2, U8.5 (GND), U8.6 (GND), U8.7 (GND), U8.8 (GND), U8.9 (GND); also elsewhere on the board
unnamed: D11.2 (A), R47.2

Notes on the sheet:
8...80V

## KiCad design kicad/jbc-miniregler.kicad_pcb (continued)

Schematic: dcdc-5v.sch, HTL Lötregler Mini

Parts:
C29: 100n/100V; C_1206_3216Metric; ManPartNr CL31B104KCFNNNE
C30, C32: 100u/25V; CP_Elec_6.3x5.9; ManPartNr SVZ1EM101E06E00RAXXX
C31: 33n; C_1206_3216Metric; ManPartNr TCC1206X7R333K500DT
D12: SS210; D_SMA_wide; ManPartNr SS210A-W
D13: grün; LED_1206_3216Metric
L2: 47u/1A; L_7.3x7.3_H4.5_C216198; ManPartNr SLH0704S470MTT
R48: 100R; R_1206_3216Metric; ManPartNr CR1206F100RP05Z
R49: 10k; R_1206_3216Metric
R50, R51: 3k3; R_1206_3216Metric
U9: XL7005A; SOIC-8-1EP_3.9x4.9mm_P1.27mm_EP2.514x3.2mm_ThermalVias; ManPartNr XL7005A

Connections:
/Leistungsteil/12V: C29.1, C30.1, U9.1 (VIN); also elsewhere on the board
/Stromversorgung/Spannungsregler 5V/5V: C31.1, C32.1, L2.2, R49.1, R51.1; also elsewhere on the board
/Stromversorgung/Spannungsregler 5V/fb: C31.2, R49.2, R50.1, U9.3 (FB)
/Stromversorgung/Spannungsregler 5V/sw: D12.1 (K), L2.1, U9.2 (SW)
/Stromversorgung/Spannungsregler 5V/~en: R48.1, U9.4 (~EN)
GND: D13.1 (K); also elsewhere on the board
GNDPWR: C29.2, C30.2, C32.2, D12.2 (A), R48.2, R50.2, U9.5 (GND), U9.6 (GND), U9.7 (GND), U9.8 (GND), U9.9 (GND); also elsewhere on the board
unnamed: D13.2 (A), R51.2

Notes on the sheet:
8...80V

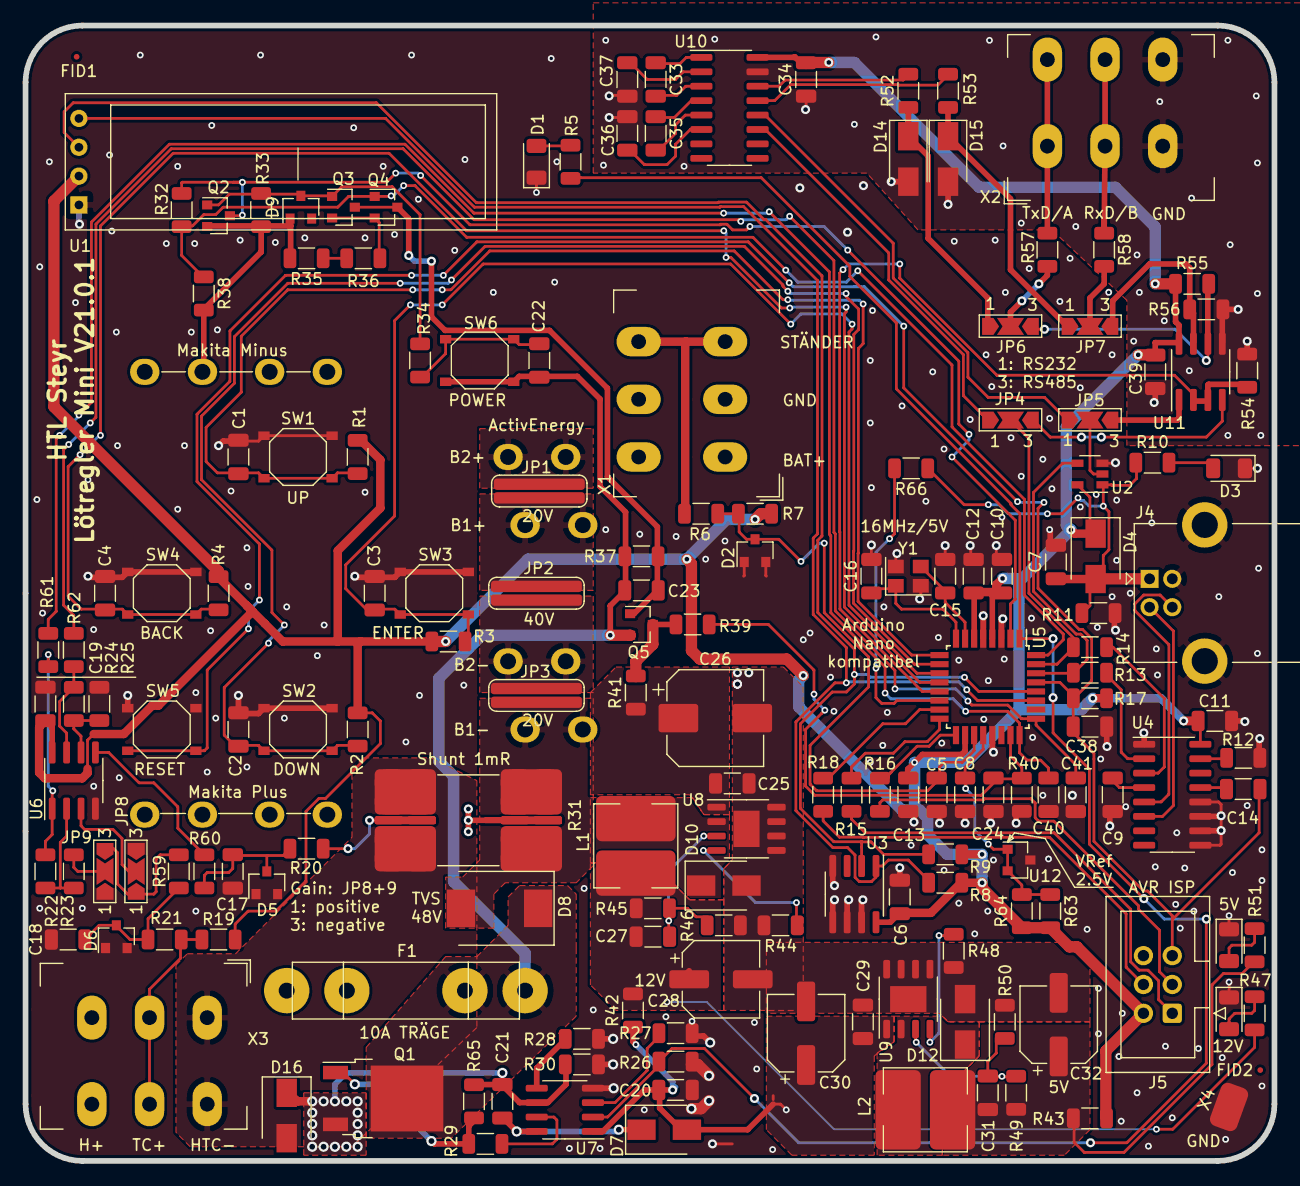
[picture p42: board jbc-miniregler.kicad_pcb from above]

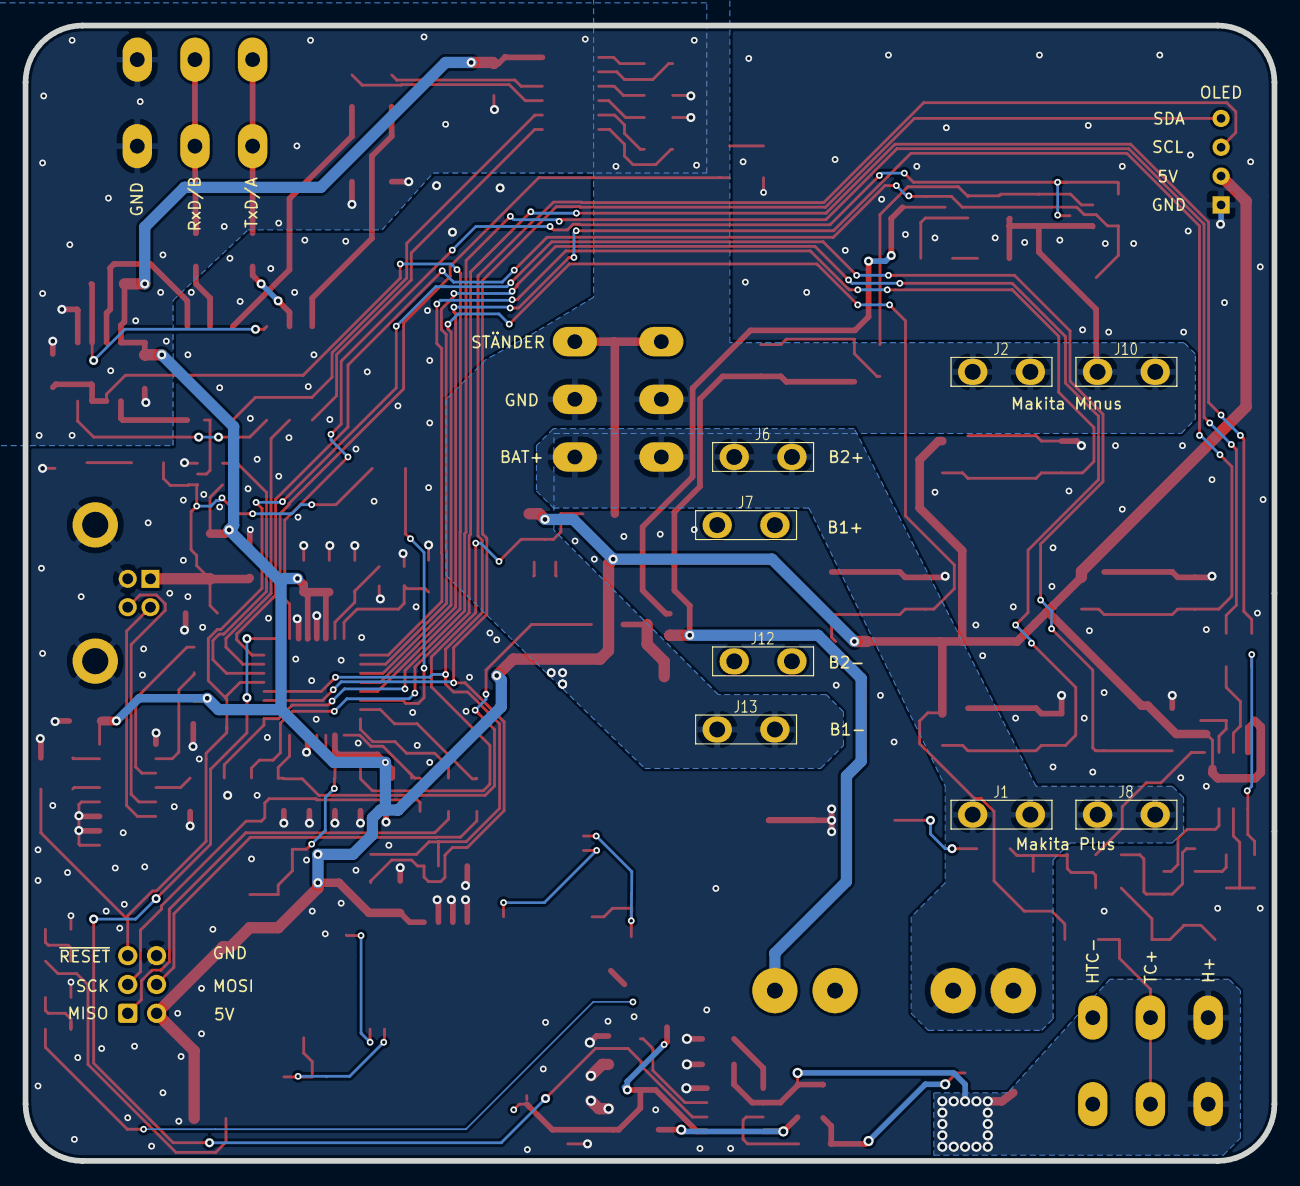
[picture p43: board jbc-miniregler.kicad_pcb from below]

Board: 2 copper layers, 110.0 x 100.0 mm, 180 parts (8 on the bottom side), 103 nets.

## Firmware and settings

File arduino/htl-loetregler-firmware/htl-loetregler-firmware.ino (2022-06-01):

#include <stdlib.h>
#include <time.h>
#include <SPI.h>
#include <Wire.h>
#include <Adafruit_GFX.h>
#include <Adafruit_SSD1306.h>
#include "button.h"


// Declaration for an SSD1306 display connected to I2C (SDA, SCL pins)
#define SCREEN_WIDTH 128 // OLED display width, in pixels
#define SCREEN_HEIGHT 32 // OLED display height, in pixels
#define OLED_RESET     -1 // Reset pin # (or -1 if sharing Arduino reset pin)
Adafruit_SSD1306 display(SCREEN_WIDTH, SCREEN_HEIGHT, &Wire, OLED_RESET);


#define PIN_Selbsthaltung   2
#define PIN_Heizelement     3
// Taster, siehe button.cpp
#define PIN_ComTreiber_Enable   9


// Externe Referenzspannung 2.51V +/-0.5%
#define PIN_AIN_UBatt       A0
#define PIN_AIN_TempSensor  A1
#define PIN_AIN_Strom       A2
// A3: unused
// A4: SDA (OLED und PCB-Temp-Sensor)
// A5: SCL (OLED und PCB-Temp-Sensor)
#define PIN_AIN_Staender    A6

#define DIVISOR 2
#define SPANNUNG_VOLL (40.0/DIVISOR)
#define SPANNUNG_LEER (32.0/DIVISOR)

#define MIT_NAMEN
#define VORNAME  "PROF."
#define NACHNAME "ZEILHOFER"


char str[20] = {0};
uint16_t tempSoll = 330;
uint16_t tempSpitze = 999;
bool standby = false;
uint32_t timeLastTempIncrease = 0;

enum Screen {BootScreen, MainScreen} activeScreen = BootScreen;

void setup() {
  pinMode(PIN_Selbsthaltung, OUTPUT);
  selbsthaltung();

  // put your setup code here, to run once:
  analogReference(EXTERNAL); // 2.51V

  Serial.begin(115200);
  delay(100);
  Serial.println("HTL LOETREGLER MINI");
  Wire.begin();

  // SSD1306_SWITCHCAPVCC = generate display voltage from 3.3V internally
  if (!display.begin(SSD1306_SWITCHCAPVCC, 0x3c, false, false)) {
    Serial.println(F("SSD1306 allocation failed"));
    for (;;); // Don't proceed, loop forever
  }

  display.clearDisplay();
  display.setCursor(10,0);
  display.setTextSize(2);
  display.setTextColor(WHITE);
  display.print("HTL STEYR");
  display.setCursor(0,31-7);
  display.setTextSize(1);
  display.print("LOETREGLER MINI V0.1");
  display.display();

  delay(1000);

#ifdef MIT_NAMEN
  nameAnzeigen();
#endif

  pinMode(PIN_Heizelement, OUTPUT);
  analogWrite(PIN_Heizelement, 3);
}

void nameAnzeigen(){
  display.clearDisplay();
  display.setCursor(0,0);
  display.setTextSize(2);
  display.setTextColor(WHITE);
  display.print(VORNAME);
  display.setCursor(0,31-14);
  display.setTextSize(2);
  display.print(NACHNAME);
  display.display();

  delay(1000);
}

void mainScreen() {
  static const int8_t UpdatePeriod = 3;
  static int8_t updateCounter = UpdatePeriod;
  // paint static objects

  if (activeScreen != MainScreen) {
    updateCounter = 0;
    activeScreen = MainScreen;
    display.clearDisplay();

    // Grad Celsius groß
    display.setTextSize(3);
    display.setCursor(60, 1);
    display.print("C");
    display.drawCircle(57, 3, 2, WHITE);
    display.drawCircle(57, 3, 3, WHITE);


    // Watt
    display.setTextSize(1);
    display.setCursor(2 + 3 * 6, 24);
    display.print("W");

    // Grad Celsius klein
    display.setTextSize(1);
    display.setCursor(59, 24);
    display.print("C");
    display.drawCircle(56, 25, 1, WHITE);

    // Volt
    display.setTextSize(1);
    display.setCursor(96 + 4 * 6, 18);
    display.print("V");

    // Batterieumrandung
    display.drawRect(96, 3, 27, 11, WHITE);
    display.drawRect(122, 6, 3, 5, WHITE);
  }

  // CLEAR Dynamic Objects
  {
    updateCounter--;
    if (updateCounter <= 0) {
      display.fillRect(2, 1, 3 * 18 - 3, 21, BLACK); // Ist-Temp.
    }
    display.fillRect(2, 24, 3 * 6 - 1, 7, BLACK); // Leistung
    display.fillRect(36, 24, 3 * 6 - 1, 7, BLACK); // Soll Temperatur
    display.fillRect(96, 18, 4 * 6 - 1, 7, BLACK); // Batterie Spannung
    display.fillRect(98, 5, 2 * 12 - 1, 7, BLACK); // Batterie Zustand
  }


  // Draw/Print Dynamic Objects:
  {
    // Ist Temperatur
    //tempSpitze = temperaturSpitze(); 
    // tempSpitze wird aus regler() übernommen
    static int32_t sumTemp = 0;
    sumTemp += tempSpitze;
    if (updateCounter <= 0) {
      display.setCursor(2, 1);
      display.setTextSize(3);
      sprintf(str, "%d", uint16_t(sumTemp / UpdatePeriod));
      display.print(str);
      sumTemp = 0;
    }

    // Soll Temperatur


    display.setCursor(36, 24);
    display.setTextSize(1);
    sprintf(str, "%d", uint16_t(tempSoll));
    display.print(str);


    // Leistung
    float power = 125;
    display.setCursor(2, 24);
    display.setTextSize(1);
    sprintf(str, "%d", uint16_t(power));
    display.print(str);

    // Batteriespannung
    float uBatt = spannungBatterie();
    display.setTextSize(1);
    sprintf(str, "%3d", uint16_t(uBatt * 10));
    display.setCursor(96, 18);
    display.print(str[0]);
    display.setCursor(96 + 6, 18);
    display.print(str[1]);
    display.setCursor(96 + 12, 18);
    display.print(".");
    display.setCursor(96 + 18, 18);
    display.print(str[2]);

    uint8_t z = (batterieZustand() * 12 + 50) / 100; // umrechnen auf 12 Skalenstriche
    for (int x = 0; x < z; x++) {
      display.drawLine(x * 2 + 98, 5, x * 2 + 98, 11, WHITE);
    }
  }

  if (updateCounter <= 0) {
    updateCounter = UpdatePeriod;
  }
  display.display();
}

// 0...100%
uint8_t batterieZustand() {
  int32_t ret = constrain(
                  100.0/(SPANNUNG_VOLL-SPANNUNG_LEER)*(spannungBatterie()-SPANNUNG_LEER), 
                  0, 100);
  Serial.println(ret);
  return ret;
}

void regler(){
  float stromMesswert;

  tempSpitze = temperaturSpitze();
  if ((!standby && (tempSpitze < tempSoll)) ||
      (standby && (tempSpitze < 150))) {
    analogWrite(PIN_Heizelement, 250); // nicht 100% PWM (=255), damit der Bootstrap-Kondensator nachladen kann!
  }
  if(tempSpitze+80 < tempSoll){
    // beschleunigtes Heizen
    delay(100);
  }else{
    delay(10); // max. 10ms durchgehend Heizen
  }
  stromMesswert = strom();
  analogWrite(PIN_Heizelement, 0);
}

void tasterAuswertung(){
  buttons.readAll();
  if (buttons.up->getEvent() == Button::PressedEvent) {
    tempSoll += 10;
    timeLastTempIncrease = millis();
  }
  if (buttons.down->getEvent() == Button::PressedEvent) {
    tempSoll -= 10;
  }
  if (buttons.back->getEvent() == Button::PressedEvent) {
    standby = true;
  }
  if (buttons.enter->getEvent() == Button::PressedEvent) {
    standby = false;
  }
  if ((buttons.power->getEvent() == Button::PressedEvent) && millis() > 1000) {
    abschalten();
  }
  tempSoll = constrain(tempSoll, 50, 450);
}

void loop() {
  mainScreen();
  regler();
  tasterAuswertung();
  selbsthaltung();
  zeitabschaltung();
  uebertemperaturwaechter();
}

// Temperaturen über 330°C werden nur 1 Minute zugelassen
// Dient dem Schutz des 3D-gedruckten Griffstücks
void uebertemperaturwaechter()
{
  if(millis() > timeLastTempIncrease+60000UL && tempSoll > 330){
    tempSoll = 330;
  }
}

float spannungMessen(uint8_t pin) {
  float u = analogRead(pin);
  u = u * 2.51 / 1024;
  return u;
}

// muss periodisch aufgerufen werden!
void selbsthaltung() {
  if (millis() < 10000 || spannungBatterie() > SPANNUNG_LEER) { // für 40V-Akku: 30V, für 20V-Akku: 15V
    digitalWrite(PIN_Selbsthaltung, HIGH);
  } else {
    Serial.println("Unterspannung");
    abschalten();
  }
}

float temperaturSpitze() {
  return spannungMessen(PIN_AIN_TempSensor) / 221 / 24e-6 + 30; // in °C
}

float spannungBatterie() {
  return spannungMessen(PIN_AIN_UBatt) * 23;
}

float strom() {
  return spannungMessen(PIN_AIN_Strom) / 221 / 0.001;
}

// muss periodisch aufgerufen werden
void zeitabschaltung() {
  if (millis() / 1000 / 60 > 10) {
    Serial.println("Zeitabschaltung");
    abschalten();
  }
}

// doesn't return any more, except, if powered by USB
void abschalten() {
  if(digitalRead(10) == HIGH){
    digitalWrite(PIN_Selbsthaltung, LOW);
    return;
  }
  display.fillRect(0, 0, 128, 32, BLACK);
  display.setTextSize(1);
  display.setCursor(0, 0);
  display.print("ACHTUNG HEISS");
  display.setCursor(0, 10);
  display.print("AUSKUEHLEN...");
  display.display();
  
  while (temperaturSpitze() > 60 && temperaturSpitze() < 490){
    display.fillRect(0,20,128,10, BLACK);
    display.setCursor(0,20);
    sprintf(str, "%d", uint16_t(temperaturSpitze()));
    display.print(str);
    display.display();
    delay(1000);
  }
  
  digitalWrite(PIN_Selbsthaltung, LOW);
  while(1);
}

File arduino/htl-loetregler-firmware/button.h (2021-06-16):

#ifndef BUTTON_H
#define BUTTON_H

#include <stdint.h>
#include <Arduino.h>

#define PIN_Taster_EinAus   4
#define PIN_Taster_Up       5
#define PIN_Taster_Down     6
#define PIN_Taster_Enter    7
#define PIN_Taster_Back     8

class Button
{
public:
  uint8_t pin;

  Button(uint8_t dummy);


  uint32_t tLastPressed;
  uint32_t tLastReleased;
  enum State{Pressed, Released} state;
  enum Event{NoEvent, PressedEvent, ReleasedEvent};

  static const int32_t T_Bounce = 20;

  State read();
  Event getEvent(); // clears the event state
  Event peekEvent(); // returns event without clearing it
  void clearEvents();

private:
   Event event = NoEvent;
};

class Buttons
{
public:
    Buttons();
    void readAll();
    void clearAllEvents();

    Button* up;
    Button* down;
    Button* enter;
    Button* back;
    Button* power;
};

extern Buttons buttons;

#endif // BUTTON_H

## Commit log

2021-05-02 Erste Schaltplanversion, BOM ist noch fertigzustellen
    [amplifier.sch, controller.sch, dcdc-12v.sch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]
2021-05-02 BOM ist nun fast fertig
    [amplifier.sch, controller.sch, dcdc-12v.sch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]
2021-05-04 BOM Fertig, 3D auch fast fertig. Ein paar Footrpints fehlen noch.
    [amplifier.sch, arduino-nano.sch, batteries.sch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]
2021-05-07 kleinere Updates im Schaltplan
    [amplifier.sch, arduino-nano.sch, controller.sch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]
2021-05-07 Reviews und ein paar Verbesserungen
    [arduino-nano.sch, jbc-miniregler.kicad_pcb, jbc-miniregler.sch]
2021-05-18 um Option RS485 erweitert
    [batteries.sch, controller.sch, jbc-miniregler.sch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]
2021-05-28 WIP Layout, TODO: DRC
    [arduino-nano.sch, batteries.sch, dcdc-12v.sch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]
2021-05-28 DRC clear
    [jbc-miniregler.kicad_pcb]
2021-05-28 Layout Fertig, TODOs: Beschriftungen fertig stellen, ...
    RS485 TVS-Diode
    [dcdc-12v.sch, dcdc-5v.sch, jbc-miniregler.kicad_pcb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]
2021-05-29 OPV-Polaritätsoption, Zusatzfilter und Strombegrenzung
    [amplifier.sch, arduino-nano.sch, controller.sch]
2021-05-29 vor "update all footprints", FP-Lib Version V5.10
    [jbc-miniregler.kicad_pcb]
2021-05-29 Neu: Spannungsreferenz TL431, Laout Fertig, TODO: Labels
    [amplifier.sch, controller.sch, jbc-miniregler.kicad_pcb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]
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2021-06-09 Griffstück Design und elastische Durchbiegung
    [griffstück.FCStd]
2021-06-11 Neues Federkontaktdesign by Tobias Mit.
    [griffstück.FCStd]
2021-06-14 Federkontakte: Design v1 thoretisch fertig, Tiefziehform noch in Arbeit
    [griffstück.FCStd, tiefziehform.FCStd, tiefziehform_A_matrizze_v1.stl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]
2021-06-15 Buchsenleist für OLED hinzugefügt
    [jbc-miniregler.sch]
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2021-06-17 Hardware-Anpassungen bei Inbetriebnahme und Firmwareaktualisierung
    [amplifier.sch, power-stage.sch, power-supply.sch]
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2021-06-21 Griffstück, erste 2 prototypen v0.01 und v0.03 gedruckt, TODO...
    Heizung muss gegenüber Sensor voreilend sein.
    Gatetreiber ist beim Umstecken drauf gegangen.
    [griffstück.FCStd, griffstück_oben_v0.0.1.3mf, griffstück_oben_v0.0.1.stl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]
2021-06-21 Tiefzieform für Laserbleche optimiert
    postcommit
    [griffstück_v0.0.3.3mf, tiefziehform.FCStd, tiefziehform_A_matrizze_v2.stl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]
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2021-06-23 Gehäuseboden v0 für ActivEnergy
    [gehäuse-boden_v0.stl, lötregler-gehäuse.FCStd]
2021-06-23 Batteriearrektierung abgedeckt, USB-Ausschnitt optimiert
    [lötregler-gehäuse.FCStd]
2021-06-24 gehäuse wand und deckel v1
    [lötregler-gehäuse-boden_v1.stl, lötregler-gehäuse-boden_v2.stl, lötregler-gehäuse-deckel_v1.stl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]
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2021-07-02 Bugfix: Schottky-Diode im Schaltplan
    [jbc-miniregler.kicad_pcb, power-stage.sch]
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2021-07-05 Prusa Gehäusewand v2 nun mit Brim
    [lötregler-gehäuse-wand_v2.3mf]
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2021-09-22 wip, bugfixes für v21.0.1
    [amplifier.sch, arduino-nano.sch, batteries.sch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]
2021-09-29 Workaround zu Isssue#7, USB Bootproblem
    [controller.sch, jbc-miniregler.kicad_pcb, power-stage.sch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]
2021-10-09 BOM aktualisiert, Zenerdiode: Pinout IPC-konform gestaltet, ...
    siehe https://gitlab.com/kicad/libraries/kicad-symbols/-/issues/3157
    [amplifier.sch, arduino-nano.sch, batteries.sch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]
2021-10-09 Überdeckende Footprints noch auseinander gerückt, ...
    HTML-Bom Export und Gerber-Export, 40 Stück bestell bei MulitCB
    [jbc-miniregler-B_Cu.gbr, jbc-miniregler-B_Mask.gbr, jbc-miniregler-B_SilkS.gbr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]
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2021-11-24 zugentlastung und blindstopfen, Griffstück vereinfacht, TODO...
    Griffstück 6-Eckig gestalten, damit es sauber gedruckt werden kann.
    [blindstopfen_v1.3mf, blindstopfen_v1.stl, griffstück.FCStd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]
2021-11-27 Berner Batterie, Deckel v2, Boden v3
    [berner-18v.3mf, berner-18v_deckel.stl, berner-18v_hauptteil.stl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]
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2021-11-27 Griffstück, erster Prototyp V2
    [endring_v2.stl, fingerkuppenring_v2.1.stl, griffstück_halbschale-hex_v2.stl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]
2021-11-27 Griffstück, kleine Nachbesserung, TODO: STL-Export
    [griffstück_v2.FCStd]
2021-11-27 Griffstück V2.1 inkl. STL
    [endring_v2.1.stl, fingerkuppenring_v2.2.stl, griffstück_isolator_htc-_h+_v2.1.stl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]
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2022-02-06 Batterieschuh LUX Tools 20V, 1.5Ah
    [LUX Tools 20V-1.5Ah, Deckel v1.stl, LUX Tools 20V-1.5Ah, Schuh v1.stl, LUX Tools 20V-1.5Ah.FCStd]
2022-02-07 3D: Griffstück Komplettset, Makita V3, Readme und Changelog
    [Makita_Schuh_v1.stl, Makita_Schuh_v2.stl, Makita_Schuh_v3.stl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]
2022-02-07 Kleine Anpassungen in KiCad-SCH und Firmware
    [arduino-nano.sch, jbc-miniregler.sch, power-supply.sch]
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2022-04-04 ordner struktur in 3D verbessert
    [ActiveEnergy_Schuh_v2.stl, LUX Tools 20V-1.5Ah, Deckel v1.stl, LUX Tools 20V-1.5Ah, Schuh v1.stl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]
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2022-06-01 Batterie: Bosch Professional 18V
    [bosch-professional-batterieschuh.FCStd, bosch-professional-batterieschuh_deckel_v1.stl, bosch-professional-batterieschuh_v1.stl]
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2022-06-26 Auto stash before merge of "main" and "origin/main"
    [fingerkuppenring_v2.3.stl]
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2022-06-27 Makita Boden, v4: Abstand der Batteriekontakte korrigiert auf 39mm
    [lötregler-gehäuse-boden_v4_makita.stl, lötregler-gehäuse.FCStd]
2022-06-27 LUX Tools 2Ah, V1
    [lux-tools-2Ah_batterieschuh.FCStd, lux-tools-2Ah_batterieschuh_deckel_v1.stl, lux-tools-2Ah_batterieschuh_v1.stl]
2022-06-27 LUX Tools 2Ah, Maße wesentlich korrigiert, V2
    [lux-tools-2Ah_batterieschuh.FCStd, lux-tools-2Ah_batterieschuh_deckel_v2.stl, lux-tools-2Ah_batterieschuh_v2.stl]
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2022-06-27 kleinere Updates der 3D Files
    [fingerkuppenring_v2.3.stl, griffstück_v2.FCStd, lux-tools-2Ah_batterieschuh_deckel_v2.stl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]
2022-10-12 LUX Tools nun endlich fertig
    [lux-tools-2Ah_batterieschuh.FCStd, lux-tools-2Ah_batterieschuh_v3.stl]
2022-11-09 Zugentlastung V1.4, etwas schwergängiger und länger gemacht
    [taster.stl, taster_v2.stl, zugentlastung.FCStd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]
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2023-02-15 Verbesserter 3D-Druck der Griffschale rund für Polycarbonat
    [griffstück_halbschale-rund_v2_Polycarbonat.3mf]
